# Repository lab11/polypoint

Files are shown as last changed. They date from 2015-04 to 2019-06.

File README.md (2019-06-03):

PolyPoint
=========

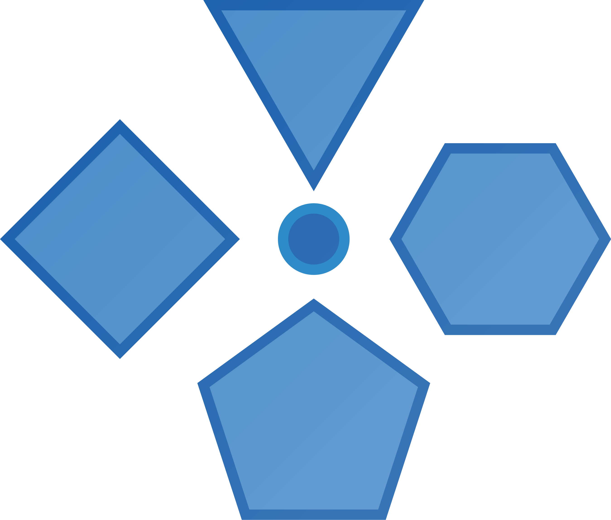
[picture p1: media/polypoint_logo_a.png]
PolyPoint


PolyPoint is a system for using ultra-wideband RF time-of-flight ranging to perform indoor localization.
It incorporates the DecaWave DW1000 for UWB packet transmission and timestamping
into a solder-on module that provides node-to-node ranges over an I2C interface.

Name
----

The name PolyPoint comes from the use of many polygons and shapes in the prototype design and the
desire to pinpoint where users are with the system.

Git Clone
---------

When cloning this repository, be absolutely sure to do

    git clone --recursive https://github.com/lab11/polypoint.git
    
so that you get the submodules as well. All of the supporting
libraries and build tools are in submodules for the various
hardware platforms used in this project.

Hardware
--------

The PolyPoint system is composed of several hardware pieces. At the core is the
TriPoint module which is a 1.25" on a side triangle that encompasses all of the
core ranging hardware and software. TriPoint has castellated edges and can be
soldered on to a carrier board, effectively as a ranging IC. TriTag is one such
carrier board designed to be the tag in the ranging system. It includes the
UWB antennas and a Bluetooth Low Energy radio plus a battery charging circuit.
TriTag is able to provide ranges to a mobile phone application.

### TriPoint

TriPoint includes the following components:

- DecaWave DW1000 UWB radio
- STM32F031G6U6 MCU
- RF switch

The MCU contains all the necessary code to run the DW1000 and the ranging
protocol.

### TriTag

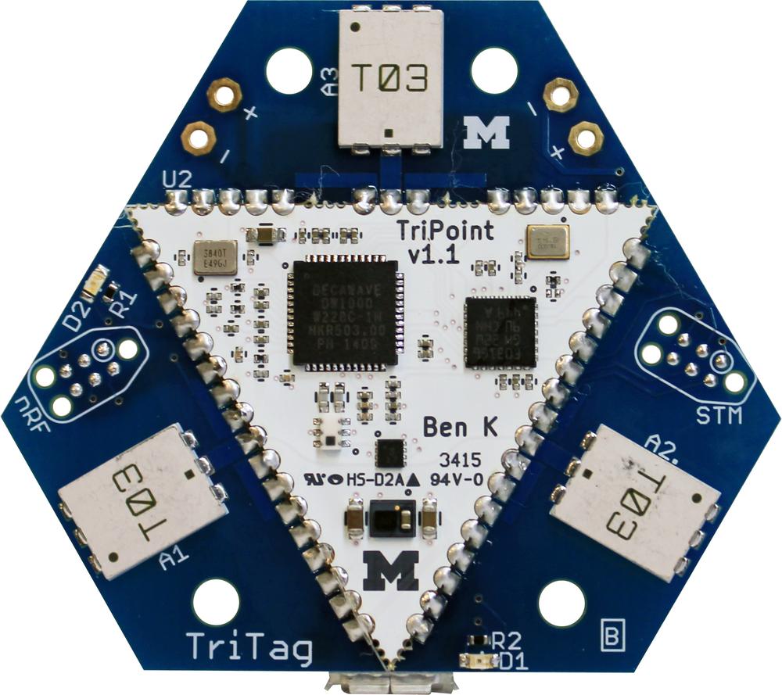
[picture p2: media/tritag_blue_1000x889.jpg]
TriTag
  

TriTag includes:

- The TriPoint module
- 3 UWB antennas
- nRF51822 BLE radio
- 3.3 V LDO
- Li-ion battery charger

TriTag is designed to be the tag to be localized in the system and connected
to a smartphone.

### TriDev

TriDev is a breakout and testing board for the TriPoint module.
It contains the same BLE hardware as TriTag, but also adds an FTDI
chip for issuing I2C commands over USB.

Software
--------

PolyPoint contains many software layers that run at various levels of
the system.

#### TriPoint

The core firmware that makes the drop-in TriPoint module work
includes all of the logic to implement two way ToF ranging
on top of the DecaWave DW1000 UWB radio. The firmware architecture
supports multiple "applications", or ranging algorithms, that can
be selected at runtime.

#### TriTag

The TriTag code implements a BLE application
that uses the TriPoint module as an I2C device and prov
a BLE service. It puts the TriTag hardware into TAG mode
and provides ranges over a BLE characteristic. 

#### Phone and BLE

The tools in the `/phone` directory interact with TriTag and read data
across the BLE interface.

----

## Academic Publications

The PolyPoint project has led to two academic publications, and an invited talk at HotWireless'16.
If you are interested in the theory behind the ranging protocol, please check out our publications:

 - **[SurePoint: Exploiting Ultra Wideband Flooding and Diversity to Provide Robust, Scalable, High-Fidelity Indoor Localization.](http://lab11.eecs.berkeley.edu/content/pubs/kempke16surepoint.pdf)** Benjamin Kempke, Pat Pannuto, Bradford Campbell, and Prabal Dutta. Proceedings of the 14th ACM Conference on Embedded Networked Sensor Systems (SenSys’16).
 - **[PolyPoint: Guiding Indoor Quadrotors with Ultra-Wideband Localization.](http://lab11.eecs.berkeley.edu/content/pubs/kempke15polypoint.pdf)** Benjamin Kempke, Pat Pannuto, and Prabal Dutta. 2015 ACM Workshop on Hot Topics in Wireless (HotWireless’15).
 
If you use PolyPoint or its derivatives, please use the following citation:

```bibtex
@inproceedings{kempke16surepoint,
	title = {{SurePoint}: Exploiting Ultra Wideband Flooding and Diversity to Provide Robust, Scalable, High-Fidelity Indoor Localization},
	booktitle = {Proceedings of the 14th ACM Conference on Embedded Networked Sensor Systems},
	series = {SenSys'16},
	year = {2016},
	month = {11},
	location = {Stanford, CA, USA},
	conference-url = {http://sensys.acm.org/2016/},
	author = {Kempke, Benjamin and Pannuto, Pat and Campbell, Bradford and Dutta, Prabal},
}
```

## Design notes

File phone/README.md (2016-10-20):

BLE Apps
========

This folder contains code for connecting to the BLE services provided
by the hardware.

tritag-summon
-------------

App for summon on mobile phones. See the readme in the folder.

tritag.js
---------

This is a script that runs with Node.js to get range estimates
from the TriTag device.

To use:

1. Install [Node.js](https://nodejs.org/en/download/)
2. Install noble:

        npm install noble

3. Run the script

        sudo node ./tritag.js

--------

The app can also be configured to post locations to a RESTful endpoint by providing a URL.
The `generate_test_data.js` provides simulation data for testing.

The packet format is:
```json
{
    "_meta": {
        "received_time":"2016-10-13T00:21:28.647Z",
        "device_id":"c0:98:e5:45:00:01",
        "device_type":"surepoint_tag"
        },
    "x":6.825641556121154,
    "y":7.267745259210209,
    "z":1.818158319382718
}
```

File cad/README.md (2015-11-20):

CAD Models
==========

A few designs including a case for TriTag.

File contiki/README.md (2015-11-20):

Deprecation Notice
==================

This folder is deprecated.

The original PolyPoint system as deployed for the 2015 Indoor Localization Competition
and evaluated for HotWireless'15 used this software. We have now moved away from the
2538 and Contiki to a bare-metal implementation on the STM32F.

The current software is in the polypoint/software directory.

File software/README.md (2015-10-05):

TriPoint Software
=================

This firmware runs on the triangular TriPoint module and performs the basis
for the PolyPoint ranging system. Ideally, each TriPoint will ship with
this firmware already installed.

The following steps demonstrate how to re-program TriPoints.

1. Get the arm-gcc compiler for your platform: https://launchpad.net/gcc-arm-embedded

2. In the `/firmware` folder, build the software:

        make

3. Programming the STM32F0 on TriPoint requires a JLink JTAG programmer:
https://www.segger.com/jlink-general-info.html, the JLink programming software:
https://www.segger.com/jlink-software.html, and a ARM JTAG to Tag-Connect
adapter:
https://github.com/lab11/nrf51-tools/tree/master/hardware/jlink_to_tag/rev_b or
https://www.segger.com/jlink-6-pin-needle-adapter.html.

4. Program the STM32F0, and set the ID:

        make flash ID=c0:98:e5:50:50:00:00:01
        
    If you have multiple JLink boxes attached to your computer:
    
        SEGGER_SERIAL=<segger id> make flash ID=c0:98:e5:50:50:00:00:01

I2C API
-------

The interface between the host and TriPoint is described in `firmware/API.md`.

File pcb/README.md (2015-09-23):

PolyPoint Hardware
==================

The PolyPoint system consists of several PCBs centered around TriPoint,
the core UWB ranging module.

1. **TriPoint**: Triangular module which contains all necessary hardware
for using the DecaWave DW1000. It has castellated headers so it can be
soldered onto a carrier board to add indoor localization functionality
to any device.

2. **TriTag**: Portable carrier board designed to be used as an indoor
localization tag. Has TriPoint on one side and a BLE radio on the other.

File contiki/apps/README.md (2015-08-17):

PolyPoint Apps
==============

The PolyPoint app has undergone a few significant revisions. To facilitate
parallel testing and development, it's been forked (copy a folder and go) a few
times.

* `pp_noslots_[common,tag,anchor]` -- This version removes the assumption of a
   fixed number of anchors. Anchors send their responses stochastically, varying
   the slot for each response. It also transmits the final measurement round on
   all three channels instead of just one.

* `pp_oneway_[common,tag,anchor]` -- This version revises the ranging protocol.
  The original protocol was `NUM_MESUREMENTS` * {Tag `--TAG_POLL-->` Anchor,
  `NUM_ANCHORS` * {Anchor `--ANC_RESP-->` Tag}} + {Tag `--TAG_FINAL-->` Anchor,
  `NUM_ANCHORS` * {Anchor `--ANC_FINAL-->` Tag}}. The revised protocol sends
  `NUM_MESUREMENTS` * {Tag `--TAG_POLL-->` Anchor}, `NUM_ANCHORS` * {Anchor
  `--ANC_FINAL-->` Tag}. This is `NUM_MESUREMENTS` * `NUM_ANCHORS` fewer packets.
  This version achieved an update rate of 20-30 Hz in practice.

* `polypoint_[common,tag,anchor]` -- This version split tags and anchors into
  two dedicated applications, with some common code. It uses the same
  ranging protocol as the previous version. It ups the UWB baud rate to
  6.2 Mbaud and tightens transmission timings to near minimum, largely by
  manually measuring the duration of each event. It adds an option to compute
  the 10th percentile estimate on the anchor during the ranging event,
  significantly reducing the length of the final anchor message and the amount
  of data the tag needs to offload. This app improved the update rate from
  about 0.25 Hz to 3 Hz, or up to 4.5 Hz with `ANC_FINAL_PERCENTILE_ONLY`.

* `dw1000_test` -- The app as run during the Microsoft Indoor Localization
  Competition 2015. This was a unified application, with `#define`'s selecting
  anchors versus tags.

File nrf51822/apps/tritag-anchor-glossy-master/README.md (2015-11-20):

Anchor BLE Application for TriTag
=================================

This app run on TriTag but puts it in anchor mode. On boot, the app sends the I2C commands
to put the TriPoint module into anchor mode, and doesn't do much else.

It is designed to be a stop-gap before we have dedicated anchor hardware.

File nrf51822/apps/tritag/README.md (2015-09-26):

TriTag BLE App
==============

This apps provides the BLE interface for the TriTag localization tag.

Programming
-----------

    SERGGER_SERIAL=xxxxxxxxx make flash ID=c0:98:e5:45:00:01

Advertisement
-------------

TriTag advertises according to the [Eddystone](https://github.com/google/eddystone)
protocol. It works with our [Summon](https://github.com/lab11/summon) project
that provides a browser-based UI for BLE devices.

Services
--------

TriTag provides a service for all ranging operations. Characteristics in that service
provide control and data for the interface with TriPoint.

- **Ranging Service**: UUID: `2e5d5e39-3152-450c-90ee-3fa29c868cd6`
  - **Raw Data Characteristic**: Short UUID: `3153`. Provides direct access to the data published from the
  TriPoint when the TriPoint interrupts the host. See `API.md` for a description of
  the possible data returned.
  - **Ranging Start/Stop Characteristic**: Short UUID: `3154`. Write a 0 to this to stop the ranging
  operation. Write a 1 to start ranging.
  - **Calibration Config Characteristic**: Short UUID: `3159`. Writing to this characteristic
  puts the node in calibration mode. The value written to this characteristic assigns
  the calibration index to the TriPoint. Valid indices are 0,1,2. The node with index
  0 will immediately start the calibration procedure and should be assigned last.

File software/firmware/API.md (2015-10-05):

Tripoint API
============

This defines the I2C interface for the TriPoint module. TriPoint is an
I2C slave.

```
I2C Address: 0x65
```

Commands
--------

These commands are set as a WRITE I2C command from the host to the TriPoint. Each
write command starts with the opcode.

| Opcode | Byte | Type | Description |
| --- | ---- | ---- | --- |
| `INFO` | 0x01 | W/R  | Get information about the module. |
| `CONFIG` | 0x02 | W | Configure options. Set tag/anchor. |
| `READ_INTERRUPT` | 0x03 | W/R  | Ask the chip why it asserted the interrupt pin. |
| `DO_RANGE` | 0x04 | W | If not doing periodic ranging, initiate a range now. |
| `SLEEP` | 0x05 | W | Stop all ranging and put the device in sleep mode. |
| `RESUME` | 0x06 | W | Restart ranging. |
| `SET_LOCATION` | 0x07 | W | Set location of this device. Useful only for anchors.  |
| `READ_CALIBRATION` | 0x08 | W/R  | Read the stored calibration values from this TriPoint. |

#### `INFO`

Write:
```
Byte 0: 0x01  Opcode
```

Read:
```
Byte 0: 0xB0
Byte 1: 0x1A
Byte 2: version
```

#### `CONFIG`

```
Byte 0: 0x02  Opcode

Byte 1:      Config 1
   Bits 4-7: Reserved
   Bits 2-4: Application select.
             Choose which ranging application to execute on the TriPoint.
               0 = Default
               1 = Calibration
               2-7 = reserved
   Bits 0-1: Anchor/Tag select.
               0 = tag
               1 = anchor
               2 = reserved
               3 = reserved

IF TAG:
Byte 2:
   Bits 4-7: Reserved.
   Bit 3:    Sleep settings.
             Configure if TriPoint should sleep the DW1000 between ranging
             events.
               0 = Do not sleep.
               1 = Enter sleep between ranging events.
   Bits 1-2: Update mode.
             Configure if the module should periodically get new locations
             or if it should get locations on demand.
               0 = update periodically
               1 = update only on demand
               2 = reserved
               3 = reserved
   Bit 0:    Report locations or ranges.
             Configure if the module should report raw ranges or a computed
             location. NOTE: The module may need to offload the location
             computation.
               0 = return ranges
               1 = return location

Byte 3:      Location update rate.
             Specify the rate at which the module should get location updates.
             Specified in multiples of 0.1 Hz. 0 indicates as fast as possible.

IF ANCHOR:
   TODO

IF CALIBRATION:
Byte 2:      Calibration node index.
             The index of the node in the calibration session. Valid values
             are 0,1,2. When a node is assigned index 0, it automatically
             starts the calibration round.

```

### Both TAG and ANCHOR Commands

#### `READ_INTERRUPT`

Write:
```
Byte 0: 0x03  Opcode
````

Read:
```
Byte 0: Length of the following message.

Byte 1: Interrupt reason
  1 = Ranges to anchors are available
  2 = Calibration data

IF byte1 == 0x1:
Byte 2: Number of ranges.
Bytes 3-n: 8 bytes of anchor EUI then 4 bytes of range in millimeters.

IF byte1 == 0x2:
Bytes 2-3:   Round number
Bytes 4-8:   Round A timestamp. TX/RX depends on which node index this node is.
Bytes 9-12:  Diff between Round A timestamp and Round B timestamp.
Bytes 13-16: Diff between Round B timestamp and Round C timestamp.
Bytes 17-20: Diff between Round C timestamp and Round D timestamp.

TODO
```

#### `SLEEP`

Stop all ranging and put the module into sleep mode.
```
Byte 0: 0x05  Opcode
```

#### `RESUME`

If the module is in SLEEP mode after a `SLEEP` command, this will resume the
previous settings.
```
Byte 0: 0x06  Opcode
````

#### `READ_CALBRATION`

Read the stored calibration values off of the device.

Write:
```
Byte 0: 0x08  Opcode
````

Read:
```
Bytes 0-1:   Channel 0, Antenna 0 TX+RX delay
Bytes 2-3:   Channel 0, Antenna 1 TX+RX delay
Bytes 4-5:   Channel 0, Antenna 2 TX+RX delay
Bytes 6-7:   Channel 1, Antenna 0 TX+RX delay
Bytes 8-9:   Channel 1, Antenna 1 TX+RX delay
Bytes 10-11: Channel 1, Antenna 2 TX+RX delay
Bytes 12-13: Channel 2, Antenna 0 TX+RX delay
Bytes 14-15: Channel 2, Antenna 1 TX+RX delay
Bytes 16-17: Channel 2, Antenna 2 TX+RX delay
```

### TAG Commands

#### `DO_RANGE`

Initiate a ranging event. Only valid if tag is in update on demand mode.

```
Byte 0: 0x04  Opcode
```

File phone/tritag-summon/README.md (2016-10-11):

TriTag Summon App
=================

Copy everything in this folder to the URL where the TriTag eddystone
beacon points to (except for init_cordova.sh).

To rebuild everything:

    ./init_cordova.sh

---

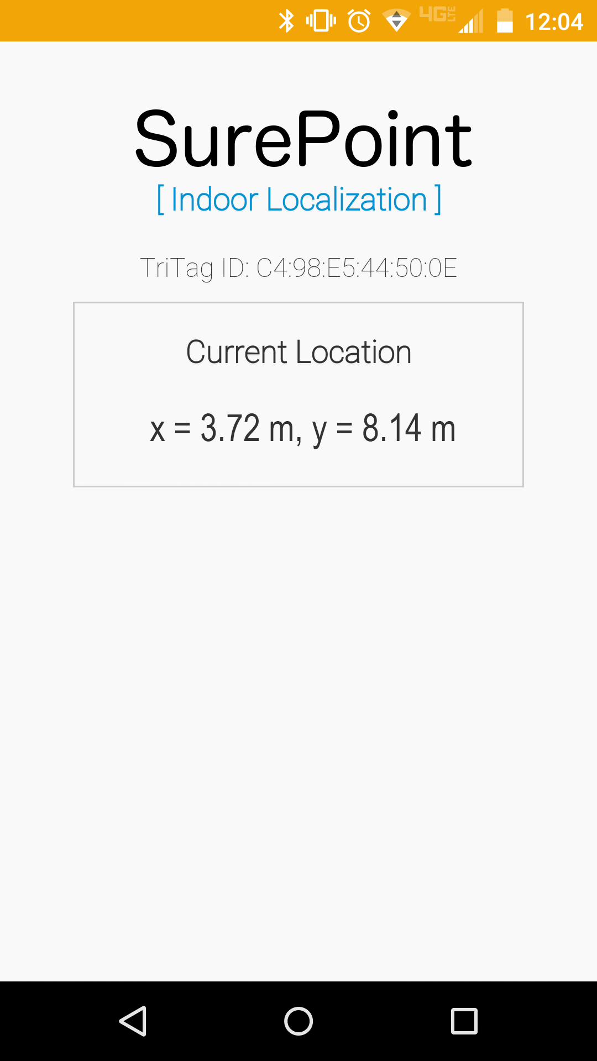
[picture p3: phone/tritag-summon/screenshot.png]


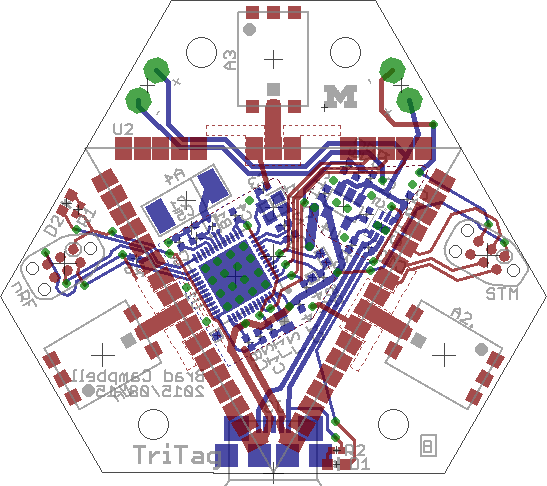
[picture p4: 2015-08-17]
pcb/tritag/rev_b/tritag_pcb.png

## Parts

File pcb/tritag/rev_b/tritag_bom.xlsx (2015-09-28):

Qty | Value | Device | Package | Parts | Description | DIGIKEY | MOUSER | NEWARK | RICHARDSON_RFPD
3 | TAIYO-YUDEN-AH086M | TAIYO-YUDEN-AH086M | TAIYO-YUDEN-AH086M | A1, A2, A3 | UWB Antenna - 3.1-8GHz | 587-2204-1-ND
1 | FRACTUS-2.4GHZ-FR05-S1-N-0-102 | FRACTUS-2.4GHZ-FR05-S1-N-0-102 | FRACTUS-ANTENNA-FR05-S1-N-0-102 | A4 | Fractus Compact Reach XtendTM chip antenna is engineered specifically for Bluetooth, |  |  |  | FR05-S1-N-0102B
1 | BAL-NRF01D3 | BAL-NRF01D3 | BAL-NRF01D3 | B1 | 50 ohm nominal input / conjugate match balun to nRF51422-QFAA, | 497-13637-1-ND | 511-BAL-NRF01D3
1 | 0.8pF | CAPACITOR | 0402_CAP | C1 | 0402 Capacitor | 490-6269-1-ND
2 | 12pF | CAPACITOR | 0402_CAP | C2, C3 | 0402 Capacitor | 490-6197-1-ND
1 | 1nF | CAPACITOR | 0402_CAP | C4 | 0402 Capacitor | 490-1303-1-ND
1 | 2.2nF | CAPACITOR | 0402_CAP | C5 | 0402 Capacitor | 490-5419-1-ND
1 | 10nF | CAPACITOR | 0402_CAP | C15 | 0402 Capacitor | 445-1260-1-ND
1 | 47nF | CAPACITOR | 0402_CAP | C6 | 0402 Capacitor | 445-1264-1-ND
3 | 0.1uF | CAPACITOR | 0402_CAP | C7, C8, C9 | 0402 Capacitor | 490-1318-1-ND
2 | 1uF | CAPACITOR | 0402_CAP | C12, C13 | 0402 Capacitor | 445-4998-1-ND
3 | 4.7uF | CAPACITOR | 0402_CAP | C10, C11, C14 | 0402 Capacitor | 445-5947-1-ND
1 | GREEN | LED0603 | LED-0603 | D1 | LEDs | 160-1446-1-ND
1 | BLUE | LED0603 | LED-0603 | D2 | LEDs | 160-1837-1-ND
1 | MICRO_USB_B_HIROSE_ZX62-B-5PA(11) | MICRO_USB_B_HIROSE_ZX62-B-5PA(11) | USB_MICRO_B-HIROSE-ZX62-B-5PA(11) | J3 | Connector Receptacle USB - micro B 2.0 5 Position Surface Mount, Right Angle, Horizontal | H11634CT-ND | 798-ZX62-B-5PA11 | 86P8793
1 | 15nH | INDUCTOR0402 | 0402_CAP | L1 | INDUCTOR HI FREQ 15NH 5% 0402 | 587-1521-1-ND
1 | 10uH | INDUCTOR0603 | 0603_CAP | L2 | INDUCTOR 10UH 50MA 0603 | 490-4025-1-ND
2 | 1k | RESISTOR0402_RES | 0402_RES | R1, R2 | Resistor | RHM1.0KCECT-ND
1 | 560 | RESISTOR0402_RES | 0402_RES | R3 | Resistor | RHM560CDCT-ND
2 | 10k | RESISTOR0402_RES | 0402_RES | R4, R5 | Resistor | RHM10.0KCDCT-ND
1 | 12k | RESISTOR0402_RES | 0402_RES | R6 | Resistor | RHM12.0KCDCT-ND
1 | 2.2M | RESISTOR0402_RES | 0402_RES | R7 | Resistor | 541-2.20MLCT-ND
1 | 10M | RESISTOR0402_RES | 0402_RES | R8 | Resistor | RHM10MBICT-ND
1 | NRF51822QF | NRF51822QF | QFN-48-6MM | U1 | Multiprotocol Bluetooth® 4.0 low energy/2.4 GHz RF SoC | 1490-1042-1-ND | 949-NRF51822-QFAB-R7
1 | TRIPOINT | TRIPOINT | TRIPOINT | U2 | UWB Ranging Module
1 | LTC4065 | LTC4065 | DFN-6/2MM | U3 | LION/LIPO Battery Charging IC Low current | LTC4065LEDC#TRMPBFCT-ND
1 | MAX8887EZK33+T | MAX8887EZK33+T | SOT-23-5 | U4 | IC REG LDO 3.3V 0.3A TSOT23-5 | MAX8887EZK33+TCT-ND
1 | 16MHz | TXC-8Y | TXC-8Y | X1 | CRYSTAL 16MHZ 8PF SMD | 887-2003-1-ND

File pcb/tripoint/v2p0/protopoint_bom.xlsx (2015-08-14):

Reference | Quantity | Value | Footprint | ManPartNo | Digikey | DigiReel | Alternate
C34 | 1 | 1.2pF | Capacitors_SMD:C_0201 | GRM0335C1H1R2CA01D | 490-6119-1-ND | 490-6119-6-ND
C1, C3, C11 | 3 | 10pF | Capacitors_SMD:C_0201 | GRM0335C1E100JA01D | 490-8607-1-ND | 490-8607-6-ND
C25, C26, C32, C36 | 4 | 12pF | Capacitors_SMD:C_0201 | GRM0335C1E120JA01D | 490-3144-1-ND | 490-3144-6-ND
C37, C38 | 2 | 12pF | Capacitors_SMD:C_0402 | GRM0335C1E120JA01D | 490-5924-1-ND | 490-5924-6-ND
C35 | 1 | 18pF | Capacitors_SMD:C_0201 | GRM0335C1H180JA01D | 490-6117-1-ND | 490-6117-6-ND
C30 | 1 | 27pF | Capacitors_SMD:C_0201 | GRM0335C1E270JA01D | 490-3150-1-ND | 490-3150-6-ND
C8, C10, C17 | 3 | 100pF | Capacitors_SMD:C_0201 | GRM0335C1E101JA01D | 490-3160-1-ND | 490-3160-6-ND
C5, C7 | 2 | 330pF | Capacitors_SMD:C_0201 | GRM033R71E331KA01D | 490-3178-1-ND | 490-3178-6-ND
C31 | 1 | 820pF | Capacitors_SMD:C_0201 | GRM033R71E821KA01D | 490-3183-1-ND | 490-3183-6-ND
C12 | 1 | 0.01uF | Capacitors_SMD:C_0201 | GRM033R71A103KA01D | 490-3194-1-ND | 490-3194-6-ND
C2, C6, C9, C13, C14, C15, C16, C18, C19, C20, C21, C23, C24, C27, C28, C29 | 16 | 0.1uF | Capacitors_SMD:C_0201 | GRM033R61A104KE15D | 490-5881-1-ND | 490-5881-6-ND
C4, C22 | 2 | 4.7uF | Capacitors_SMD:C_0603 | GRM188F51A475ZE20D | 490-3302-1-ND | 490-3302-6-ND
C33 | 1 | 10uF | Capacitors_SMD:C_0603 | GRM188R61C106MA73D | 490-7201-1-ND | 490-7201-6-ND
R4 | 1 | 270 | Resistors_SMD:R_0201 | ERJ-1GEF2700C | P270ABCT-ND | P270ABDKR-ND
R1 | DNP | 11k | Resistors_SMD:R_0201 | ERJ-1GEF1102C | P11.0KABCT-ND | P11.0KABDKR-ND
R2, R5 | 2 | 11k | Resistors_SMD:R_0201 | ERJ-1GEF1102C | P11.0KABCT-ND | P11.0KABDKR-ND
R3 | 1 | 16k | Resistors_SMD:R_0201 | ERJ-1GEF1602C | P16.0KABCT-ND | P16.0KABDKR-ND
T1 | 1 | HHM1595A1 | polypoint:HHM1595A1 | HHM1595A1 | 445-3387-1-ND | 445-3387-6-ND
U1 | 1 | STM32F031G6U6 | polypoint:UFQFPN-28 | STM32F031G6U6 | 497-13620-ND
U2 | 1 | LXDC2HL | polypoint:LXDC2HL | LXDC2HL18A-052 | 490-5791-1-ND | 490-5791-6-ND
U3 | 1 | DW1000 | polypoint:QFN-48-EP-6x6mm | DW1000-I-TR13 | 1479-1001-1-ND | 1479-1001-6-ND
U4 | 1 | SKY13317 | polypoint:MLPQ-UT-8-1.5X1.5mm | SKY13317-373LF | 863-1056-1-ND | 863-1056-6-ND
X1 | 1 | CRYSTAL_SMD_4 | polypoint:FA-128 | FA-20H 16.0000MF10Z-AJ3 | SER3913CT-ND | SER3913DKR-ND | 644-1059-6-ND
X2 | 1 | CRYSTAL_SMD_4 | polypoint:FA-128 | FA-20H 38.4000MF10Z-AS3 | SER3631CT-ND | SER3631DKR-ND

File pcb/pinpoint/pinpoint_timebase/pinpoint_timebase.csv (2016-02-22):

Reference | Quantity | Value | Footprint | Datasheet | ManPartNo | DistPartNo
C20 | 1 | 4.7uF | Capacitors_SMD:C_0805 |  | GRM21BR61H475KE51L | 490-10751-1-ND
C21 C22 | 2 | 10uF | Capacitors_SMD:C_0805 |  | GRM21BR61C106KE15K | 490-6473-1-ND
C1 C10 C11 C12 C13 C14 C15 C16 C17 C18 C19 C2 C23 C24 C25 C26 C27 C28 C29 C3 C30 C4 C5 C6 C7 C8 C9 | 27 | 0.1uF | Capacitors_SMD:C_0402 |  | GRM155R62A104KE14D | 490-10458-1-ND
CON1 | 1 | BARREL_JACK | Connect:BARREL_JACK |  | PJ-002B | CP-002B-ND
D1 | 1 | D_Schottky | Diodes_SMD:SOD-323 |  | BSR106WS-TP | BSR106WS-TPMSCT-ND
J1 J2 J3 J4 J5 | 5 | RJ45 | polypoint:RJ45_8 |  | A-2004-2-4-LPS-N-R | AE10387-ND
J6 | 1 | TC2030-JLINK-NL | polypoint:TC2030
L1 | 1 | 22uH | polypoint:NR6045 |  | NR6045T220M | 587-2082-1-ND
P1 P6 | 2 | CONN_01X03 | Pin_Headers:Pin_Header_Straight_1x03
P10 P2 P3 P4 P5 P7 P8 P9 | 8 | SMA | polypoint:SMA_EDGE |  | CONSMA003.062 | CONSMA003.062-ND
R1 R2 | 2 | 100 | Resistors_SMD:R_0402 |  | ERJ-2RKF1000X | P100LCT-ND
R10 | 1 | 9.53K | Resistors_SMD:R_0402 |  | ERJ-2RKF9531X | P9.53KLCT-ND
R3 R4 | 2 | 150 | Resistors_SMD:R_0402 |  | ERJ-2RKF1500X | P150LCT-ND
R5 | 1 | 130 | Resistors_SMD:R_0402 |  | ERJ-2RKF1300X | P130LCT-ND
R6 | 1 | DNP | Resistors_SMD:R_0402
R7 | 1 | 11K | Resistors_SMD:R_0402 |  | ERJ-2RKF1102X | P11.0KLCT-ND
R8 | 1 | 4.7K | Resistors_SMD:R_0402 |  | ERJ-2RKF4701X | P4.70KLCT-ND
R9 | 1 | 49.9K | Resistors_SMD:R_0402 |  | ERJ-2RKF4992X | P49.9KLCT-ND
U1 | 1 | SN74AVC1T45 | TO_SOT_Packages_SMD:SC-70-6 |  | SN74AVC1T45DCKR | 296-17992-1-ND
U11 | 1 | NCP1117 | TO_SOT_Packages_SMD:SOT-223 |  | NCP1117ST33T3G | NCP1117ST33T3GOSCT-ND
U10 U2 | 2 | 551S | Housings_SOIC:SOIC-8_3.9x4.9mm_Pitch1.27mm |  | 551SDCGI | 800-2901-5-ND
U3 U9 | 2 | ICS8545 | Housings_SSOP:TSSOP-20_4.4x6.5mm_Pitch0.65mm |  | 8545BGLF | 800-2074-ND
U4 | 1 | AOZ1282CI | TO_SOT_Packages_SMD:SOT-23-6 |  | AOZ1282CI | 785-1613-1-ND
U5 | 1 | SI5317 | polypoint:QFN-36_1EP_6x6mm |  | SI5317D-C-GM | 336-1920-ND
U6 | 1 | 7N-XX.XXXMBP-T | polypoint:7N-xx.xxxMBP-T |  | 7N-38.400MBP-T | 887-2506-1-ND
U7 | 1 | STM32F031G6U6 | polypoint:UFQFPN-28 |  | STM32F031G6U6 | 497-13620-ND
U8 | 1 | 830S21 | Housings_SOIC:SOIC-8_3.9x4.9mm_Pitch1.27mm |  | 830S21AMI-01LF | 800-3330-5-ND

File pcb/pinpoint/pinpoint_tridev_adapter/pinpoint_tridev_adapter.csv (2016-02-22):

Reference | Quantity | Value | Footprint | Datasheet | ManPartNo | DistPartNo
C1 C6 C7 C8 | 4 | 0.1uF | Capacitors_SMD:C_0402 |  | GRM155R62A104KE14D | 490-10458-1-ND
C2 C3 | 2 | 4.7uF | Capacitors_SMD:C_0805 |  | GRM21BR61H475KE51L | 490-10751-1-ND
C4 | 1 | 10uF | Capacitors_SMD:C_0805 |  | GRM21BR61C106KE15K | 490-6473-1-ND
C5 | 1 | 10nF | Capacitors_SMD:C_0402 |  | GRM155R71H103KA88D | 490-4516-1-ND
D1 | 1 | D_Schottky | Diodes_SMD:SOD-323 |  | BSR106WS-TP | BSR106WS-TPMSCT-ND
J1 | 1 | RJ45 | polypoint:RJ45_8 |  | A-2004-2-4-LPS-N-R | AE10387-ND
L1 | 1 | 22uH | polypoint:NR6045 |  | NR6045T220M | 587-2082-1-ND
P1 P3 | 2 | SMA | polypoint:SMA_EDGE |  | CONSMA003.062 | CONSMA003.062-ND
P4 | 1 | CONN_01X06 | Pin_Headers:Pin_Header_Straight_1x06
P2 P5 | 2 | CONN_01X03 | Pin_Headers:Pin_Header_Straight_1x03
P6 | 1 | CONN_02X10 | Pin_Headers:Pin_Header_Straight_2x10 |  | SSQ-110-03-T-D | SAM1204-10-ND
P7 | 1 | CONN_01X02 | Pin_Headers:Pin_Header_Straight_1x02
R1 | 1 | 4.7K | Resistors_SMD:R_0402 |  | ERJ-2RKF4701X | P4.70KLCT-ND
R2 R5 | 2 | 100 | Resistors_SMD:R_0402 |  | ERJ-2RKF1000X | P100LCT-ND
R3 | 1 | 49.9K | Resistors_SMD:R_0402 |  | ERJ-2RKF4992X | P49.9KLCT-ND
R4 | 1 | 9.53K | Resistors_SMD:R_0402 |  | ERJ-2RKF9531X | P9.53KLCT-ND
U1 | 1 | AOZ1282CI | TO_SOT_Packages_SMD:SOT-23-6 |  | AOZ1282CI | 785-1613-1-ND
U2 | 1 | MAX8877 | TO_SOT_Packages_SMD:SOT-23-5 |  | MAX8877EUK33+T | MAX8877EUK33+CT-ND
U3 U4 | 2 | 830S21 | Housings_SOIC:SOIC-8_3.9x4.9mm_Pitch1.27mm |  | 830S21AMI-01LF | 800-3330-5-ND

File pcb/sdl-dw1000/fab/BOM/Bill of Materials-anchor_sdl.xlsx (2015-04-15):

Designator | DistPartNo | Footprint | ManPartNo | Quantity
C1 | 587-1441-1-ND | 0603 | LMK107BJ475KA-T | 1
C2 | 587-3412-1-ND | 0603 | LMK107BBJ106MAHT | 1
C3 | 490-5869-1-ND | 0402 | GRM1555C1H270JA01D | 1
C4 | 490-6209-1-ND | 0402 | GRM1555C1H1R2BA01D | 1
C5 | 490-3250-1-ND | 0402 | GRM155R71H821KA01D | 1
C6 | 490-5858-1-ND | 0402 | GRM1555C1H180JA01D | 1
C7, C9, C11, C12, C13, C14 | 490-3113-1-ND | 0402 | GJM1555C1H100JB01D | 6
C8, C10, C34, C35 | 490-3115-1-ND | 0402 | GJM1555C1H120JB01D | 4
C15, C16 | 490-1295-1-ND | 0402 | GRM1555C1H331JA01D | 2
C17 | 490-1312-1-ND | 0402 | GRM155R71E103KA01D | 1
C18, C19, C20, C21, C23, C25, C27, C28, C29, C30, C31, C32, C33 | 490-3261-1-ND | 0402 | GRM155R71C104KA88D | 13
C22 | 1276-2420-1-ND | 0805 | CL21A476MQCLRNC | 1
C24 | 445-8023-1-ND | 0402 | C1005X5R1A475M050BC | 1
C26 | 490-5922-1-ND | 0402 | GRM1555C1H101JA01D | 1
P1, P3 |  | SAM_FTSH_2_4 |  | 2
P2, P4 |  | SAM_CLP_2_4 |  | 2
P5, P6, P7 | CONSMA003.062-ND | SMA_EDGE | CONSMA003.062 | 3
P8 |  | HDR1X3 |  | 1
P9, P10 |  | HDR2X3 |  | 2
R1 | P11.0KLCT-ND | 0402 | ERJ-2RKF1102X | 1
R2 | P16.0KLCT-ND | 0402 | ERJ-2RKF1602X | 1
R3 | P270LCT-ND | 0402 | ERJ-2RKF2700X | 1
T1 | 445-3387-1-ND | HHM 0805 | HHM1595A1 | 1
U1 | 490-5791-1-ND | LXDC2HL | LXDC2HL18A-052 | 1
U2 | 1479-1001-1-ND | 48QFN-EP | DW1000-I-TR13 | 1
U3 | 863-1056-1-ND | MLPQ-UT-8 | SKY13317-373LF | 1
X1 | SER3631CT-ND | FA-20H | FA-20H 38.4000MF10Z-AS3 | 1

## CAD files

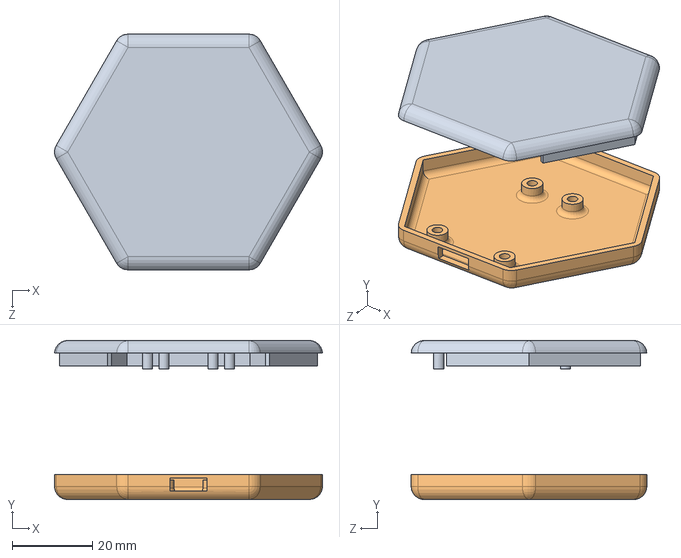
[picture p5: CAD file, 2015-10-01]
cad/tritag-case/tritag_case.SLDASM
66.6 x 39.5 x 58.6 mm
tritag_case_top
tritag_case_bottom

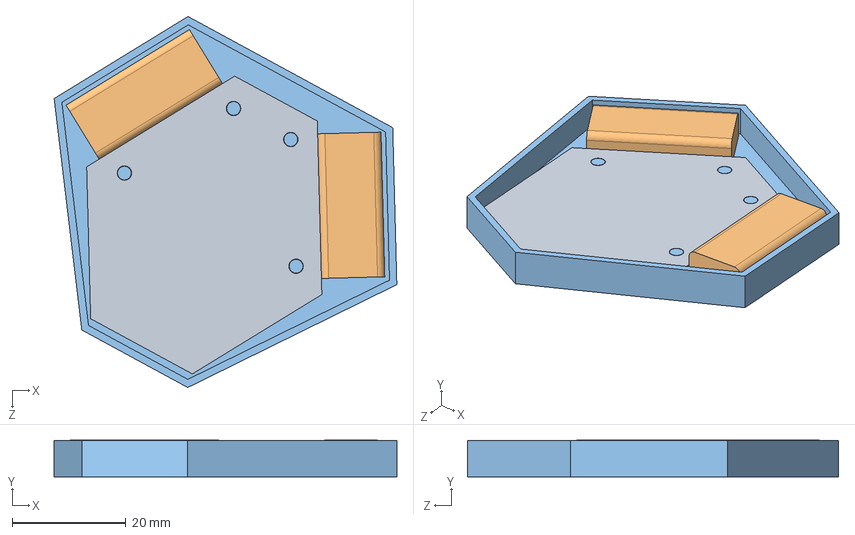
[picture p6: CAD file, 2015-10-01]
cad/tritag-board/device.SLDASM
60.2 x 6.41 x 65.1 mm
pcb
battery_110mAh x 2
case_bottom

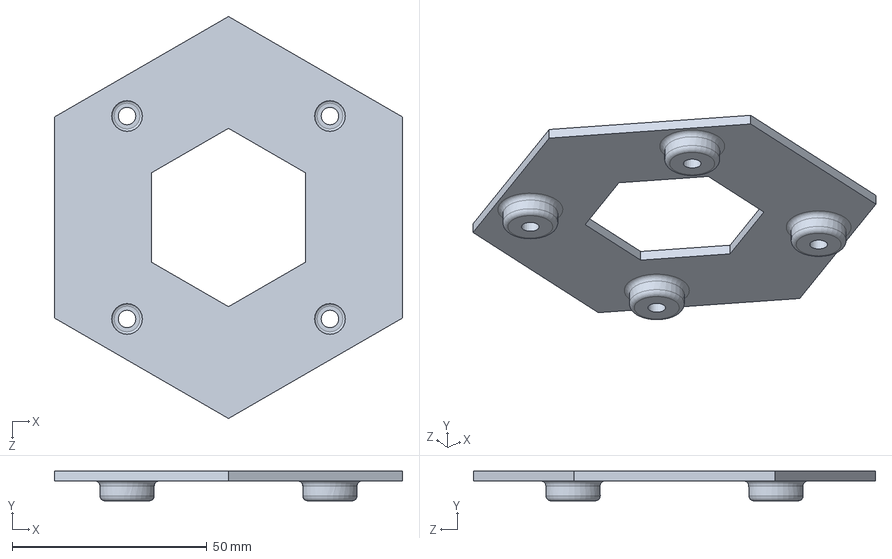
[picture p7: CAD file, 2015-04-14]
cad/mount/backplate_hexagon.SLDPRT
89.3 x 7.62 x 103.2 mm

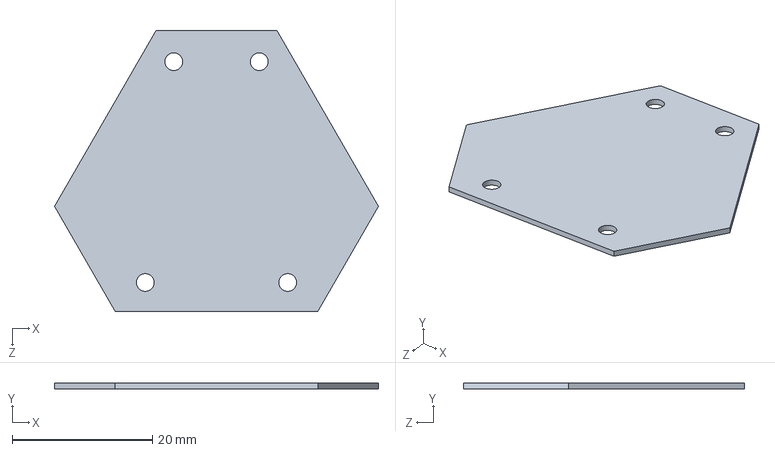
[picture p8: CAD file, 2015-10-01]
cad/tritag-board/board_2d.SLDPRT
46.2 x 0.8 x 40.0 mm

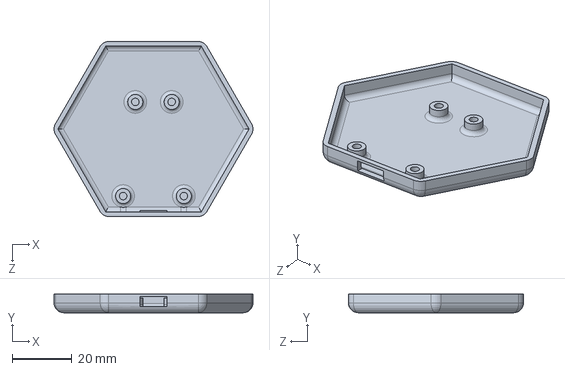
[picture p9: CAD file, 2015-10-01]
cad/tritag-case/tritag_case_bottom.SLDPRT
66.6 x 6.22 x 58.6 mm

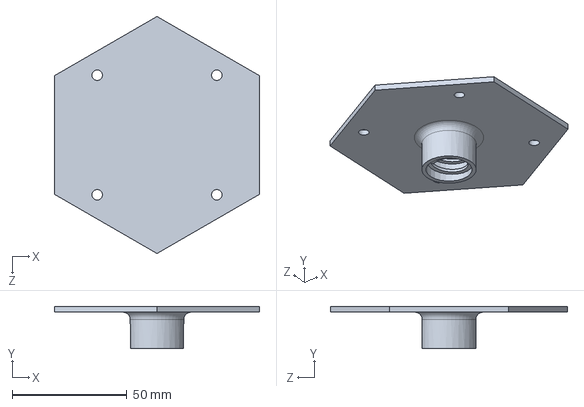
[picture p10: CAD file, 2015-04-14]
cad/mount/staff.SLDPRT
89.3 x 18.4 x 103.2 mm

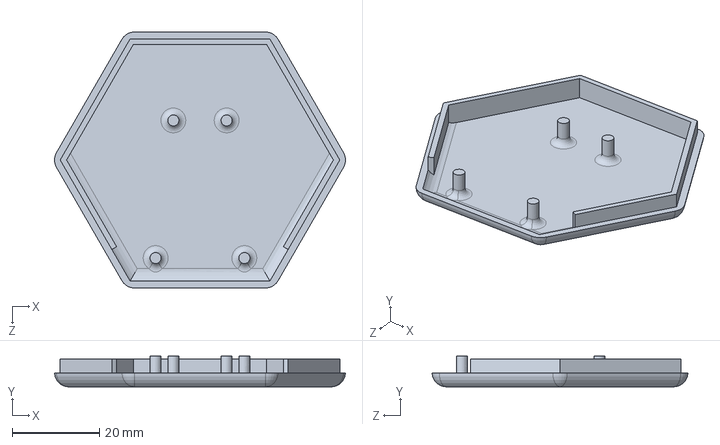
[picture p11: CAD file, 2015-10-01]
cad/tritag-case/tritag_case_top.SLDPRT
66.6 x 7.05 x 58.6 mm

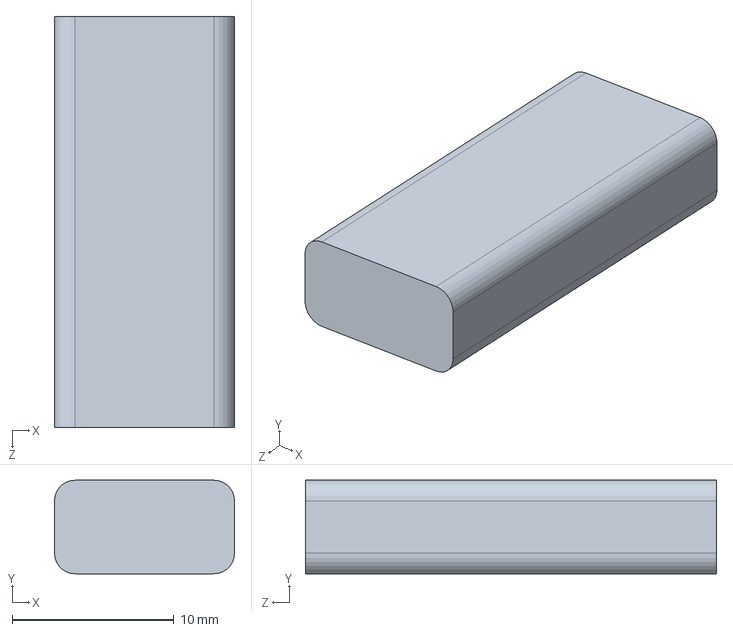
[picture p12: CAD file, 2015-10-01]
cad/tritag-board/battery_110mAh.SLDPRT
11.1 x 5.78 x 25.4 mm

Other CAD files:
cad/mount/polypoint_backplate_hexagon.STL
cad/tritag-board/outline.SLDPRT
cad/tritag-board/pcb.SLDPRT
cad/mount/backplate_hexagon.STL
cad/mount/staff.STL
cad/tritag-case/tritag_case_bottom.STL
cad/tritag-case/tritag_case_top.STL

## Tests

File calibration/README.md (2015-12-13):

Calibration
===========

We need to calibrate each TriPoint module to account for unique TX and RX
delays with DW1000 radios.

Process
-------

Calibration requires three TriPoint nodes. The nodes need to placed at
well-known distances from each other. The calibration scripts currently
assume that nodes are placed in a triangle each 1 m apart.

The TriPoint software includes the code needed to run calibration. To do
calibration with TriTag or TriTag compatible hardware, flash the `tritag`
nRF51822 BLE application on the TriTag. Then, putting
the node in calibration mode requires writing the calibration node index
to the `0x3159` characteristic. There are three "roles" (0,1,2) that nodes
can be assigned during calibration. Calibration roles are set by writing
one of 0, 1, or 2 to the `0x3159` characteristic. Role 0 must be written
last, as calibration will start once this role is assigned.

In practice, do this:

1. Install [node](https://nodejs.org/en/download/) first. Version 2.0+ should work.
Then install the dependencies:

        # In the calibration folder
        npm install

1. Make noble run without sudo:

        sudo setcap cap_net_raw+eip $(eval readlink -f `which node`)

2. Collect the data from each node:

        node ./calibration_log.js

    Make sure there are only 3 nodes on during calibration.

3. Process the data into a single file

        ./calibration_condense.py YYYY-MM-DD_HH-MM-SS

4. Compute the calibration values for each node involved and add the
results to the main calibration file.

        ./calibration_compute.py tripoint_calibration_YYYY-MM-DD_HH-MM-SS.condensed

5. When flashing the TriPoint firmware, the build system will check
`tripoint_calibration.data` for calibration constants and use those
if they exist.

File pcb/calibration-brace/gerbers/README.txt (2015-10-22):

Material: FR4
Layers: 2
PCB Thickness: 0.062"
Layer Thickness: 1 oz
Surface Finish: Tin/Lead
Solder Mask: Green (2 side)

Layer Mapping:
Top Mask: calibration-brace-F_Mask.gbr
Top Copper: calibration-brace-F_Cu.gbr
Bottom Copper: calibration-brace-B_Cu.gbr
Bottom Mask: calibration-brace-B_Mask.gbr
Board Outline: calibration-brace-Edge_Cuts.gbr
NC Drill File: calibration-brace.drl

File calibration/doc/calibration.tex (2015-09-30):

\documentclass{article}

\usepackage[top=.75in, bottom=.75in]{geometry}

\usepackage{amsmath}
\usepackage{graphicx}
\usepackage{xcolor}

\begin{document}

\newcommand{\tda}[1]{\textcolor{red}{#1}}
\newcommand{\tdb}[1]{\textcolor{orange}{#1}}
\newcommand{\tdc}[1]{\textcolor{blue}{#1}}
\newcommand{\unk}[1]{\textcolor{red}{#1}}
\newcommand{\der}[1]{\textcolor{orange}{#1}}
\newcommand{\off}[2]{\textnormal{\emph{Off}}_{#1\rightarrow#2}}

\section*{Setup:} Assume 3 polypoint tags (A, B, C), all 1~m from each other.

\begin{itemize}
  \item $t_A$ = tx delay for tag A (unknown)
  \item $r_A$ = rx delay for tag A (unknown)
  \item $\lambda$ = time of flight for 1~m ($\lambda = \frac{1}{c}\times\textnormal{\texttt{DWT\_TIME\_UNITS}}$)
  \item $\epsilon$ = precise delay before sending the next packet (i.e.\ 5\,ms)
\end{itemize}

The goal is to determine the calibration factor for a tag, $cal_A = t_A + r_A$.

\section*{Protocol:}

The following sequence will recover the $cal_C$. Note that timestamps from
local clocks are not synchronized, nor can the clocks be assumed to be running
at exactly the same speed.

\bigskip

\noindent
\begin{minipage}{.35\textwidth}
  \begin{enumerate}
    \item Tag A sends a packet
    \item Tag C sends a packet after $\epsilon$
    \item Tag C sends a packet after $\epsilon$
  \end{enumerate}
\end{minipage}%
~~~~~%
\begin{minipage}{.65\textwidth}
  
\end{minipage}

\begin{align}
  BRX1 &= ATX1 + t_A + \lambda + r_B \\
  BRX2 &= ATX1 + t_A + \lambda + r_C + \epsilon_C + t_C + \lambda + r_B \\
  BRX2-BRX1 = \Delta_B &= r_C + t_C + \epsilon_C + \lambda \\
  ~\nonumber\\
  k_{C\rightarrow B} &= \frac{BRX3-BRX2}{CTX3-CTX2} \\
  ~\nonumber\\
  r_C + t_C &= \Delta_B - \epsilon_C \times k_{C\rightarrow B} - \lambda
\end{align}

\end{document}

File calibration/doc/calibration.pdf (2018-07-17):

## Setup:

Assume 3 polypoint tags (A, B, C), all 1 m from each other.

- tA = tx delay for tag A (unknown)
- rA = rx delay for tag A (unknown)
- λ = time of flight for 1 m (λ =

1
c × DWT TIME UNITS)
- = precise delay before sending the next packet (i.e. 5 ms)

The goal is to determine the calibration factor for a tag, calA = tA + rA.

## Protocol:

The following sequence will recover the calC . Note that timestamps from local clocks are not synchronized, nor can the clocks be assumed to be running at exactly the same speed.

1. Tag A sends a packet
2. Tag C sends a packet after
3. Tag C sends a packet after

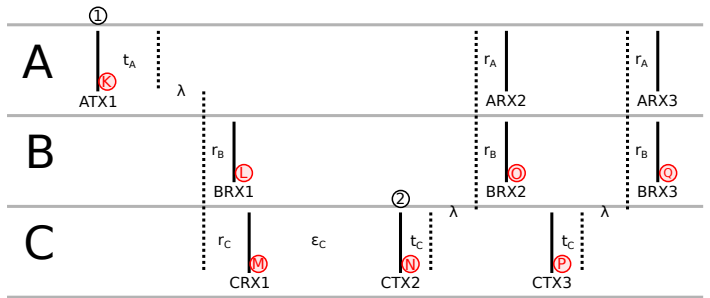
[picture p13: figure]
ATX1; BRX1; CRX1; CTX2; BRX2; ARX2; BRX3; ARX3; CTX3

BRX1 = AT X1 + tA + λ + rB | (1)
BRX2 = AT X1 + tA + λ + rC + C + tC + λ + rB | (2)
BRX2 − BRX1 = ∆B = rC + tC + C + λ | (3)

kC→B =

BRX3 − BRX2
CT X3 − CT X2

(4)

rC + tC = ∆B − C × kC→B − λ | (5)

1

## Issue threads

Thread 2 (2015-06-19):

Incorrect Clock Offset Calculation

bpkempke, 2015-06-19:
Now that the final round uses the 'best' antenna at each anchor, the clock offset calculation needs to be updated to select the ToA which corresponds to the correct tag antenna/anchor antenna pairing.

bradjc, 2015-09-21:
I believe this is done in the new TriPoint firmware.

Closed 2015-09-21.

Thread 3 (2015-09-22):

Fix STM sleep mode

bradjc, 2015-09-22:
1. call `PWR_EnterSTOPMode()` instead
2. Fix main loop so interrupts can't occur before WFI
3. Look at stm-sleep branch for how to get the I2C to wake the STM
4. Figure out why just changing the sleep function doesn't work.

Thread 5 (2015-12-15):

TriPoint Freezes After Short Power Cycle

bpkempke, 2015-12-15:
If power is removed and re-applied within a period of 60 seconds, the TriPoint module will become unresponsive due to the Decawave chip not responding to any commands.  This may be un-fixable with the current Decawave silicon.

bpkempke, 2015-12-15:
The appears to be caused by TriPoint VCC staying above 100mV.  When DW1000 is in deep sleep, it takes a long time for the 10uF decap to drain to below 100mV.

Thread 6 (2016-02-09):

Ranges are often reported as -2 million meters

bpkempke, 2016-02-09:

bradjc, 2016-02-09:
I believe that is an error code.

https://github.com/lab11/polypoint/blob/master/software/firmware/oneway_tag.h#L24

bpkempke, 2016-02-13:
This issue has been solved with commit c34a247d83d63a63692f4040b74ec41144df9d68.  It turns out that if you receive a message too quickly after configuring the receiver, the incoming packet data will contain a variety of bit-shifted portions of the last received packet.  Padding has been applied to the beginning and end of the ranging response windows to avoid this.

bradjc, 2016-02-19:
I'm glad you found and solved this. I saw this happen and thought I was crazy because what chip messes up bits in bytes over SPI?

Closed 2016-02-13.

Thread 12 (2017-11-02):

Making it work / getting started

1am, 2017-11-02:
Hello,

I've made a few prototypes to test out TriPoint circuits on TriBase and TriTag boards. The PCB's arrived mounted well and I'm able to program nRF51 and STM but afterwards it seems that there's an issue with getting the whole device to work... The only thing I can do is connect via BLE (so nRF51 works ok) but STM + DW1000 seem to not be doing anything...

Do you maybe have any tips on what to check? I'm attaching the activity on I2C and SPI lines from the device startup - as you see the I2C commands don't seem right but the FW tested is

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

Tried with tridev and [check_version.py](https://github.com/lab11/polypoint/blob/master/tripoint/check_version.py) scripts but it also fails even though the device enumerates correctly in dmesg.

```
Traceback (most recent call last):
  File "check_version.py", line 8, in <module>
    tp = tripoint.TriPoint()
  File "/../lab11-polypoint/tripoint/tripoint.py", line 28, in __init__
    self.tripoint = mpsse.MPSSE(mpsse.I2C, mpsse.FOUR_HUNDRED_KHZ)
  File "/usr/local/lib/python2.7/dist-packages/mpsse.py", line 70, in __init__
    raise Exception, self.ErrorString()
Exception: device not found
```

ppannuto, 2017-11-20:
Sorry for the slow response, I've been traveling a bunch lately and am way behind.

First thought is that the chip is really sensitive to the power supply, we never got things working with a switching power supply, so if whatever you're using to power the board is at all noisy, that could be causing problems.

As for first debugging steps, is the STM executing any code, i.e. if you probe the GPIO lines to the DW, do you see these toggles: https://github.com/lab11/polypoint/blob/master/software/firmware/main.c#L274 ?

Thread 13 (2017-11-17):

[Feature] Localization of any number of tags at high frequency

AlexisTM, 2017-11-17:
Did you consider implementing a GPS like protocol for the DWM1000?

This requires:
* Synchronizing the timestamps of all devices;
* Each anchor send its position and current timestamp;
* From the positions and timestamps received, the devices compute their position.

Pros:
* Works with any number of tags are they are in "listening only" mode;
* Adding an anchor do not require to change the configuration of each tag;
* The tags are "stupid" and thus do not need more configuration than the band, power, ... and can join any network seamlessly.

Cons:
* The timestamp synchronization must be precise;
* The anchors must send their messages in a synchronous way.

ppannuto, 2017-11-20:
It's a neat concept, but we haven't really pursed this. The biggest challenge is the time synchronization part. At the speed of light, 1 ns of time offset is ~30cm of range error. The best we've been able to synchronize a network of anchors (using DecaWave alone) is a few ns for one-hop neighbors and 10s of ns for two hop neighbors (see Fig 3 of https://patpannuto.com/pubs/kempke16surepoint.pdf).

Using an external synchronization mechanism, or maybe even a novel RF synchronization protocol, could be a cool way to enable things here, but it's not immediately obvious how to realize sufficiently high fidelity RF synchronization.

Closed 2024-10-28.

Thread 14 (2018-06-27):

TriTag revB Issues

ppannuto, 2018-06-27:
- Patch wire from USB+ to BAT+ skips over LTC4065. Should either replace LTC with something else to serve the original purpose, or determine it really wasn't needed and remove it.

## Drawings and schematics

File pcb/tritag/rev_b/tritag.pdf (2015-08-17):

# nRF51822 BLE DecaWave

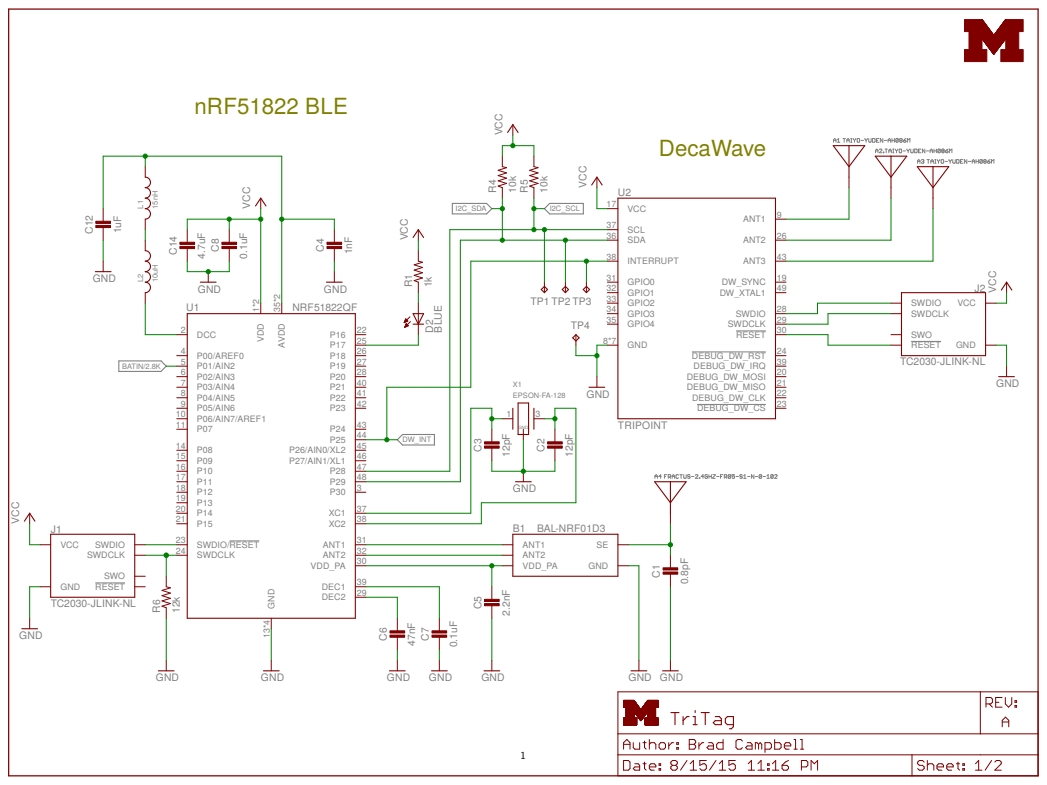
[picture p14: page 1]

36
38 | 43

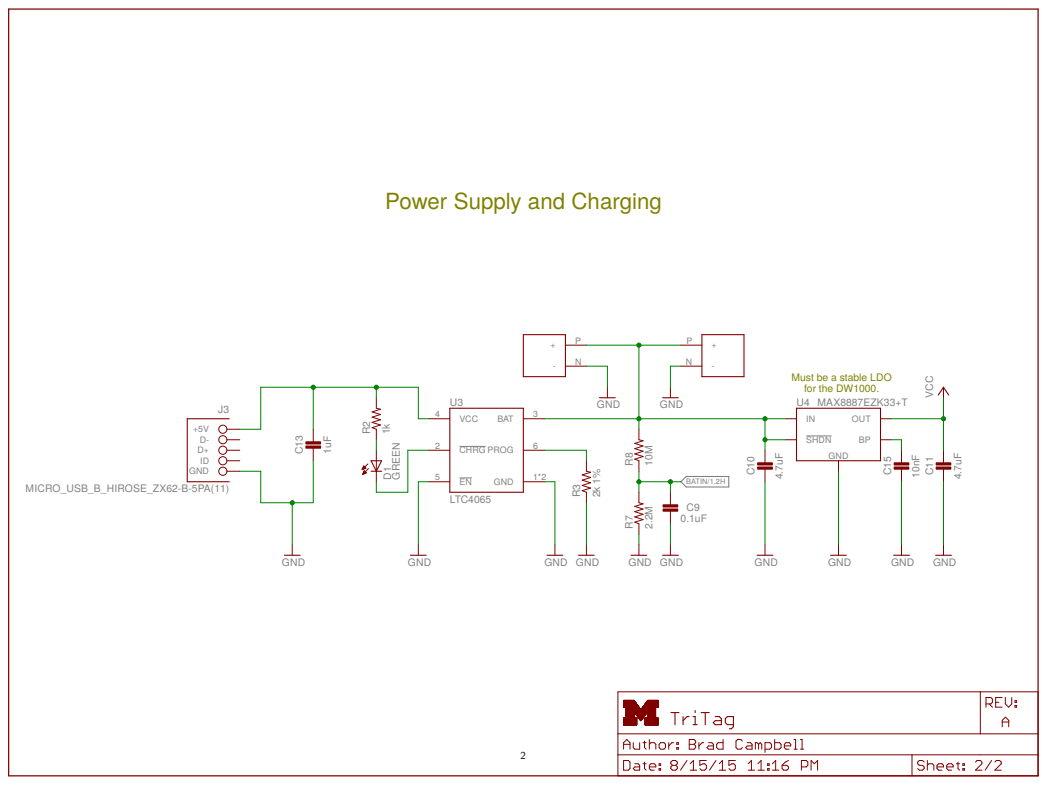
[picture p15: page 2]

Power Supply and Charging

Must be a stable LDO
for the DW1000. GND

# Top and Bottom Layers 3 + - + ⁻

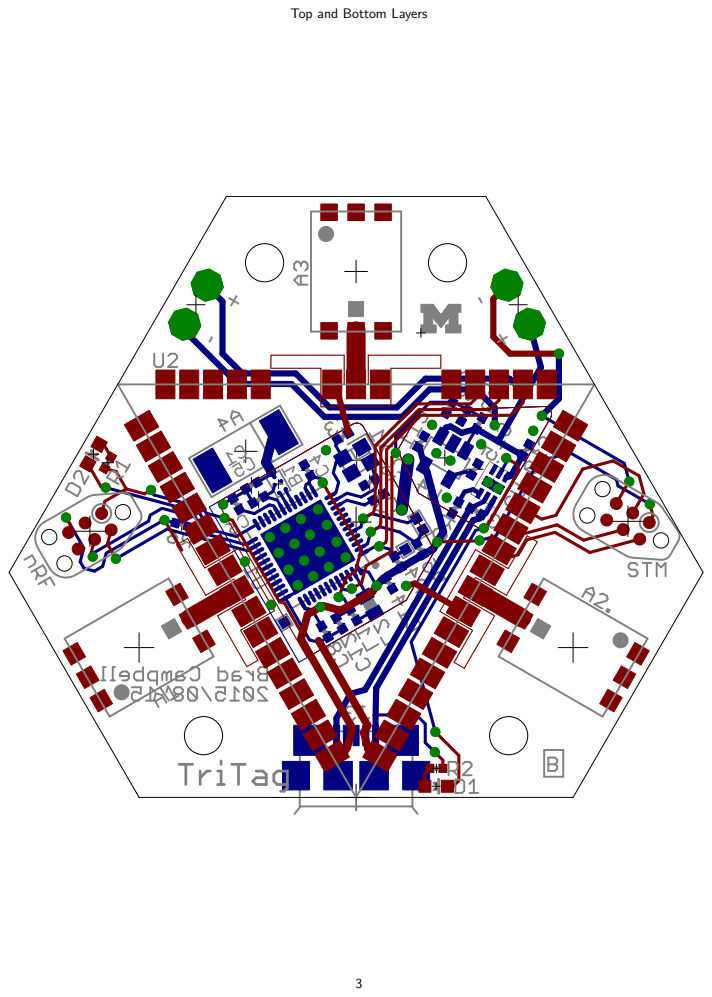
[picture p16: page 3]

# Top Layer 4 + - + ⁻

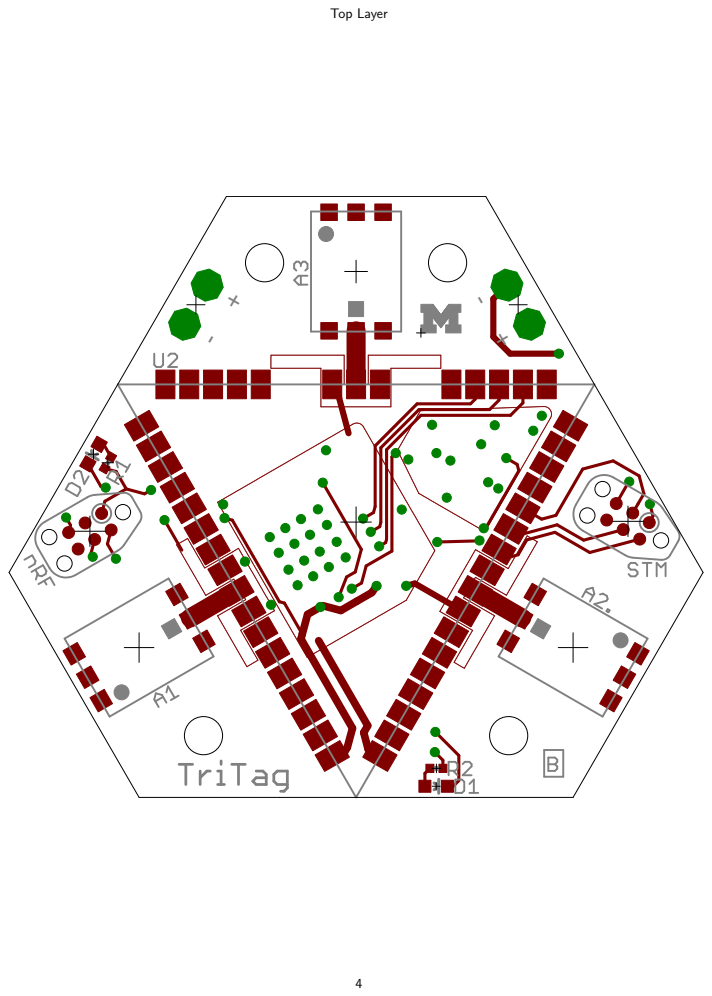
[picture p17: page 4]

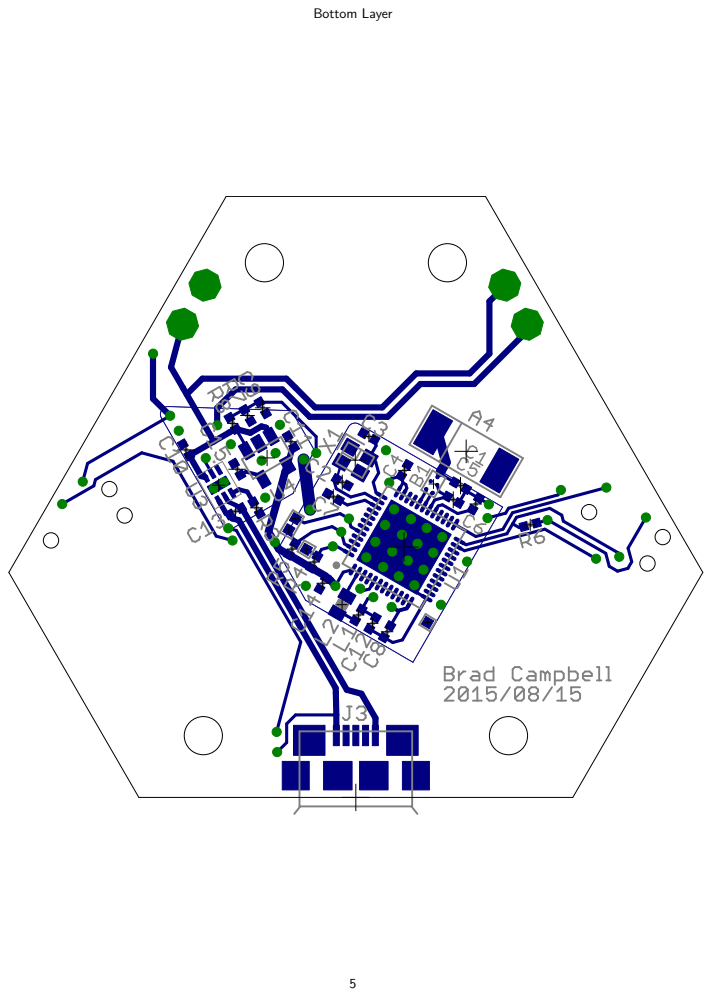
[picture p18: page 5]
Bottom Layer

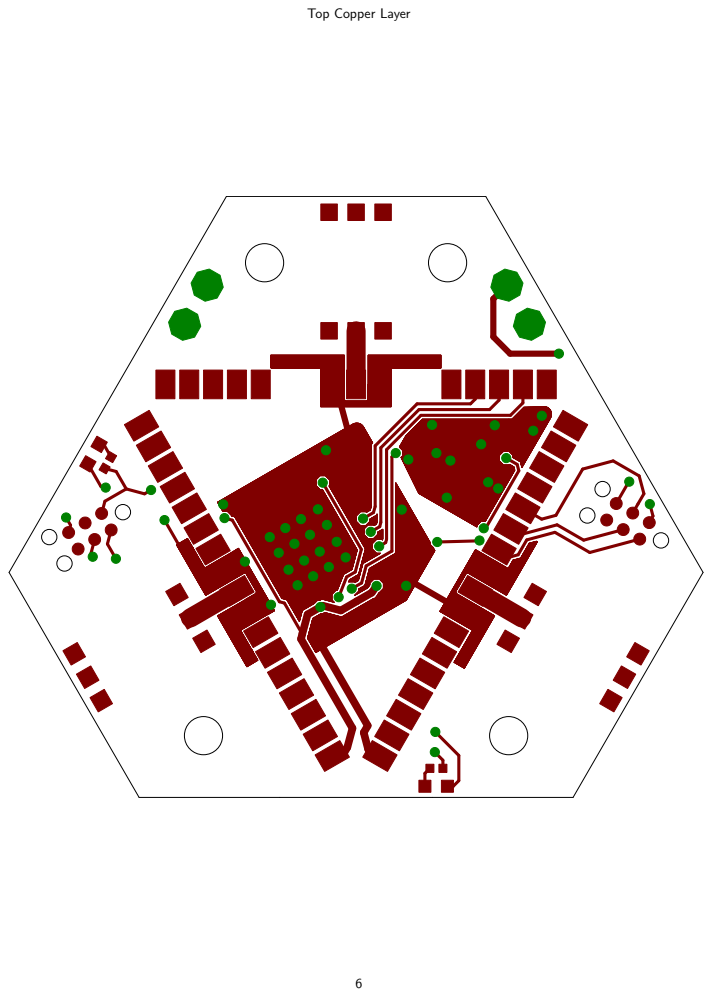
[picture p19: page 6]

Top Copper Layer

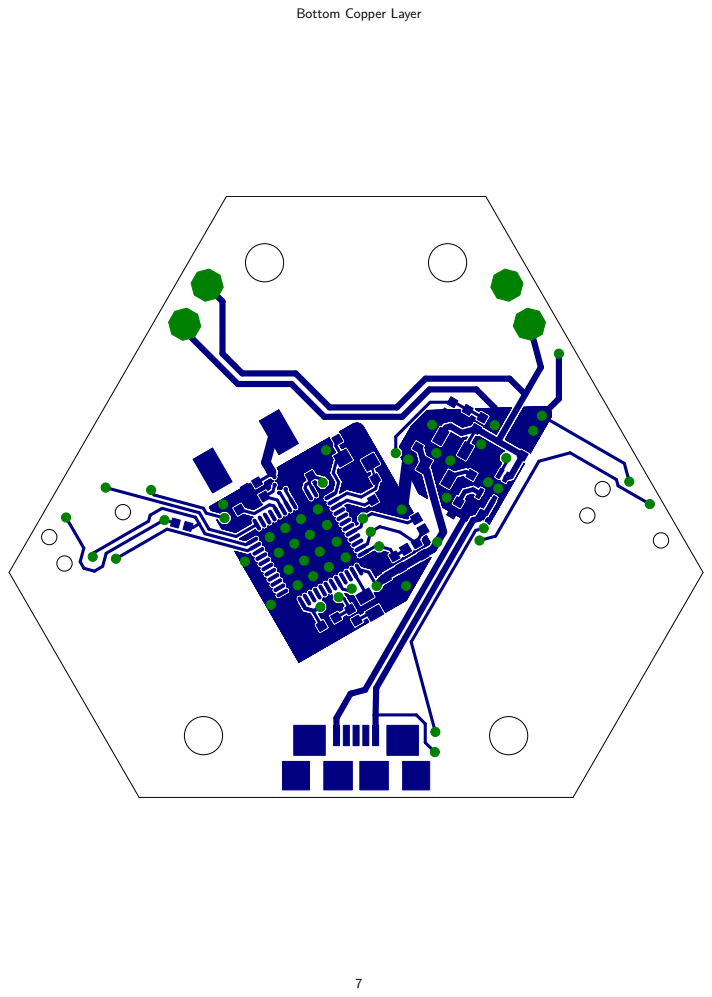
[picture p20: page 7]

Bottom Copper Layer

# Top Paste Layer with Silkscreen 8 + - + ⁻

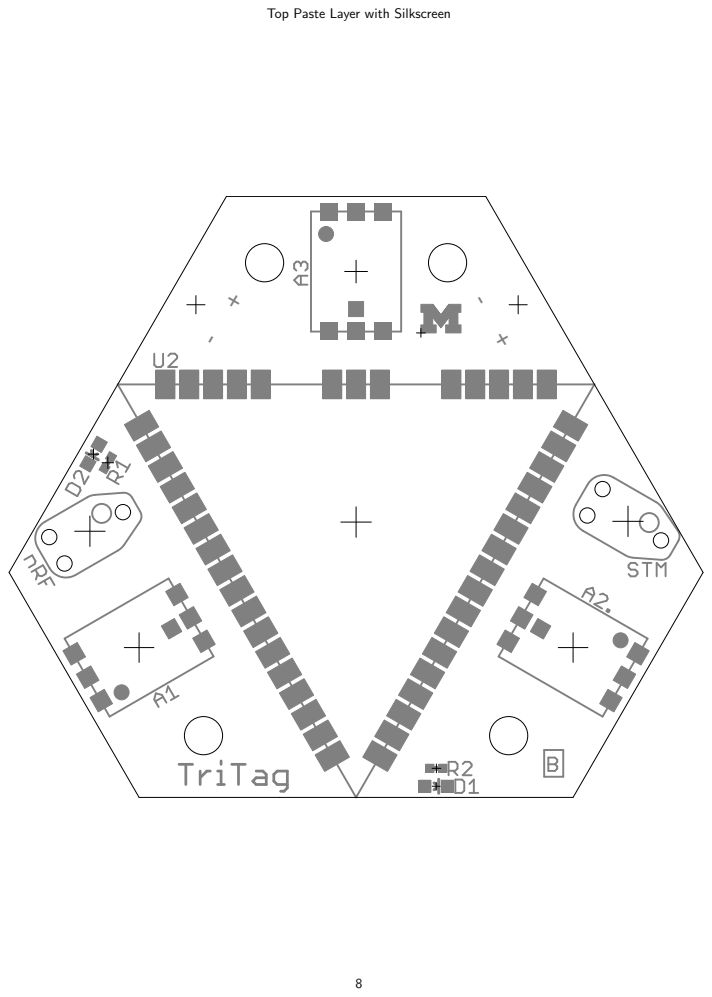
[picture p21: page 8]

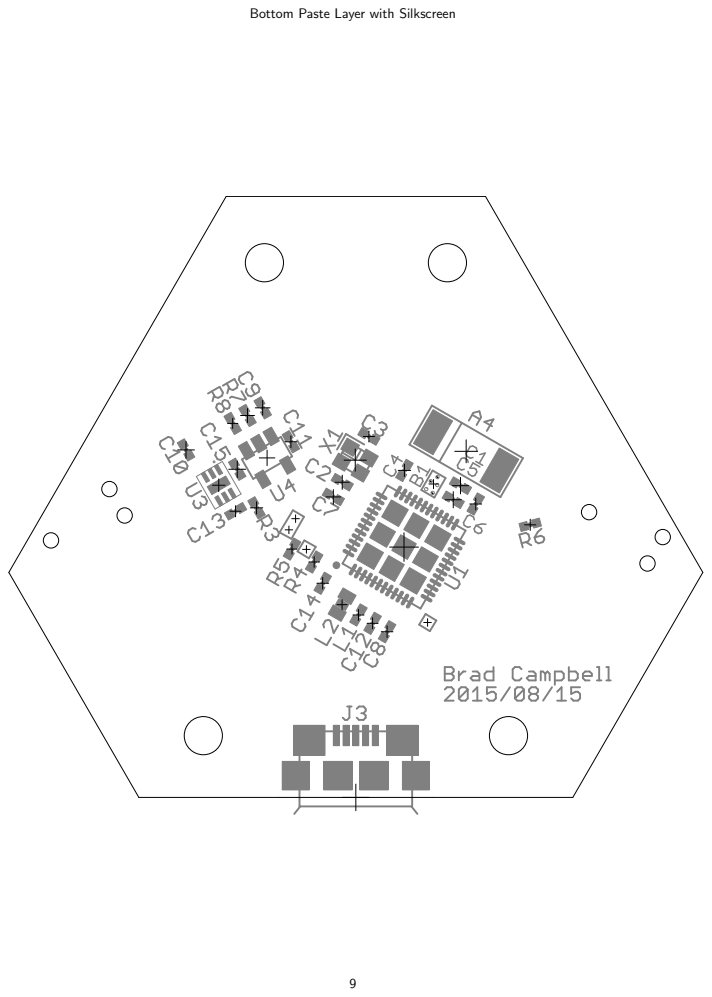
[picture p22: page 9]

Bottom Paste Layer with Silkscreen

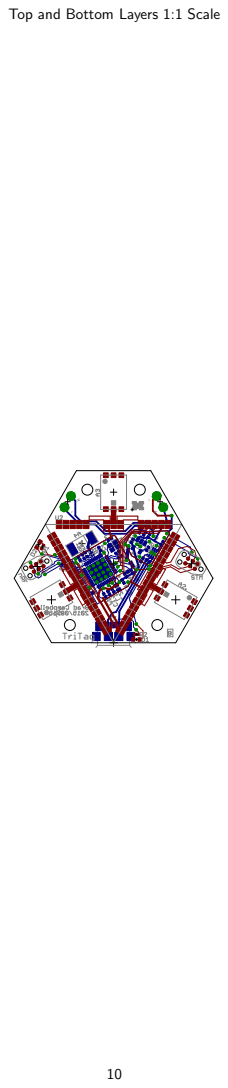
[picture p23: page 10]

Top and Bottom Layers 1:1 Scale

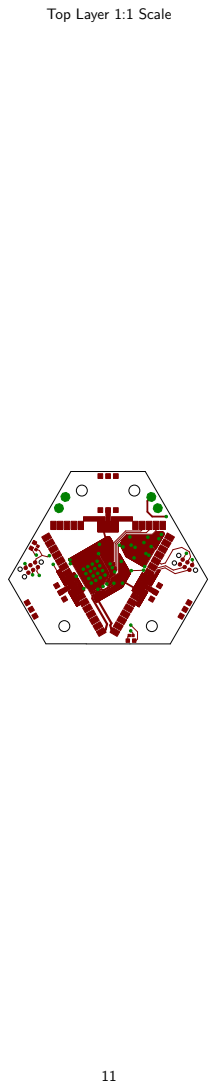
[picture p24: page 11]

Top Layer 1:1 Scale

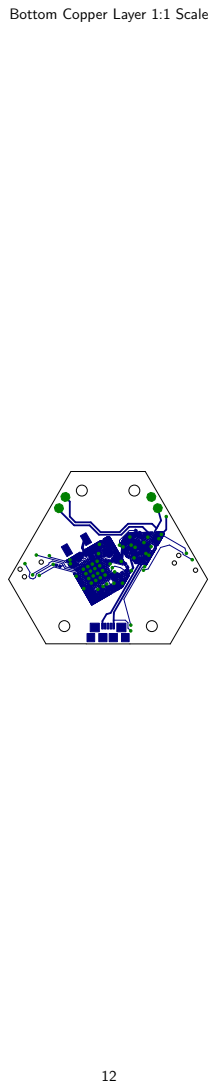
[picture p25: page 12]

Bottom Copper Layer 1:1 Scale

### Sheet1

Qty Value | Device
3 TAIYO-YUDEN-AH086M | TAIYO-YUDEN-AH086M
1 FRACTUS-2.4GHZ-FR05-S1-N-0-102 | FRACTUS-2.4GHZ-FR05-S1-N-0-102
1 BAL-NRF01D3 | BAL-NRF01D3
1 0.8pF | CAPACITOR
2 12pF | CAPACITOR
1 1nF | CAPACITOR
1 2.2nF | CAPACITOR
1 10nF | CAPACITOR
1 47nF | CAPACITOR
3 0.1uF | CAPACITOR
2 1uF | CAPACITOR
3 4.7uF | CAPACITOR
1 GREEN | LED0603
1 BLUE | LED0603
1 MICRO_USB_B_HIROSE_ZX62-B-5PA(11) MICRO_USB_B_HIROSE_ZX62-B-5PA(11)
1 15nH | INDUCTOR0402
1 10uH | INDUCTOR0603
2 1k | RESISTOR0402_RES
1 2k 1% | RESISTOR0402_RES
2 10k | RESISTOR0402_RES
1 12k | RESISTOR0402_RES
1 2.2M | RESISTOR0402_RES
1 10M | RESISTOR0402_RES
1 NRF51822QF | NRF51822QF
1 TRIPOINT | TRIPOINT
1 LTC4065 | LTC4065
1 MAX8887EZK33+T | MAX8887EZK33+T
1 16MHz | TXC-8Y

### Sheet1

Package | Parts | Description
TAIYO-YUDEN-AH086M | A1, A2, A3 | UWB Antenna - 3.1-8GHz
FRACTUS-ANTENNA-FR05-S1-N-0-102 | A4 | Fractus Compact Reach XtendTM chip antenna is engineered specifically for Bluetooth,
BAL-NRF01D3 | B1 | 50 ohm nominal input / conjugate match balun to nRF51422-QFAA,
0402_CAP | C1 | 0402 Capacitor
0402_CAP | C2, C3 | 0402 Capacitor
0402_CAP | C4 | 0402 Capacitor
0402_CAP | C5 | 0402 Capacitor
0402_CAP | C15 | 0402 Capacitor
0402_CAP | C6 | 0402 Capacitor
0402_CAP | C7, C8, C9 | 0402 Capacitor
0402_CAP | C12, C13 | 0402 Capacitor
0402_CAP | C10, C11, C14 | 0402 Capacitor
LED-0603 | D1 | LEDs
LED-0603 | D2 | LEDs
USB_MICRO_B-HIROSE-ZX62-B-5PA(11) J3 | Connector Receptacle USB - micro B 2.0 5 Position Surface Mount, Right Angle, Horizontal
0402_CAP | L1 | INDUCTOR HI FREQ 15NH 5% 0402
0603_CAP | L2 | INDUCTOR 10UH 50MA 0603
0402_RES | R1, R2 | Resistor
0402_RES | R3 | Resistor
0402_RES | R4, R5 | Resistor
0402_RES | R6 | Resistor
0402_RES | R7 | Resistor
0402_RES | R8 | Resistor
QFN-48-6MM | U1 | Multiprotocol Bluetooth® 4.0 low energy/2.4 GHz RF SoC
TRIPOINT | U2 | UWB Ranging Module
DFN-6/2MM | U3 | LION/LIPO Battery Charging IC Low current
SOT-23-5 | U4 | IC REG LDO 3.3V 0.3A TSOT23-5
TXC-8Y | X1 | CRYSTAL 16MHZ 8PF SMD

### Sheet1

DIGIKEY | MOUSER | NEWARK RICHARDSON_RFPD
587-2204-1-ND
| | FR05-S1-N-0102B
497-13637-1-ND | 511-BAL-NRF01D3
490-6269-1-ND
490-6197-1-ND
490-1303-1-ND
490-5419-1-ND
445-1260-1-ND
445-1264-1-ND
490-1318-1-ND
445-4998-1-ND
445-5947-1-ND
160-1446-1-ND
160-1837-1-ND
H11634CT-ND | 798-ZX62-B-5PA11 | 86P8793
587-1521-1-ND
490-4025-1-ND
RHM1.0KCECT-ND
RHM2KCDCT-ND
RHM10.0KCDCT-ND
RHM12.0KCDCT-ND
541-2.20MLCT-ND
RHM10MBICT-ND
1490-1042-1-ND | 949-NRF51822-QFAB-R7

LTC4065LEDC#TRMPBFCT-ND
MAX8887EZK33+TCT-ND
887-2003-1-ND

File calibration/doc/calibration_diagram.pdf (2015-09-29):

# ABC

ATX1; BRX1; CRX1; CTX2; BRX2; ARX2; BRX3; ARX3; CTX3




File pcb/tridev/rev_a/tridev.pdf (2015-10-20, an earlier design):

# nRF51822 BLE LINX-SMA-EDGE-0.062 LINX-SMA-EDGE-0.062 DecaWave


LINX-SMA-EDGE-0.062 GND

36
38 | | 43

TP_GPIO0 | DW_SYNC
TP_GPIO1 | DW_XTAL1

# I2C over USB Interface


for the DW1000. TriPoint Power Supply


Top and Bottom Layers

Top Layer

Bottom Layer


Top Copper Layer


Bottom Copper Layer


Top Paste Layer with Silkscreen


Bottom Paste Layer with Silkscreen


Top and Bottom Layers 1:1 Scale


Top Layer 1:1 Scale


Bottom Copper Layer 1:1 Scale

### Sheet1

Qty Value | Device
3 LINX-SMA-EDGE-0.062 | LINX-SMA-EDGE-0.062
1 FRACTUS-2.4GHZ-FR05-S1-N-0-102 FRACTUS-2.4GHZ-FR05-S1-N-0-102
1 BAL-NRF01D3 | BAL-NRF01D3
1 0.8pF | CAPACITOR
2 12pF | CAPACITOR
2 18pF | CAPACITOR
1 1nF | CAPACITOR
1 2.2nF | CAPACITOR
1 10nF | CAPACITOR
1 47nF | CAPACITOR
110.1uF | CAPACITOR
2 1uF | CAPACITOR
3 4.7uF | CAPACITOR
2 4.7uF | CAP_POL0603
1 GREEN | LED0603
2 BLUE | LED0603
1 RED | LED0603
1 MICRO_USB_B_HIROSE_ZX62R-B-5PMICRO_USB_B_HIROSE_ZX62R-B-5P
1 | PINHD-2X10
2 | JUMPER-2PTH
1 15nH | INDUCTOR0402
1 10uH | INDUCTOR0603
3 FERRITE_BEAD | FERRITE_BEAD
4 1k | RESISTOR0402_RES
2 10k | RESISTOR0402_RES
1 12k 1% | RESISTOR0402_RES
1 TRIPOINT-BREAKOUT | TRIPOINT-BREAKOUT
1 NRF51822QF | NRF51822QF
1 MAX8887EZK33+T | MAX8887EZK33+T
1 FT232HQ | FT232HQ
1 16MHz | TXC-8Y
1 TXC-8Z-12MHZ | TXC-8Z-12MHZ

### Sheet1

Package | Parts
CONSMA003.062 | A1, A2, A3
FRACTUS-ANTENNA-FR05-S1-N-0-102 A4
BAL-NRF01D3 | B1
0402_CAP | C1
0402_CAP | C2, C3
0402_CAP | C4, C5
0402_CAP | C6
0402_CAP | C7
0402_CAP | C8
0402_CAP | C9
0402_CAP | C10-C20
0402_CAP | C21, C22
0402_CAP | C23, C24, C25
CAP0603 | C26, C27
LED-0603 | D1
LED-0603 | D2, D3
LED-0603 | D4
USB_MICRO_B-HIROSE-ZX62R-B-5P | J1
2X10 | J2
1X02 | J3, J4
0402_CAP | L1
0603_CAP | L2
0603_CAP | L3, L4, L5
0402_RES | R1, R2, R3, R4
0402_RES | R5, R6
0402_RES | R7, R8
TRIPOINT-BREAKOUT | U1
QFN-48-6MM | U2
SOT-23-5 | U3
QFN-48-8MM | U4
TXC-8Y | X1
TXC-8Z | X2

### Sheet1

Description
CONN SMA JACK 50 OHM EDGE MNT
Fractus Compact Reach XtendTM chip antenna is engineered specifically for Bluetooth, 50 ohm nominal input / conjugate match balun to nRF51422-QFAA,
0402 Capacitor
0402 Capacitor
0402 Capacitor
0402 Capacitor
0402 Capacitor
0402 Capacitor
0402 Capacitor
0402 Capacitor
0402 Capacitor
0402 Capacitor
0603 Capacitor
LEDs
LEDs
LEDs
USB Micro B Connector
PIN HEADER
Jumper

Resistor
Resistor
Resistor
UWB Ranging Module
Multiprotocol Bluetooth® 4.0 low energy/2.4 GHz RF SoC IC REG LDO 3.3V 0.3A TSOT23-5
Single Channel USB to Multipurpose I/O IC
CRYSTAL 16MHZ 8PF SMD

### Sheet1

DIGIKEY | MOUSER | NEWARK RICHARDSON_RFPD
CONSMA003.062-ND | | | y
FR05-S1-N-0102B | y
497-13637-1-ND | 511-BAL-NRF01D3 | | y
490-6269-1-ND | | | y
490-6197-1-ND | | | y
490-6203-1-ND | | | y
490-1303-1-ND | | | y
490-5419-1-ND | | | y
445-1260-1-ND | | | y
445-1264-1-ND | | | y
490-1318-1-ND | | | y
445-4998-1-ND | | | y
445-5947-1-ND | | | y
478-8656-1-ND | | | y
160-1446-1-ND | | | y
160-1837-1-ND | | | y
160-1835-1-ND | | | y
H11574CT-ND | 798-ZX62R-B-5P | 69W0714 | y
609-3365-ND | | | y
| | | y
587-1521-1-ND | | | y
490-4025-1-ND | | | y
445-2166-1-ND | | | y
RHM1.0KCECT-ND | | | y
RHM10.0KCDCT-ND | | | y
RHM12.0KCDCT-ND | | | y
| | | y
1490-1032-1-ND | 949-NRF51822-QFAB-R7 | | y
MAX8887EZK33+TCT-ND | | | y
768-1102-1-ND | 895-FT232HQ-REEL | 65W8039 | y
887-2003-1-ND | | | y
887-1487-1-ND | | | y

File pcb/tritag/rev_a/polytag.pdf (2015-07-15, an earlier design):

# nRF51822 BLE DecaWave


36
38 | 43


Power Supply and Charging

# Top and Bottom Layers 3 + - + ⁻


# Top Layer 4 + - + ⁻


Bottom Layer


Top Copper Layer


Bottom Copper Layer

# Top Paste Layer with Silkscreen 8 + - + ⁻



Bottom Paste Layer with Silkscreen


Top and Bottom Layers 1:1 Scale


Top Layer 1:1 Scale


Bottom Copper Layer 1:1 Scale

### Sheet1

Qty Value | Device
3 TAIYO-YUDEN-AH086M | TAIYO-YUDEN-AH086M
1 FRACTUS-2.4GHZ-FR05-S1-N-0-102 | FRACTUS-2.4GHZ-FR05-S1-N-0-102
1 BAL-NRF01D3 | BAL-NRF01D3
1 0.8pF | CAPACITOR
2 12pF | CAPACITOR
1 1nF | CAPACITOR
1 2.2nF | CAPACITOR
1 47nF | CAPACITOR
4 0.1uF | CAPACITOR
1 0.47uF | CAPACITOR
2 1uF | CAPACITOR
1 4.7uF | CAPACITOR
1 GREEN | LED0603
1 BLUE | LED0603
1 MICRO_USB_B_HIROSE_ZX62-B-5PA(11) MICRO_USB_B_HIROSE_ZX62-B-5PA(11)
1 15nH | INDUCTOR0402
1 10uH | INDUCTOR0603
2 1k | RESISTOR0402_RES
1 2k 1% | RESISTOR0402_RES
2 10k | RESISTOR0402_RES
1 12k | RESISTOR0402_RES
1 2.2M | RESISTOR0402_RES
1 10M | RESISTOR0402_RES
1 NRF51822QF | NRF51822QF
1 TRIPOINT | TRIPOINT
1 LTC4065 | LTC4065
1 TPS715AXX | TPS715AXX
1 16MHz | TXC-8Y

### Sheet1

Package | Parts
TAIYO-YUDEN-AH086M | A1, A2, A3
FRACTUS-ANTENNA-FR05-S1-N-0-102 | A4
BAL-NRF01D3 | B1
0402_CAP | C1
0402_CAP | C2, C3
0402_CAP | C4
0402_CAP | C5
0402_CAP | C6
0402_CAP | C7, C8, C9, C10
0402_CAP | C11
0402_CAP | C12, C13
0402_CAP | C14
LED-0603 | D1
LED-0603 | D2
USB_MICRO_B-HIROSE-ZX62-B-5PA(11) J3
0402_CAP | L1
0603_CAP | L2
0402_RES | R1, R2
0402_RES | R3
0402_RES | R4, R5
0402_RES | R6
0402_RES | R7
0402_RES | R8
QFN-48-6MM | U1
TRIPOINT | U2
DFN-6/2MM | U3
WDFN-6 | U4
TXC-8Y | X1

### Sheet1

Description
UWB Antenna - 3.1-8GHz
Fractus Compact Reach XtendTM chip antenna is engineered specifically for Bluetooth, 50 ohm nominal input / conjugate match balun to nRF51422-QFAA,
0402 Capacitor
0402 Capacitor
0402 Capacitor
0402 Capacitor
0402 Capacitor
0402 Capacitor
0402 Capacitor
0402 Capacitor
0402 Capacitor
LEDs
LEDs
Connector Receptacle USB - micro B 2.0 5 Position Surface Mount, Right Angle, Horizontal INDUCTOR HI FREQ 15NH 5% 0402
INDUCTOR 10UH 50MA 0603
Resistor
Resistor
Resistor
Resistor
Resistor
Resistor
Multiprotocol Bluetooth® 4.0 low energy/2.4 GHz RF SoC
UWB Ranging Module
LION/LIPO Battery Charging IC Low current
80ma LDO Regulator. Very low quiescent current. Always active. CRYSTAL 16MHZ 8PF SMD

### Sheet1

DIGIKEY | MOUSER | NEWARK RICHARDSON_RFPD
587-2204-1-ND
| | FR05-S1-N-0102B
497-13637-1-ND | 511-BAL-NRF01D3
490-6269-1-ND
490-6197-1-ND
490-1303-1-ND
490-5419-1-ND
445-1264-1-ND
490-1318-6-ND
490-3266-1-ND
1276-1513-1-ND
445-5947-1-ND

160-1647-1-ND
H11634CT-ND | 798-ZX62-B-5PA11 | 86P8793
587-1521-1-ND
490-4025-1-ND
RHM1.0KCECT-ND
RHM2KCDCT-ND
RHM10.0KCDCT-ND
RHM12.0KCDCT-ND
541-2.20MLCT-ND
RHM10MBICT-ND
1490-1032-1-ND | 949-NRF51822-QFAB-R7

LTC4065LEDC#TRMPBFCT-ND
296-22584-1-ND
887-2003-1-ND

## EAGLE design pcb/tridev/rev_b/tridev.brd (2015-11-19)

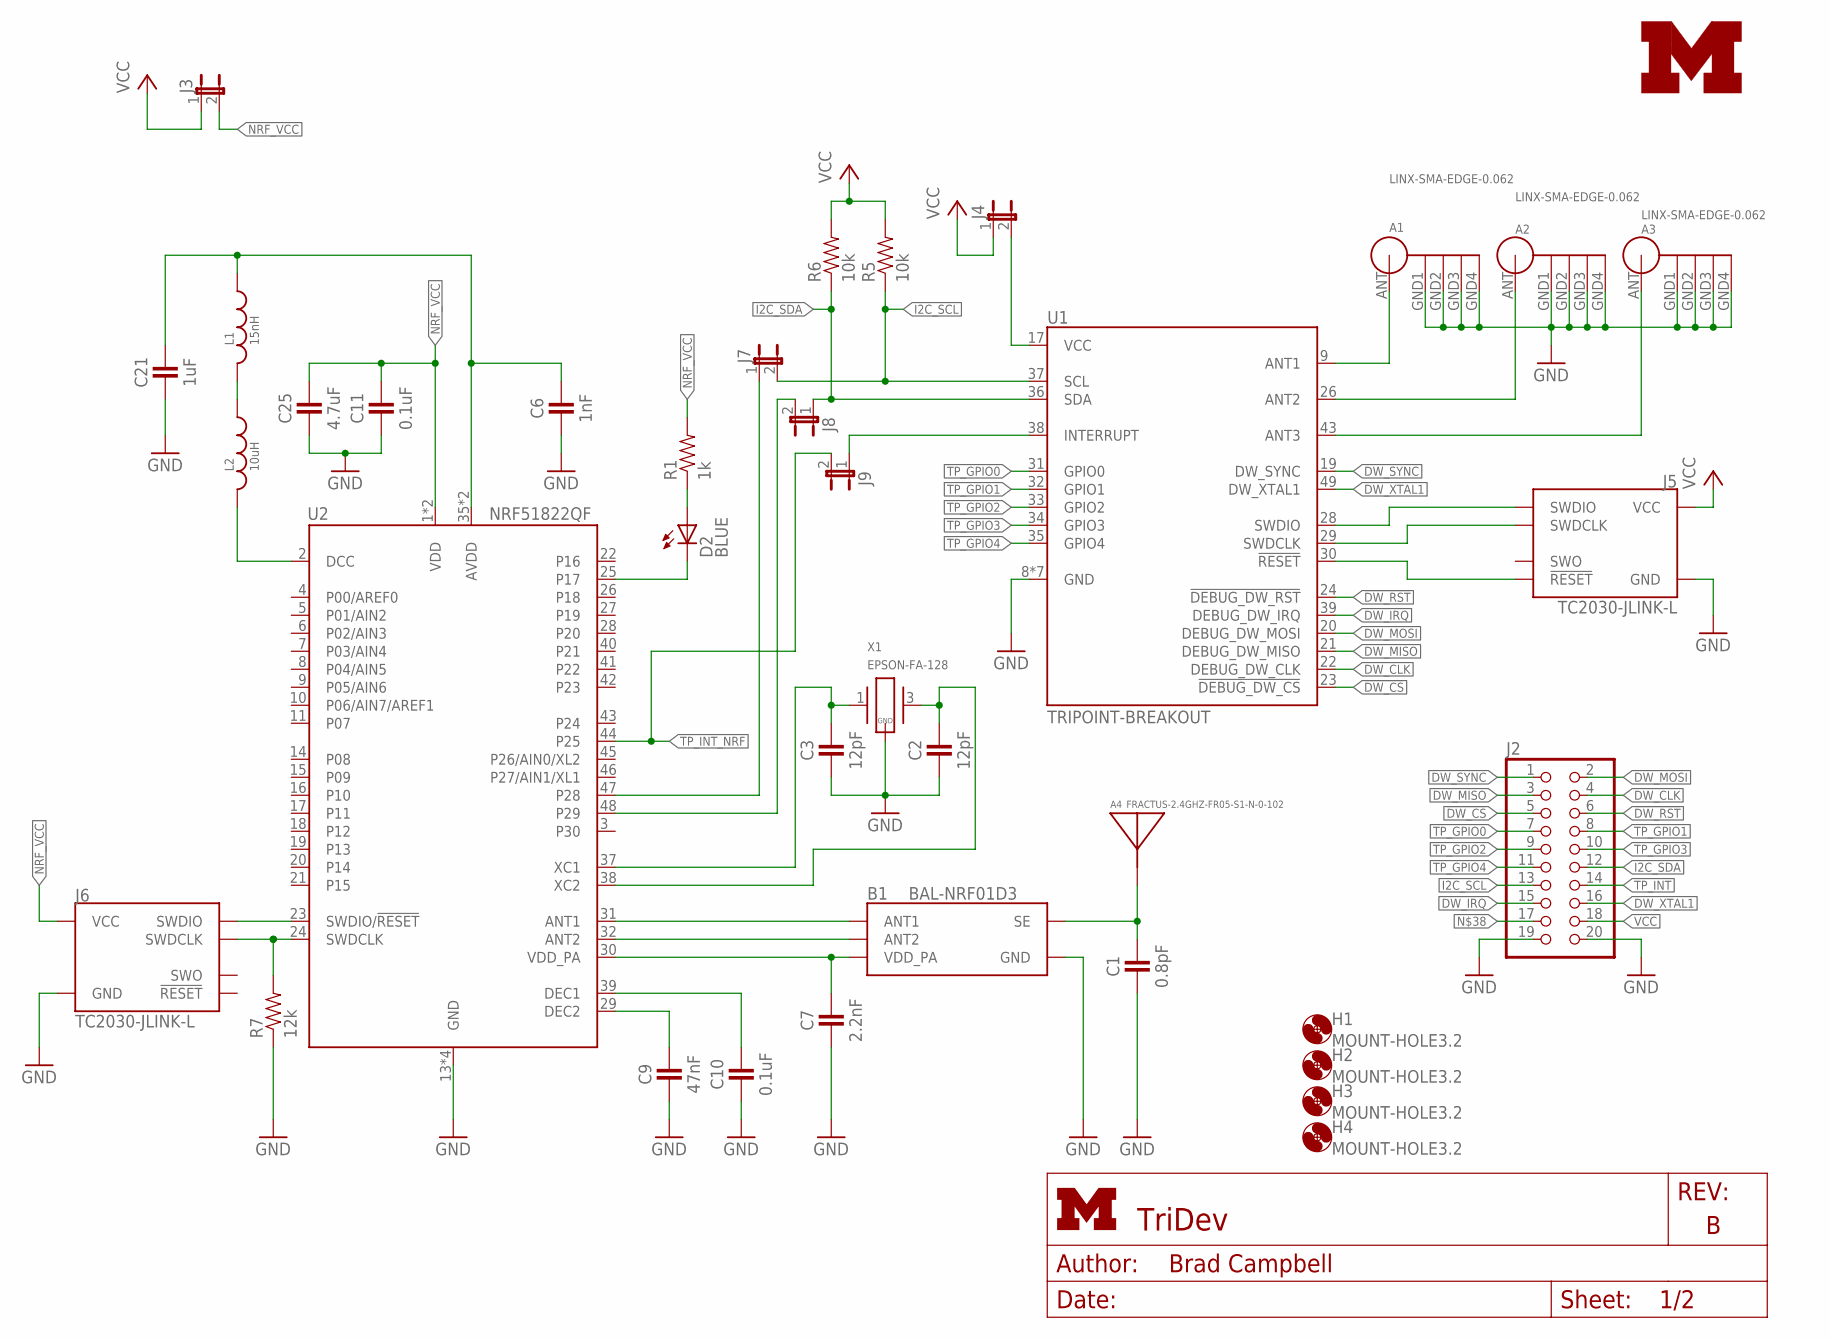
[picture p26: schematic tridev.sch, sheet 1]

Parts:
A1, A2, A3: LINX-SMA-EDGE-0.062; CONSMA003.062
A4: FRACTUS-2.4GHZ-FR05-S1-N-0-102; FRACTUS-ANTENNA-FR05-S1-N-0-102
B1: BAL-NRF01D3
C1: 0.8pF; 0402_CAP
C2, C3: 12pF; 0402_CAP
C6: 1nF; 0402_CAP
C7: 2.2nF; 0402_CAP
C9: 47nF; 0402_CAP
C10, C11: 0.1uF; 0402_CAP
C21: 1uF; 0402_CAP
C25: 4.7uF; 0402_CAP
D2: BLUE; LED-0603
H1, H2, H3, H4: MOUNT-HOLE3.2; 3,2
J2: PINHD-2X10; 2X10
J3, J4, J7, J8, J9: JUMPER-2PTH; 1X02
J5, J6: TC2030-JLINK-L; TC2030-IDC
L1: 15nH; 0402_CAP
L2: 10uH; 0603_CAP
LOGO1: UMICH_SOLID_SMALL; UMICH_SOLID_75MIL
R1: 1k; 0402_RES
R5, R6: 10k; 0402_RES
R7: 12k; 0402_RES
U1: TRIPOINT-BREAKOUT
U2: NRF51822QF; QFN-48-6MM
X1: EPSON-FA-128; FA-128

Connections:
!CHRG1: D2.A, R1.1
!DW_CS: J2.5, U1.23 (!DEBUG_DW_CS)
!DW_RST: J2.6, U1.24 (!DEBUG_DW_RST)
ANTENNA: A4.1, B1.SE, C1.1
AVDD: C6.1, C21.1, L1.1, U2.35 (AVDD), U2.36 (AVDD)
DCC: L2.2, U2.2 (DCC)
DW_CLK: J2.4, U1.22 (DEBUG_DW_CLK)
DW_IRQ: J2.15, U1.39 (DEBUG_DW_IRQ)
DW_MISO: J2.3, U1.21 (DEBUG_DW_MISO)
DW_MOSI: J2.2, U1.20 (DEBUG_DW_MOSI)
DW_SYNC: J2.1, U1.19 (DW_SYNC)
DW_XTAL1: J2.16, U1.49 (DW_XTAL1)
GND: A1.GND1, A1.GND2, A1.GND3, A1.GND4, A2.GND1, A2.GND2, A2.GND3, A2.GND4, A3.GND1, A3.GND2, A3.GND3, A3.GND4, B1.GND, C1.2, C2.2, C3.2, C6.2, C7.2, C9.2, C10.2, C11.2, C21.2, C25.2, J2.19, J2.20, J5.5 (GND), J6.5 (GND), R7.1, U1.8 (GND), U1.10 (GND), U1.18 (GND), U1.25 (GND), U1.27 (GND), U1.42 (GND), U1.44 (GND), U2.13 (GND), U2.33 (GND), U2.34 (GND), U2.GND, X1.2 (GND), X1.4 (GND); also elsewhere on the board
I2C_SCL: J2.13, J7.2, R5.1, U1.37 (SCL); also elsewhere on the board
I2C_SCL_NRF: J7.1, U2.47 (P28)
I2C_SDA: J2.12, J8.1, R6.1, U1.36 (SDA); also elsewhere on the board
I2C_SDA_NRF: J8.2, U2.48 (P29)
unnamed: A1.ANT, U1.9 (ANT1)
unnamed: A2.ANT, U1.26 (ANT2)
unnamed: A3.ANT, U1.43 (ANT3)
unnamed: J5.2 (SWDIO), U1.28 (SWDIO)
unnamed: D2.C, U2.25 (P17)
unnamed: J5.4 (SWDCLK), U1.29 (SWDCLK)
unnamed: J5.3 (!RESET), U1.30 (!RESET)
unnamed: C3.1, U2.37 (XC1), X1.1
unnamed: C2.1, U2.38 (XC2), X1.3 (2)
unnamed: C9.1, U2.29 (DEC2)
unnamed: C10.1, U2.39 (DEC1)
unnamed: B1.ANT1, U2.31 (ANT1)
unnamed: B1.ANT2, U2.32 (ANT2)
unnamed: B1.VCC (VDD_PA), C7.1, U2.30 (VDD_PA)
unnamed: J4.2, U1.17 (VCC)
unnamed: L1.2, L2.1
NRF_VCC: C11.1, C25.1, J3.2, J6.1 (VCC), R1.2, U2.1 (VDD), U2.12 (VDD)
SWDCLK: J6.4 (SWDCLK), R7.2, U2.24 (SWDCLK)
SWDIO/!RESET: J6.2 (SWDIO), U2.23 (SWDIO/!RESET)
TP_GPIO0: J2.7, U1.31 (GPIO0)
TP_GPIO1: J2.8, U1.32 (GPIO1)
TP_GPIO2: J2.9, U1.33 (GPIO2)
TP_GPIO3: J2.10, U1.34 (GPIO3)
TP_GPIO4: J2.11, U1.35 (GPIO4)
TP_INT: J2.14, J9.1, U1.38 (INTERRUPT); also elsewhere on the board
TP_INT_NRF: J9.2, U2.44 (P25)
VCC: J2.18, J3.1, J4.1, J5.1 (VCC), R5.2, R6.2; also elsewhere on the board

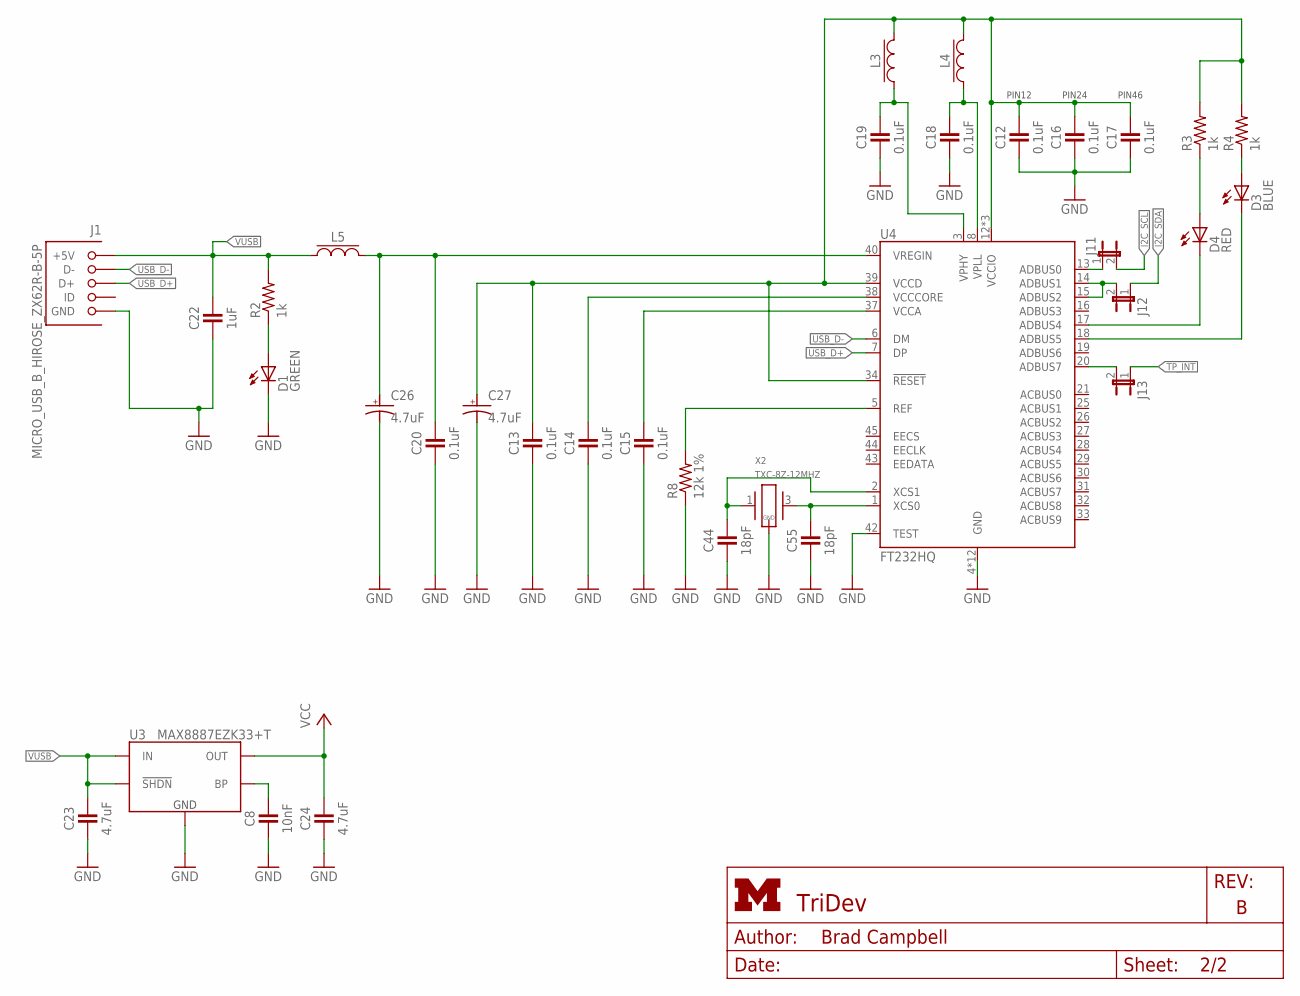
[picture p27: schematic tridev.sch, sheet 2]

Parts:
C8: 10nF; 0402_CAP
C12, C13, C14, C15, C16, C17, C18, C19, C20: 0.1uF; 0402_CAP
C22: 1uF; 0402_CAP
C23, C24: 4.7uF; 0402_CAP
C26, C27: 4.7uF; CAP0603; DIGIKEY 478-8656-1-ND
C44, C55: 18pF; 0402_CAP
D1: GREEN; LED-0603
D3: BLUE; LED-0603
D4: RED; LED-0603
J1: MICRO_USB_B_HIROSE_ZX62R-B-5P; USB_MICRO_B-HIROSE-ZX62R-B-5P; MOUSER 798-ZX62R-B-5P
J11, J12, J13: JUMPER-2PTH; 1X02
L3, L4, L5: FERRITE_BEAD; 0603_CAP; DIGIKEY 445-2166-1-ND
R2, R3, R4: 1k; 0402_RES
R8: 12k 1%; 0402_RES
U3: MAX8887EZK33+T; SOT-23-5
U4: FT232HQ; QFN-48-8MM
X2: TXC-8Z-12MHZ; TXC-8Z

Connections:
!CHRG: D1.A, R2.1
GND: C8.2, C12.2, C13.2, C14.2, C15.2, C16.2, C17.2, C18.2, C19.2, C20.2, C22.2, C23.2, C24.2, C26.NEG (ANODE), C27.NEG (ANODE), C44.2, C55.2, D1.C, J1.5 (GND), R8.1, U3.2 (GND), U4.4 (GND), U4.9 (GND), U4.10 (GND), U4.11 (GND), U4.22 (GND), U4.23 (GND), U4.35 (GND), U4.36 (GND), U4.41 (GND), U4.42 (TEST), U4.47 (GND), U4.48 (GND), U4.PAD (GND), X2.2 (GND), X2.4 (GND); also elsewhere on the board
I2C_SCL: J11.2; also elsewhere on the board
I2C_SCL_FTDI: J11.1, U4.13 (ADBUS0)
I2C_SDA: J12.1; also elsewhere on the board
I2C_SDA_FTDI: J12.2, U4.14 (ADBUS1), U4.15 (ADBUS2)
unnamed: D4.C, U4.17 (ADBUS4)
unnamed: C8.1, U3.4 (BP)
unnamed: C20.1, C26.POS (CATHODE), L5.2, U4.40 (VREGIN)
unnamed: C14.1, U4.38 (VCCCORE)
unnamed: C55.1, U4.1 (XCS0), X2.3 (2)
unnamed: C44.1, U4.2 (XCS1), X2.1
unnamed: C15.1, U4.37 (VCCA)
unnamed: R8.2, U4.5 (REF)
unnamed: D4.A, R3.1
unnamed: D3.A, R4.1
unnamed: D3.C, U4.18 (ADBUS5)
TP_INT: J13.1; also elsewhere on the board
TP_INT_FTDI: J13.2, U4.20 (ADBUS7)
USB_D+: J1.3 (D+), U4.7 (DP)
USB_D-: J1.2 (D-), U4.6 (DM)
VCC: C24.1, U3.5 (OUT); also elsewhere on the board
VCC3V3: C12.1, C13.1, C16.1, C17.1, C27.POS (CATHODE), L3.2, L4.2, R3.2, R4.2, U4.12 (VCCIO), U4.24 (VCCIO), U4.34 (!RESET), U4.39 (VCCD), U4.46 (VCCIO)
VPHY: C19.1, L3.1, U4.3 (VPHY)
VPLL: C18.1, L4.1, U4.8 (VPLL)
VUSB: C22.1, C23.1, J1.1 (+5V), L5.1, R2.2, U3.1 (IN), U3.3 (!SHDN)

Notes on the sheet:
PIN12
PIN24
PIN46

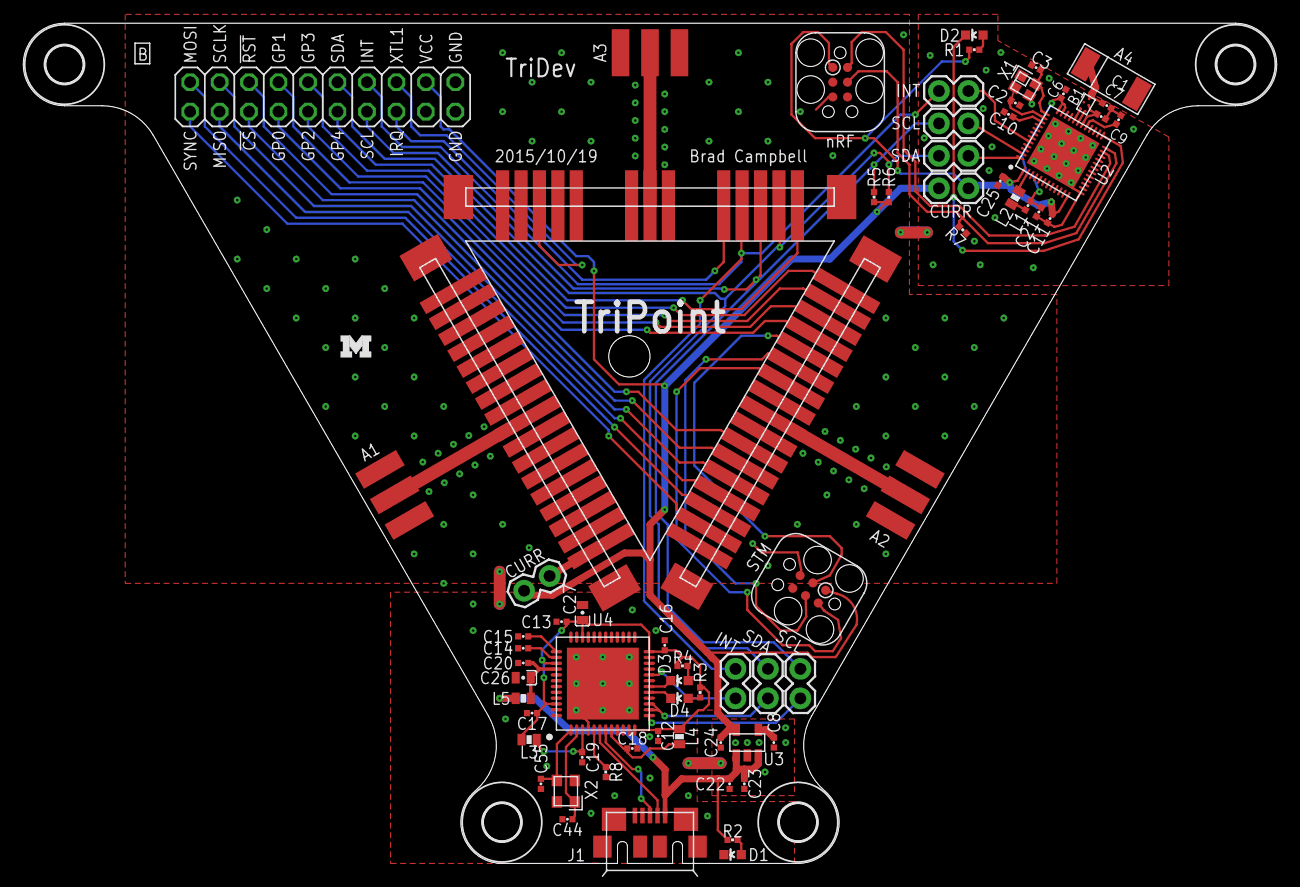
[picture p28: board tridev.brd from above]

Board: 2 copper layers, 108.0 x 72.4 mm, 72 parts (0 on the bottom side), 65 nets.

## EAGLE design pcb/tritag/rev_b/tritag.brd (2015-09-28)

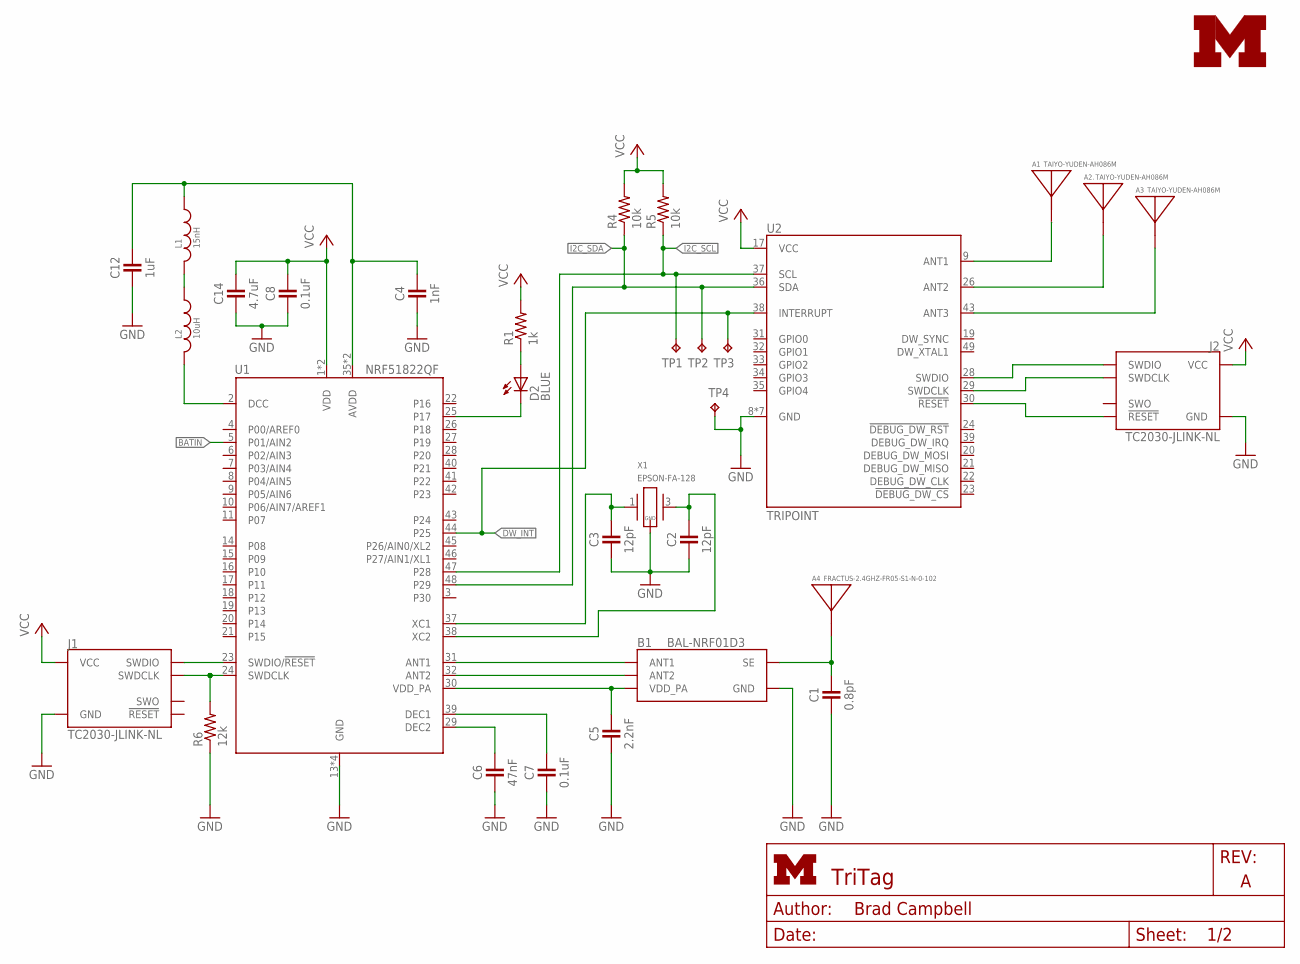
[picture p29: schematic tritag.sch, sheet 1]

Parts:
A1, A2., A3: TAIYO-YUDEN-AH086M
A4: FRACTUS-2.4GHZ-FR05-S1-N-0-102; FRACTUS-ANTENNA-FR05-S1-N-0-102
B1: BAL-NRF01D3
C1: 0.8pF; 0402_CAP
C2, C3: 12pF; 0402_CAP
C4: 1nF; 0402_CAP
C5: 2.2nF; 0402_CAP
C6: 47nF; 0402_CAP
C7, C8: 0.1uF; 0402_CAP
C12: 1uF; 0402_CAP
C14: 4.7uF; 0402_CAP
D2: BLUE; LED-0603
J1, J2: TC2030-JLINK-NL; TC2030-IDC-NL
L1: 15nH; 0402_CAP
L2: 10uH; 0603_CAP
LOGO1: UMICH_SOLID_SMALL; UMICH_SOLID_75MIL
R1: 1k; 0402_RES
R4, R5: 10k; 0402_RES
R6: 12k; 0402_RES
TP1, TP2, TP3, TP4: TPTP06SQ; TP06SQ
U1: NRF51822QF; QFN-48-6MM
U2: TRIPOINT
X1: EPSON-FA-128; FA-128

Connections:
!CHRG1: D2.A, R1.1
ANTENNA: A4.1, B1.SE, C1.1
AVDD: C4.1, C12.1, L1.1, U1.35 (AVDD), U1.36 (AVDD)
BATIN: U1.5 (P01/AIN2); also elsewhere on the board
DCC: L2.2, U1.2 (DCC)
DW_INT: TP3.TP, U1.44 (P25), U2.38 (INTERRUPT)
GND: B1.GND, C1.2, C2.2, C3.2, C4.2, C5.2, C6.2, C7.2, C8.2, C12.2, C14.2, J1.5 (GND), J2.5 (GND), R6.1, TP4.TP, U1.13 (GND), U1.33 (GND), U1.34 (GND), U1.GND, U2.8 (GND), U2.10 (GND), U2.18 (GND), U2.25 (GND), U2.27 (GND), U2.42 (GND), U2.44 (GND), X1.2 (GND), X1.4 (GND); also elsewhere on the board
I2C_SCL: R5.1, TP1.TP, U1.47 (P28), U2.37 (SCL)
I2C_SDA: R4.1, TP2.TP, U1.48 (P29), U2.36 (SDA)
unnamed: A1.A, U2.9 (ANT1)
unnamed: A2..A, U2.26 (ANT2)
unnamed: A3.A, U2.43 (ANT3)
unnamed: J2.2 (SWDIO), U2.28 (SWDIO)
unnamed: D2.C, U1.25 (P17)
unnamed: J2.4 (SWDCLK), U2.29 (SWDCLK)
unnamed: J2.3 (!RESET), U2.30 (!RESET)
unnamed: C3.1, U1.37 (XC1), X1.1
unnamed: C2.1, U1.38 (XC2), X1.3 (2)
unnamed: C6.1, U1.29 (DEC2)
unnamed: C7.1, U1.39 (DEC1)
unnamed: B1.ANT1, U1.31 (ANT1)
unnamed: B1.ANT2, U1.32 (ANT2)
unnamed: B1.VCC (VDD_PA), C5.1, U1.30 (VDD_PA)
unnamed: L1.2, L2.1
SWDCLK: J1.4 (SWDCLK), R6.2, U1.24 (SWDCLK)
SWDIO/!RESET: J1.2 (SWDIO), U1.23 (SWDIO/!RESET)
VCC: C8.1, C14.1, J1.1 (VCC), J2.1 (VCC), R1.2, R4.2, R5.2, U1.1 (VDD), U1.12 (VDD), U2.17 (VCC); also elsewhere on the board

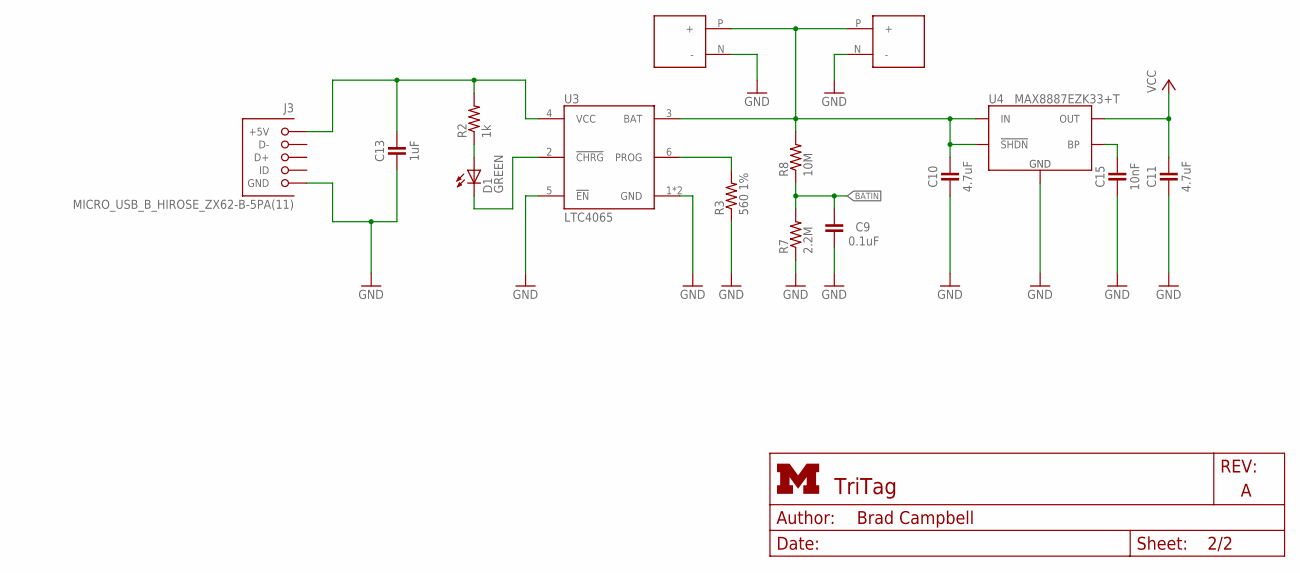
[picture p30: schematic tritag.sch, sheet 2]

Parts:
C9: 0.1uF; 0402_CAP
C10, C11: 4.7uF; 0402_CAP
C13: 1uF; 0402_CAP
C15: 10nF; 0402_CAP
D1: GREEN; LED-0603
J3: MICRO_USB_B_HIROSE_ZX62-B-5PA(11); USB_MICRO_B-HIROSE-ZX62-B-5PA(11)
J4, J5: BAT_HOLE; BATTERY_HOLE
R2: 1k; 0402_RES
R3: 560 1%; 0402_RES
R7: 2.2M; 0402_RES
R8: 10M; 0402_RES
U3: LTC4065; DFN-6/2MM
U4: MAX8887EZK33+T; SOT-23-5

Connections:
!CHRG: D1.A, R2.1
BATIN: C9.2, R7.2, R8.1; also elsewhere on the board
GND: C9.1, C10.2, C11.2, C13.2, C15.2, J3.5 (GND), J4.N (-), J5.N (-), R3.1, R7.1, U3.1 (GND), U3.5 (!EN), U3.7 (GND), U4.2 (GND); also elsewhere on the board
unnamed: D1.C, U3.2 (!CHRG)
unnamed: C15.1, U4.4 (BP)
unnamed: R3.2, U3.6 (PROG)
VBAT: C10.1, J4.P (+), J5.P (+), R8.2, U3.3 (BAT), U4.1 (IN), U4.3 (!SHDN)
VCC: C11.1, U4.5 (OUT); also elsewhere on the board
VUSB: C13.1, J3.1 (+5V), R2.2, U3.4 (VCC)

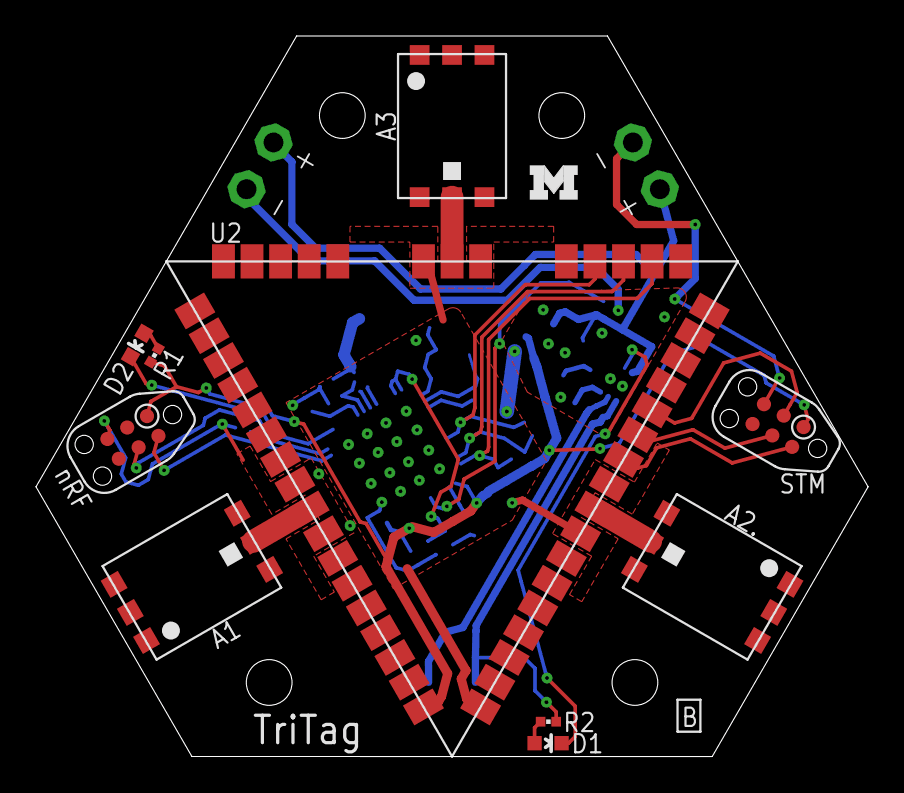
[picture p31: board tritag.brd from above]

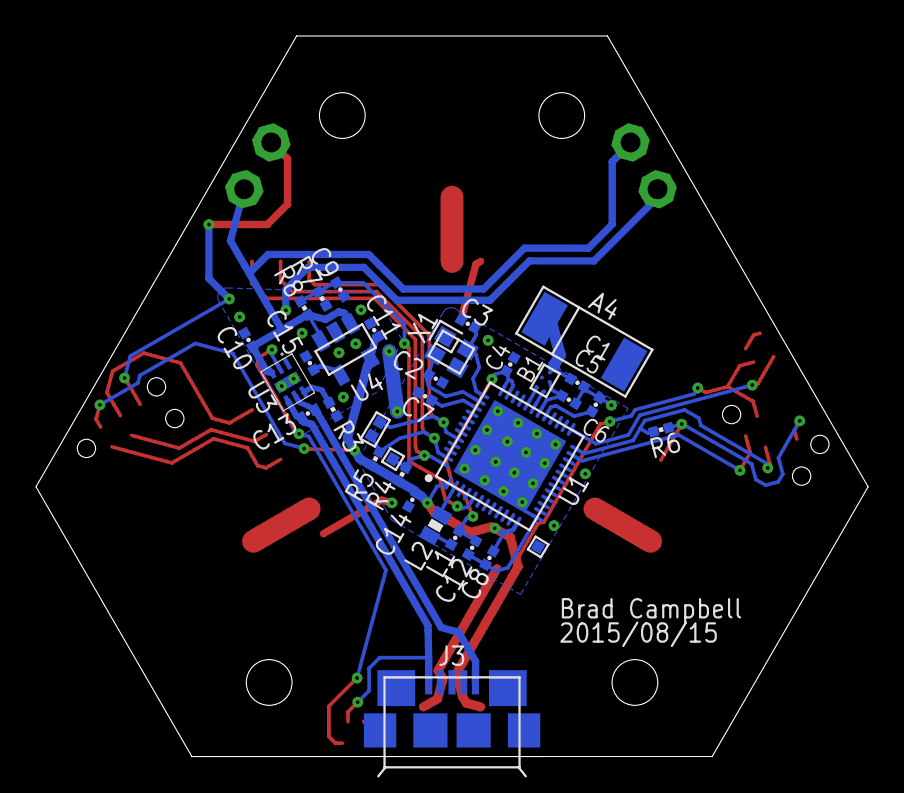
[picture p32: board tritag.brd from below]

Board: 2 copper layers, 46.2 x 40.0 mm, 47 parts (34 on the bottom side), 33 nets.

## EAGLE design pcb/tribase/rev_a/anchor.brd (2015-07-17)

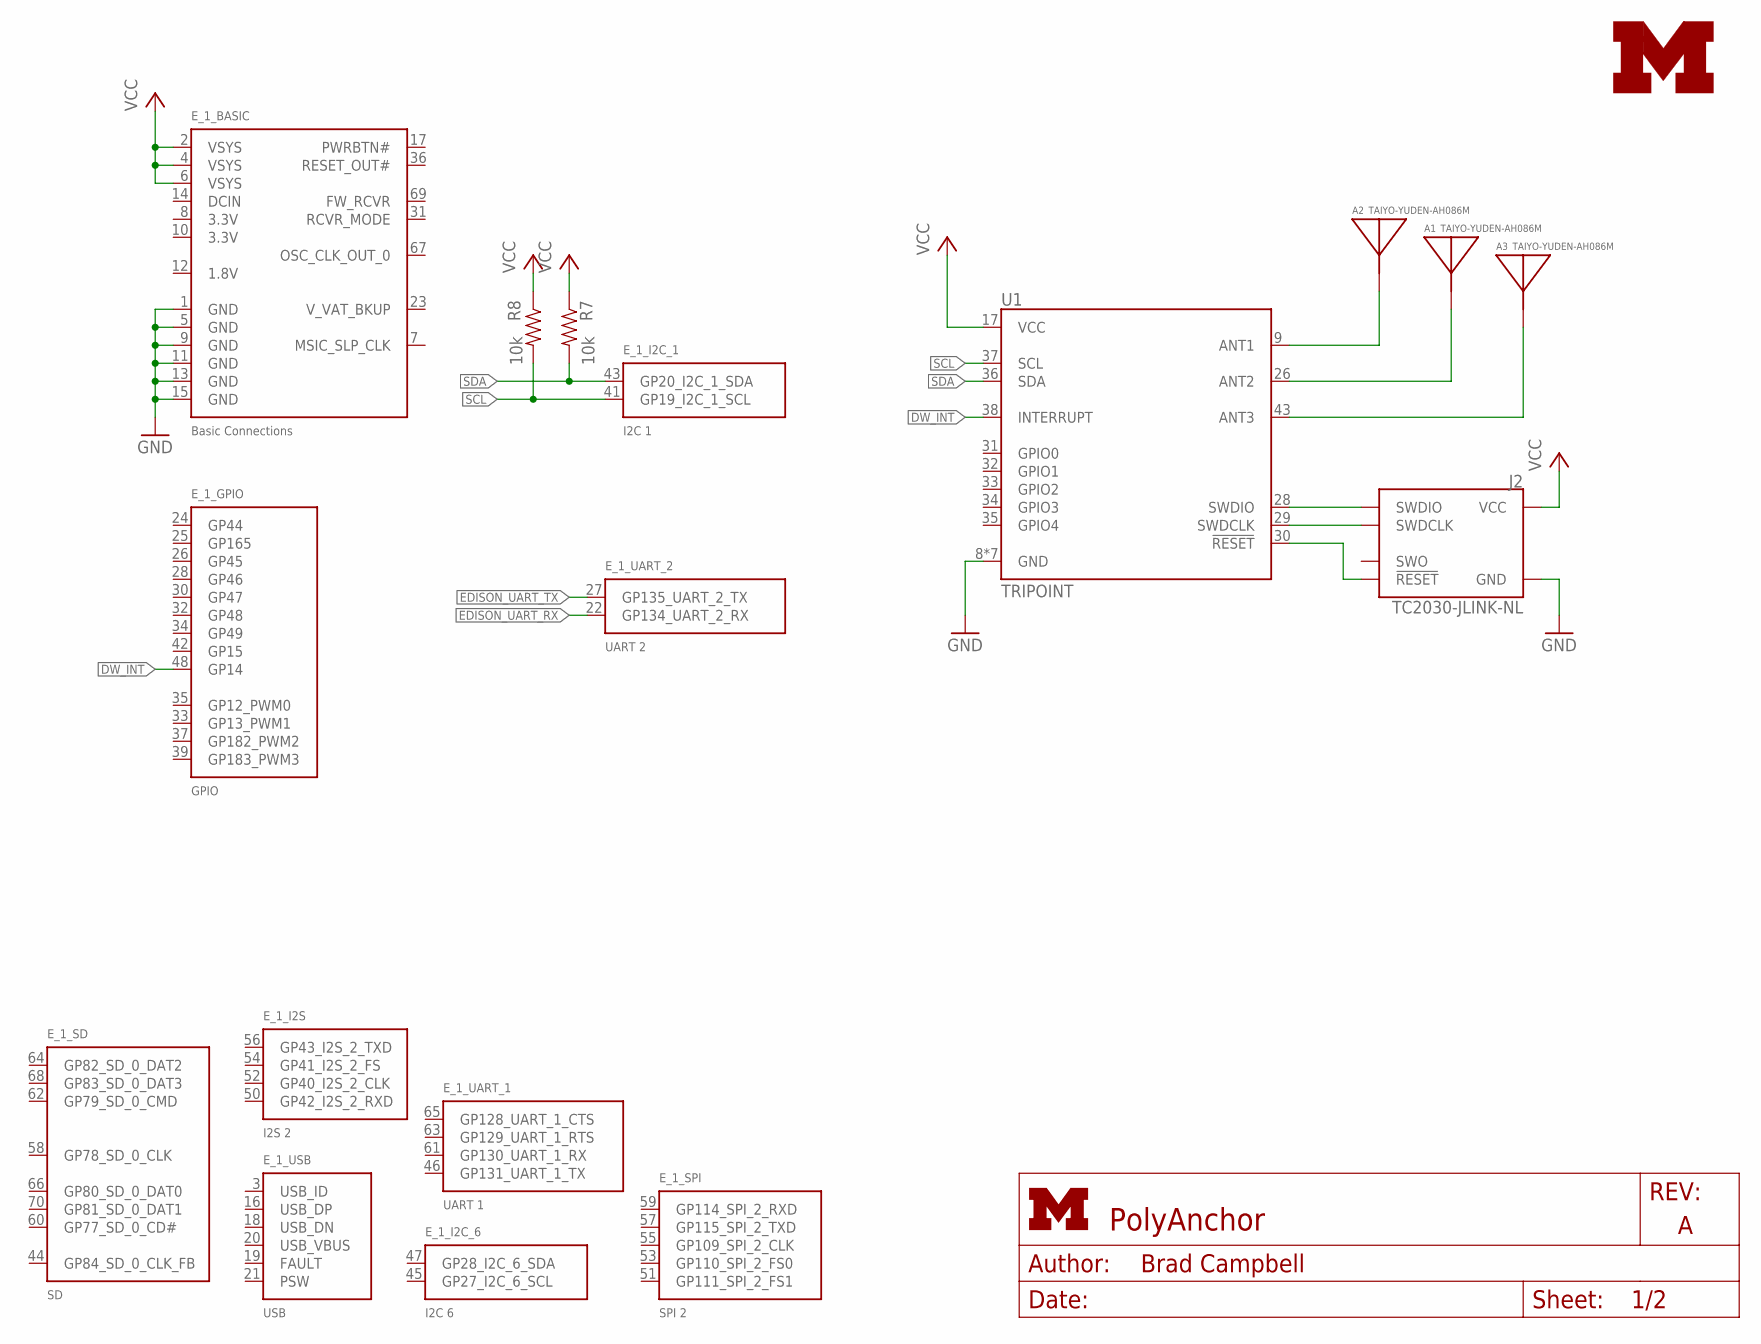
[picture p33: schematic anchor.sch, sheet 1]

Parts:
A1, A2, A3: TAIYO-YUDEN-AH086M
E_1: EDISON_CONNECTOR_SEGMENTED; EDISON_DAUGHTER
J2: TC2030-JLINK-NL; TC2030-IDC-NL
LOGO1: UMICH_SOLID_MEDIUM; UMICH_SOLID_200MIL
R7, R8: 10k; 0402_RES
U1: TRIPOINT

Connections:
DW_INT: E_1.48 (GP14), U1.38 (INTERRUPT)
EDISON_UART_RX: E_1.22 (GP134_UART_2_RX); also elsewhere on the board
EDISON_UART_TX: E_1.27 (GP135_UART_2_TX); also elsewhere on the board
GND: E_1.1 (GND), E_1.5 (GND), E_1.9 (GND), E_1.11 (GND), E_1.13 (GND), E_1.15 (GND), J2.5 (GND), U1.8 (GND), U1.10 (GND), U1.18 (GND), U1.25 (GND), U1.27 (GND), U1.42 (GND), U1.44 (GND); also elsewhere on the board
unnamed: J2.2 (SWDIO), U1.28 (SWDIO)
unnamed: A2.A, U1.9 (ANT1)
unnamed: A1.A, U1.26 (ANT2)
unnamed: A3.A, U1.43 (ANT3)
unnamed: J2.4 (SWDCLK), U1.29 (SWDCLK)
unnamed: J2.3 (!RESET), U1.30 (!RESET)
SCL: E_1.41 (GP19_I2C_1_SCL), R8.2, U1.37 (SCL)
SDA: E_1.43 (GP20_I2C_1_SDA), R7.2, U1.36 (SDA)
VCC: E_1.2 (VSYS), E_1.4 (VSYS), E_1.6 (VSYS), J2.1 (VCC), R7.1, R8.1, U1.17 (VCC); also elsewhere on the board

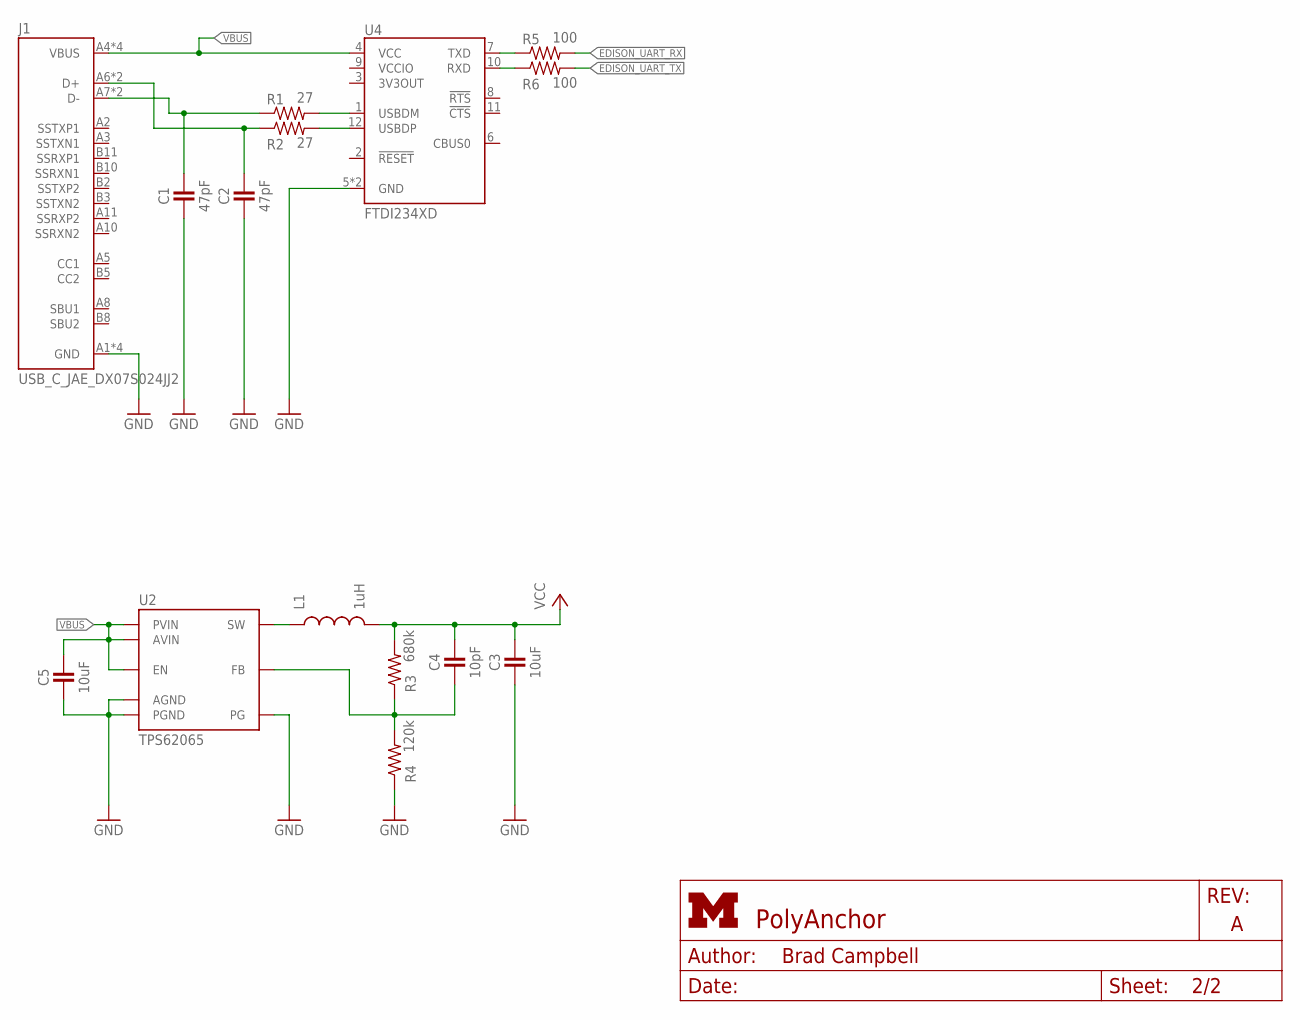
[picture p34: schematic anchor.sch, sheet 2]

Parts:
C1, C2: 47pF; 0402_CAP
C3, C5: 10uF; 0603_CAP; DIGIKEY 490-6405-1-ND
C4: 10pF; 0402_CAP
J1: USB_C_JAE_DX07S024JJ2; DX07S024JJ2
L1: 1uH; 1210; DIGIKEY 490-10767-1-ND
R1, R2: 27; 0402_RES
R3: 680k; 0402_RES
R4: 120k; 0402_RES
R5, R6: 100; 0402_RES
U2: TPS62065; S-PWSON-N8
U4: FTDI234XD; DFN-12/3MM

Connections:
D+: C2.1, J1.A6 (D+), J1.B6 (D+), R2.1
D-: C1.1, J1.A7 (D-), J1.B7 (D-), R1.1
EDISON_UART_RX: R5.2; also elsewhere on the board
EDISON_UART_TX: R6.2; also elsewhere on the board
GND: C1.2, C2.2, C3.2, C5.2, J1.A1 (GND), J1.A12 (GND), J1.B1 (GND), J1.B12 (GND), R4.1, U2.1 (PGND), U2.3 (AGND), U2.6 (PG), U2.P$1 (PGND), U4.5 (GND), U4.13 (GND); also elsewhere on the board
unnamed: L1.1, U2.2 (SW)
unnamed: R5.1, U4.7 (TXD)
unnamed: R1.2, U4.1 (USBDM)
unnamed: R2.2, U4.12 (USBDP)
unnamed: C4.2, R3.1, R4.2, U2.4 (FB)
unnamed: R6.1, U4.10 (RXD)
VBUS: C5.1, J1.A4 (VBUS), J1.A9 (VBUS), J1.B4 (VBUS), J1.B9 (VBUS), U2.5 (EN), U2.7 (AVIN), U2.8 (PVIN), U4.4 (VCC)
VCC: C3.1, C4.1, L1.2, R3.2; also elsewhere on the board

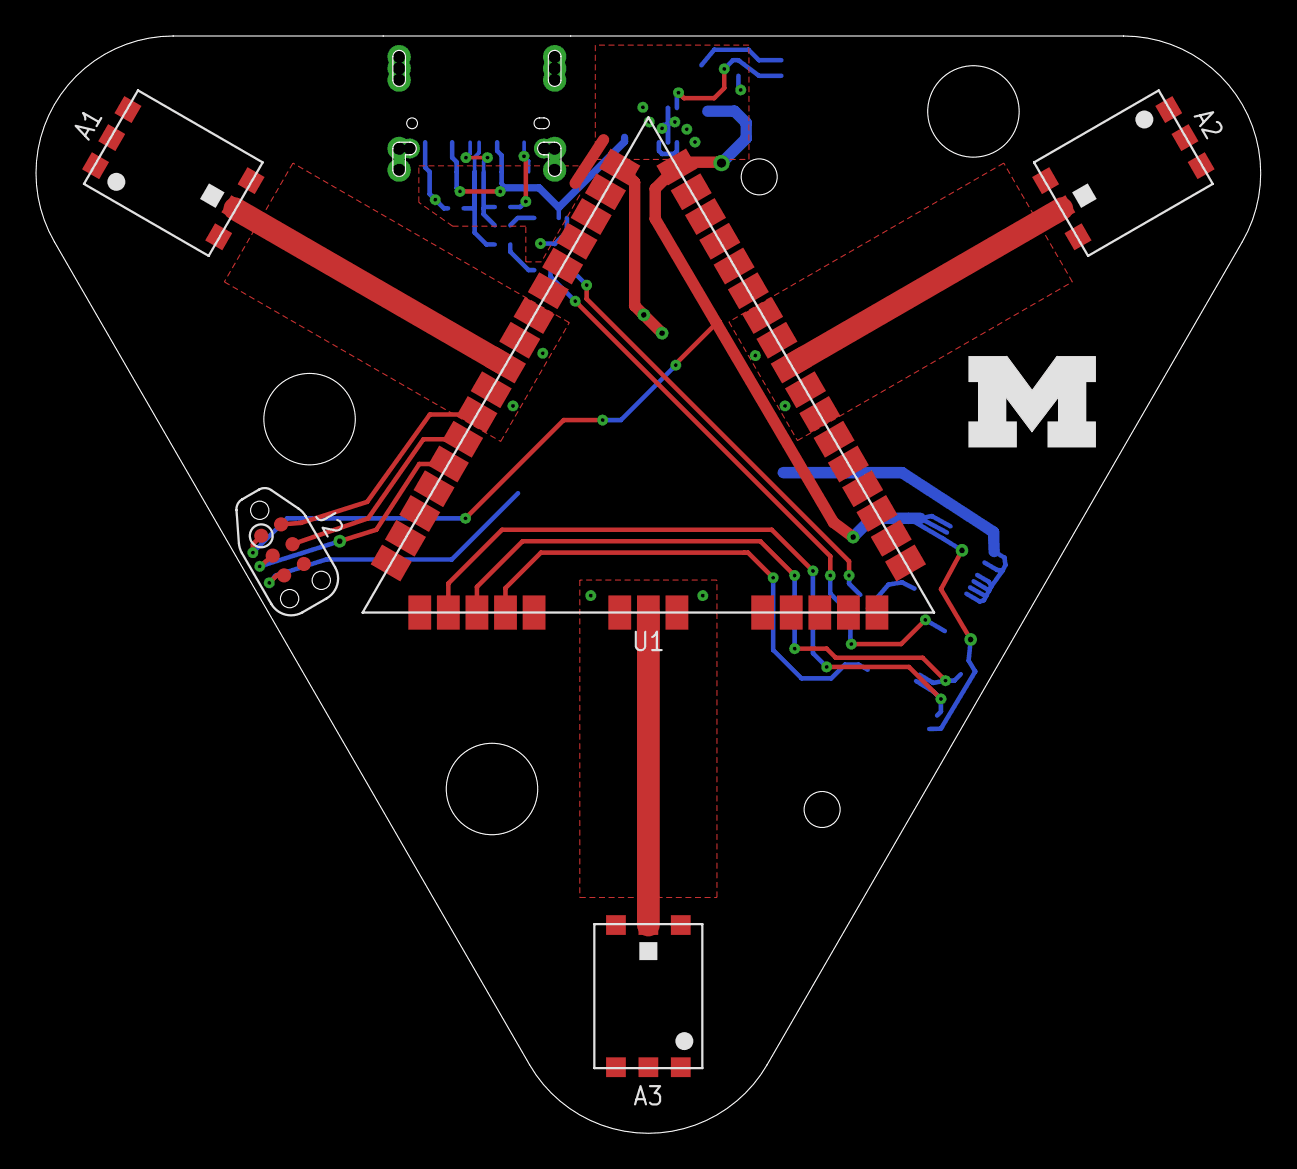
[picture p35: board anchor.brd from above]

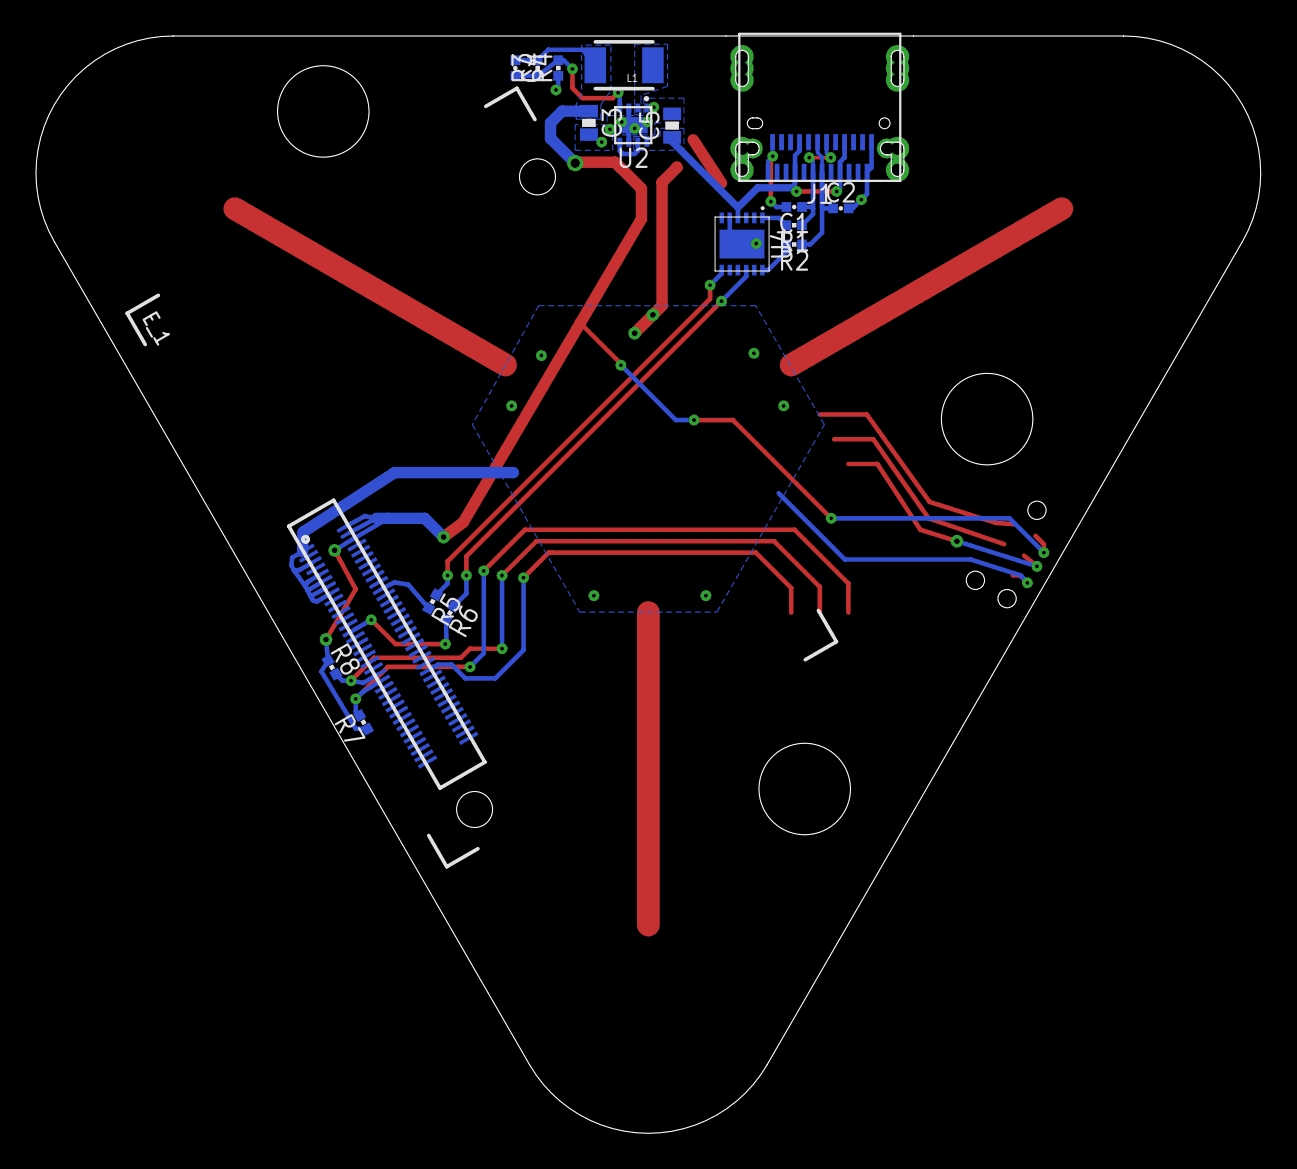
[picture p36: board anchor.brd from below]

Board: 2 copper layers, 68.0 x 61.0 mm, 24 parts (18 on the bottom side), 22 nets.

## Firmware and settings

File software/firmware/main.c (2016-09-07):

#include <string.h>

#include "stm32f0xx_tim.h"
#include "stm32f0xx_pwr.h"
#include "stm32f0xx_usart.h"

#include "tripoint.h"
#include "led.h"

#include "host_interface.h"
#include "dw1000.h"
#include "oneway_common.h"
#include "oneway_tag.h"
#include "oneway_anchor.h"
#include "timer.h"
#include "delay.h"
#include "firmware.h"

/******************************************************************************/
// OS state
/******************************************************************************/

// Array of interrupt sources. When an interrupt fires, this array gets marked
// noting that the interrupt fired. The main thread then processes this array
// to get all of the functions it should call.
bool interrupts_triggered[NUMBER_INTERRUPT_SOURCES]  = {FALSE};


/******************************************************************************/
// Current application state
/******************************************************************************/
// Keep track of if the application is active or not
static app_state_e _state = APPSTATE_NOT_INITED;

// Keep track of what application we are running
static polypoint_application_e _current_app;

// Timer for doing periodic operations (like TAG ranging events)
static stm_timer_t* _app_timer;


void start_dw1000 ();

/******************************************************************************/
// "OS" like functions
/******************************************************************************/

// This gets called from interrupt context.
// TODO: Changing interrupts_triggered should be in an atomic block as it is
//       also read from the main loop on the main thread.
void mark_interrupt (interrupt_source_e src) {
	interrupts_triggered[src] = TRUE;
}

static void error () {
	GPIO_WriteBit(STM_GPIO3_PORT, STM_GPIO3_PIN, Bit_SET);
	GPIO_WriteBit(STM_GPIO3_PORT, STM_GPIO3_PIN, Bit_RESET);
}

union app_scratchspace {
	oneway_tag_scratchspace_struct ot_scratch;
	oneway_anchor_scratchspace_struct oa_scratch;
} _app_scratchspace;

/******************************************************************************/
// Main operation functions called by the host interface
/******************************************************************************/

// Call this to configure this TriPoint as the correct application.
// If this is called while the application is stopped, it will not be
// automatically started.
// If this is called when the app is running, the app will be restarted.
void polypoint_configure_app (polypoint_application_e app, void* app_config) {
	bool resume = FALSE;

	// Check if this application is running.
	if (_state == APPSTATE_RUNNING) {
		// Resume with new settings.
		resume = TRUE;
		// Stop this first
		polypoint_stop();
	}

	// Set scratchspace to known zeros
	memset(&_app_scratchspace, 0, sizeof(_app_scratchspace));

	// Tell the correct application that it should init()
	_current_app = app;
	switch (_current_app) {
		case APP_ONEWAY:
			oneway_configure((oneway_config_t*) app_config, NULL, (void*)&_app_scratchspace);
			break;

		default:
			break;
	}

	// We were running when this function was called, so we start things back
	// up here.
	if (resume) {
		polypoint_start();
	}
}


// Start this node! This will run the anchor and tag algorithms.
void polypoint_start () {
	// Don't start if we are already started
	if (_state == APPSTATE_RUNNING) {
		return;
	}

	_state = APPSTATE_RUNNING;

	switch (_current_app) {
		case APP_ONEWAY:
			oneway_start();
			break;

		default:
			break;
	}
}

// This is called when the host tells us to sleep
void polypoint_stop () {
	// Don't stop if we are already stopped
	if (_state == APPSTATE_STOPPED) {
		return;
	}

	_state = APPSTATE_STOPPED;

	switch (_current_app) {
		case APP_ONEWAY:
			oneway_stop();
			break;

		default:
			break;
	}
}

// Drop the big hammer on the DW1000 and reset the chip (along with the app).
// All state should be preserved, so after the reset the tripoint should go
// back to what it was doing, just after a reset and re-init of the dw1000.
void polypoint_reset () {
	bool resume = FALSE;

	if (_state == APPSTATE_RUNNING) {
		resume = TRUE;
	}

	// Put the app back in the not inited state
	_state = APPSTATE_NOT_INITED;

	// Stop the timer in case it was in use.
	//timer_stop(_app_timer);

	// Init the dw1000, and loop until it works.
	// start does a reset.
	start_dw1000();

	// Re init the app
	switch (_current_app) {
		case APP_ONEWAY:
			oneway_reset();
			break;

		default:
			break;
	}

	if (resume) {
		polypoint_start();
	}
}

// Return true if we are good for app_configure
// to be called, false otherwise.
bool polypoint_ready () {
	return _state != APPSTATE_NOT_INITED;
}

// Assuming we are a TAG, and we are in on-demand ranging mode, tell
// the dw1000 algorithm to perform a range.
void polypoint_tag_do_range () {
	// If the application isn't running, we are not a tag, or we are not
	// in on-demand ranging mode, don't do anything.
	if (_state != APPSTATE_RUNNING) {
		return;
	}

	// Call the relevant function based on the current application
	switch (_current_app) {
		case APP_ONEWAY:
			oneway_do_range();
			break;

		case APP_CALIBRATION:
			// Not a thing for this app
			break;

		default:
			break;
	}
}


/******************************************************************************/
// Connection for the anchor/tag code to talk to the main applications
/******************************************************************************/





/******************************************************************************/
// Main
/******************************************************************************/

// Loop until the DW1000 is inited and ready to go.
// TODO: this really shouldn't be blocking as it messes with the I2C interrupt
//       code.
void start_dw1000 () {
	uint32_t err;

	while (1) {
		// Do some preliminary setup of the DW1000. This mostly configures
		// pins and hardware peripherals, as well as straightening out some
		// of the settings on the DW1000.
		uint8_t tries = 0;
		do {
			err = dw1000_init();
			if (err) {
				uDelay(10000);
				tries++;
			}
		} while (err && tries <= DW1000_NUM_CONTACT_TRIES_BEFORE_RESET);

		if (err) {
			// We never got the DW1000 to respond. This puts us in a really
			// bad spot. Maybe if we just wait for a while things will get
			// better?
			mDelay(50000);
		} else {
			// Success
			break;
		}
	}

	// Successfully started the DW1000
	_state = APPSTATE_STOPPED;
}


int main () {
	uint32_t err;
	bool interrupt_triggered = FALSE;

	// Enable PWR APB clock
	// Not entirely sure why.
	RCC_APB1PeriphClockCmd(RCC_APB1Periph_PWR, ENABLE);


	GPIO_InitTypeDef GPIO_InitStructure;
	RCC_AHBPeriphClockCmd(STM_GPIO3_CLK, ENABLE);
	GPIO_InitStructure.GPIO_Pin = STM_GPIO3_PIN;
	GPIO_InitStructure.GPIO_Mode = GPIO_Mode_OUT;
	GPIO_InitStructure.GPIO_OType = GPIO_OType_PP;
	GPIO_InitStructure.GPIO_Speed = GPIO_Speed_50MHz;
	GPIO_InitStructure.GPIO_PuPd = GPIO_PuPd_NOPULL;
	GPIO_Init(STM_GPIO3_PORT, &GPIO_InitStructure);
	GPIO_WriteBit(STM_GPIO3_PORT, STM_GPIO3_PIN, Bit_RESET);
	GPIO_WriteBit(STM_GPIO3_PORT, STM_GPIO3_PIN, Bit_SET);
	GPIO_WriteBit(STM_GPIO3_PORT, STM_GPIO3_PIN, Bit_RESET);


	//Initialize UART1 on GPIO1 and GPIO4
	{
		USART_InitTypeDef usartConfig;
		GPIO_InitTypeDef gpioConfig;

		RCC_AHBPeriphClockCmd(RCC_AHBPeriph_GPIOB, ENABLE);
		RCC_APB2PeriphClockCmd(RCC_APB2Periph_USART1, ENABLE);

		GPIO_PinAFConfig(GPIOB, GPIO_PinSource6, GPIO_AF_0);
		GPIO_PinAFConfig(GPIOB, GPIO_PinSource7, GPIO_AF_0);

		gpioConfig.GPIO_Pin = GPIO_Pin_6 | GPIO_Pin_7;
		gpioConfig.GPIO_Speed = GPIO_Speed_50MHz;
		gpioConfig.GPIO_Mode = GPIO_Mode_AF;
		gpioConfig.GPIO_OType = GPIO_OType_PP;
		gpioConfig.GPIO_PuPd = GPIO_PuPd_UP;
		GPIO_Init(GPIOB, &gpioConfig);

		// STM "baud" defn wrong; this results in 3 MBaud effective
		usartConfig.USART_BaudRate = 1500000;
		usartConfig.USART_WordLength = USART_WordLength_8b;
		usartConfig.USART_StopBits = USART_StopBits_1;
		usartConfig.USART_Parity = USART_Parity_No;
		usartConfig.USART_Mode = USART_Mode_Rx | USART_Mode_Tx;
		usartConfig.USART_HardwareFlowControl = USART_HardwareFlowControl_None;
		USART_Init(USART1, &usartConfig);

		USART_Cmd(USART1, ENABLE);
	}

	// In case we need a timer, get one. This is used for things like periodic
	// ranging events.
	//_app_timer = timer_init();

	// Next up do some preliminary setup of the DW1000. This mostly configures
	// pins and hardware peripherals, as well as straightening out some
	// of the settings on the DW1000.
	start_dw1000();

#ifndef BYPASS_HOST_INTERFACE
	// Initialize the I2C listener. This is the main interface
	// the host controller (that is using TriPoint for ranging/localization)
	// uses to configure how this module operates.
	err = host_interface_init();
	if (err) error();

	// Need to wait for the host board to tell us what to do.
	err = host_interface_wait();
	if (err) error();
#else

	// DEBUG:
	oneway_config_t config;
	config.my_role = TAG;
	//config.my_role = ANCHOR;
	//config.my_glossy_role = GLOSSY_MASTER;
	config.my_glossy_role = GLOSSY_SLAVE;
	config.report_mode = ONEWAY_REPORT_MODE_RANGES;
	config.update_mode = ONEWAY_UPDATE_MODE_PERIODIC;
	config.update_rate = 10;
	config.sleep_mode = FALSE;
	polypoint_configure_app(APP_ONEWAY, &config);
	polypoint_start();
#endif

	// MAIN LOOP
	while (1) {

		PWR_EnterSleepMode(PWR_SLEEPEntry_WFI);
		// PWR_EnterSTOPMode(PWR_Regulator_LowPower, PWR_STOPEntry_WFI);

		GPIO_WriteBit(STM_GPIO3_PORT, STM_GPIO3_PIN, Bit_SET);
		GPIO_WriteBit(STM_GPIO3_PORT, STM_GPIO3_PIN, Bit_RESET);

		// When an interrupt fires we end up here.
		// Check all of the interrupt "queues" and call the appropriate
		// callbacks for all of the interrupts that have fired.
		// Do this in a loop in case we get an interrupt during the
		// checks.
		do {
			interrupt_triggered = FALSE;

			if (interrupts_triggered[INTERRUPT_TIMER_17] == TRUE) {
				interrupts_triggered[INTERRUPT_TIMER_17] = FALSE;
				interrupt_triggered = TRUE;
				timer_17_fired();
			}

			if (interrupts_triggered[INTERRUPT_TIMER_16] == TRUE) {
				interrupts_triggered[INTERRUPT_TIMER_16] = FALSE;
				interrupt_triggered = TRUE;
				timer_16_fired();
			}

			if (interrupts_triggered[INTERRUPT_DW1000] == TRUE) {
				interrupts_triggered[INTERRUPT_DW1000] = FALSE;
				interrupt_triggered = TRUE;
				dw1000_interrupt_fired();
			}

			if (interrupts_triggered[INTERRUPT_I2C_RX] == TRUE) {
				interrupts_triggered[INTERRUPT_I2C_RX] = FALSE;
				interrupt_triggered = TRUE;
				host_interface_rx_fired();
			}

			if (interrupts_triggered[INTERRUPT_I2C_TX] == TRUE) {
				interrupts_triggered[INTERRUPT_I2C_TX] = FALSE;
				interrupt_triggered = TRUE;
				host_interface_tx_fired();
			}

			if (interrupts_triggered[INTERRUPT_I2C_TIMEOUT] == TRUE) {
				interrupts_triggered[INTERRUPT_I2C_TIMEOUT] = FALSE;
				interrupt_triggered = TRUE;
				host_interface_timeout_fired();
			}
		} while (interrupt_triggered == TRUE);
	}

	return 0;
}

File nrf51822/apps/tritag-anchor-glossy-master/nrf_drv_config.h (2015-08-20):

/* Copyright (c) 2015 Nordic Semiconductor. All Rights Reserved.
 *
 * The information contained herein is property of Nordic Semiconductor ASA.
 * Terms and conditions of usage are described in detail in NORDIC
 * SEMICONDUCTOR STANDARD SOFTWARE LICENSE AGREEMENT.
 *
 * Licensees are granted free, non-transferable use of the information. NO
 * WARRANTY of ANY KIND is provided. This heading must NOT be removed from
 * the file.
 *
 */

#ifndef NRF_DRV_CONFIG_H
#define NRF_DRV_CONFIG_H

/* CLOCK */
#define CLOCK_CONFIG_XTAL_FREQ          NRF_CLOCK_XTALFREQ_16MHz
#define CLOCK_CONFIG_LF_SRC             NRF_CLOCK_LF_SRC_Xtal
#define CLOCK_CONFIG_LF_RC_CAL_INTERVAL RC_2000MS_CALIBRATION_INTERVAL
#define CLOCK_CONFIG_IRQ_PRIORITY       APP_IRQ_PRIORITY_LOW

/* GPIOTE */
#define GPIOTE_ENABLED 1

#if (GPIOTE_ENABLED == 1)
#define GPIOTE_CONFIG_USE_SWI_EGU false
#define GPIOTE_CONFIG_IRQ_PRIORITY APP_IRQ_PRIORITY_HIGH
#define GPIOTE_CONFIG_NUM_OF_LOW_POWER_EVENTS 1
#endif

/* TIMER */
#define TIMER0_ENABLED 0

#if (TIMER0_ENABLED == 1)
#define TIMER0_CONFIG_FREQUENCY    NRF_TIMER_FREQ_16MHz
#define TIMER0_CONFIG_MODE         TIMER_MODE_MODE_Timer
#define TIMER0_CONFIG_BIT_WIDTH    TIMER_BITMODE_BITMODE_32Bit
#define TIMER0_CONFIG_IRQ_PRIORITY APP_IRQ_PRIORITY_LOW

#define TIMER0_INSTANCE_INDEX      0
#endif

#define TIMER1_ENABLED 0

#if (TIMER1_ENABLED == 1)
#define TIMER1_CONFIG_FREQUENCY    NRF_TIMER_FREQ_16MHz
#define TIMER1_CONFIG_MODE         TIMER_MODE_MODE_Timer
#define TIMER1_CONFIG_BIT_WIDTH    TIMER_BITMODE_BITMODE_16Bit
#define TIMER1_CONFIG_IRQ_PRIORITY APP_IRQ_PRIORITY_LOW

#define TIMER1_INSTANCE_INDEX      (TIMER0_ENABLED)
#endif

#define TIMER2_ENABLED 0

#if (TIMER2_ENABLED == 1)
#define TIMER2_CONFIG_FREQUENCY    NRF_TIMER_FREQ_16MHz
#define TIMER2_CONFIG_MODE         TIMER_MODE_MODE_Timer
#define TIMER2_CONFIG_BIT_WIDTH    TIMER_BITMODE_BITMODE_16Bit
#define TIMER2_CONFIG_IRQ_PRIORITY APP_IRQ_PRIORITY_LOW

#define TIMER2_INSTANCE_INDEX      (TIMER1_ENABLED+TIMER0_ENABLED)
#endif

#define TIMER_COUNT (TIMER0_ENABLED + TIMER1_ENABLED + TIMER2_ENABLED)

/* RTC */
#define RTC0_ENABLED 0

#if (RTC0_ENABLED == 1)
#define RTC0_CONFIG_FREQUENCY    32678
#define RTC0_CONFIG_IRQ_PRIORITY APP_IRQ_PRIORITY_LOW
#define RTC0_CONFIG_RELIABLE     false

#define RTC0_INSTANCE_INDEX      0
#endif

#define RTC1_ENABLED 0

#if (RTC1_ENABLED == 1)
#define RTC1_CONFIG_FREQUENCY    32768
#define RTC1_CONFIG_IRQ_PRIORITY APP_IRQ_PRIORITY_LOW
#define RTC1_CONFIG_RELIABLE     false

#define RTC1_INSTANCE_INDEX      (RTC0_ENABLED)
#endif

#define RTC_COUNT                (RTC0_ENABLED+RTC1_ENABLED)

#define NRF_MAXIMUM_LATENCY_US 2000

/* RNG */
#define RNG_ENABLED 0

#if (RNG_ENABLED == 1)
#define RNG_CONFIG_ERROR_CORRECTION true
#define RNG_CONFIG_POOL_SIZE        8
#define RNG_CONFIG_IRQ_PRIORITY     APP_IRQ_PRIORITY_LOW
#endif

/* TWI */
#define TWI0_ENABLED 0

#if (TWI0_ENABLED == 1)
#define TWI0_CONFIG_FREQUENCY    NRF_TWI_FREQ_100K
#define TWI0_CONFIG_SCL          0
#define TWI0_CONFIG_SDA          1
#define TWI0_CONFIG_IRQ_PRIORITY APP_IRQ_PRIORITY_HIGH

#define TWI0_INSTANCE_INDEX      0
#endif

#define TWI1_ENABLED 1

#if (TWI1_ENABLED == 1)
#define TWI1_CONFIG_FREQUENCY NRF_TWI_FREQ_250K
#define TWI1_CONFIG_SCL          0
#define TWI1_CONFIG_SDA          1
#define TWI1_CONFIG_IRQ_PRIORITY APP_IRQ_PRIORITY_LOW

#define TWI1_INSTANCE_INDEX      (TWI0_ENABLED)
#endif

#define TWI_COUNT                (TWI0_ENABLED+TWI1_ENABLED)

/* QDEC */
#define QDEC_ENABLED 0

#if (QDEC_ENABLED == 1)
#define QDEC_CONFIG_REPORTPER    NRF_QDEC_REPORTPER_10
#define QDEC_CONFIG_SAMPLEPER    NRF_QDEC_SAMPLEPER_16384us
#define QDEC_CONFIG_PIO_A        1
#define QDEC_CONFIG_PIO_B        2
#define QDEC_CONFIG_PIO_LED      3
#define QDEC_CONFIG_LEDPRE       511
#define QDEC_CONFIG_LEDPOL       NRF_QDEC_LEPOL_ACTIVE_HIGH
#define QDEC_CONFIG_IRQ_PRIORITY APP_IRQ_PRIORITY_LOW
#define QDEC_CONFIG_DBFEN        false
#define QDEC_CONFIG_SAMPLE_INTEN false
#endif

/* LPCOMP */
#define LPCOMP_ENABLED 0

#if (LPCOMP_ENABLED == 1)
#define LPCOMP_CONFIG_REFERENCE    NRF_LPCOMP_REF_SUPPLY_FOUR_EIGHT
#define LPCOMP_CONFIG_DETECTION    NRF_LPCOMP_DETECT_DOWN
#define LPCOMP_CONFIG_IRQ_PRIORITY APP_IRQ_PRIORITY_LOW
#define LPCOMP_CONFIG_INPUT        NRF_LPCOMP_INPUT_0
#endif

/* WDT */
#define WDT_ENABLED 0

#if (WDT_ENABLED == 1)
#define WDT_CONFIG_BEHAVIOUR     NRF_WDT_BEHAVIOUR_RUN_SLEEP
#define WDT_CONFIG_RELOAD_VALUE  2000
#define WDT_CONFIG_IRQ_PRIORITY  APP_IRQ_PRIORITY_HIGH
#endif

#endif // NRF_DRV_CONFIG_H

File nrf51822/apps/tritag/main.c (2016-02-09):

/*

  UWB Localization Tag

*/

#include <stdint.h>
#include <stdio.h>
#include <string.h>
#include "nordic_common.h"
#include "nrf.h"
#include "nrf_sdm.h"
#include "nrf_delay.h"
#include "ble.h"
#include "ble_db_discovery.h"
#include "softdevice_handler.h"
#include "app_util.h"
#include "app_error.h"
#include "ble_advdata_parser.h"
#include "ble_conn_params.h"
#include "ble_hci.h"
#include "boards.h"
#include "nrf_gpio.h"
#include "pstorage.h"
#include "app_trace.h"
#include "ble_hrs_c.h"
#include "ble_bas_c.h"
#include "app_util.h"
#include "app_timer.h"

#include "simple_ble.h"
#include "eddystone.h"

#include "led.h"
#include "boards.h"

#include "ble_config.h"
#include "tripoint_interface.h"

/*******************************************************************************
 *   Configuration and settings
 ******************************************************************************/


#define TRITAG_SHORT_UUID                     0x3152
#define TRITAG_CHAR_LOCATION_SHORT_UUID       0x3153
#define TRITAG_CHAR_RANGING_ENABLE_SHORT_UUID 0x3154
#define TRITAG_CHAR_CALIBRATION_SHORT_UUID    0x3159
#define TRITAG_CHAR_STATUS_SHORT_UUID         0x3155

// Randomly generated UUID
simple_ble_service_t service_handle = {
    .uuid128 = {{0x2e, 0x5d, 0x5e, 0x39, 0x31, 0x52, 0x45, 0x0c,
                 0x90, 0xee, 0x3f, 0xa2, 0x31, 0x52, 0x8c, 0xd6}}
};
simple_ble_char_t char_range_handle             = {.uuid16 = TRITAG_CHAR_LOCATION_SHORT_UUID};
simple_ble_char_t char_calibration_index_handle = {.uuid16 = TRITAG_CHAR_CALIBRATION_SHORT_UUID};
simple_ble_char_t char_ranging_enable_handle    = {.uuid16 = TRITAG_CHAR_RANGING_ENABLE_SHORT_UUID};
simple_ble_char_t char_status_handle            = {.uuid16 = TRITAG_CHAR_STATUS_SHORT_UUID};


// Intervals for advertising and connections
static simple_ble_config_t ble_config = {
    // c0:98:e5:45:xx:xx
    .platform_id       = 0x45,              // used as 4th octect in device BLE address
    .device_id         = DEVICE_ID_DEFAULT,
    .adv_name          = DEVICE_NAME,       // used in advertisements if there is room
    .adv_interval      = MSEC_TO_UNITS(1000, UNIT_0_625_MS),
    // .min_conn_interval = MSEC_TO_UNITS(500, UNIT_1_25_MS),
    // .max_conn_interval = MSEC_TO_UNITS(1000, UNIT_1_25_MS),
    .min_conn_interval = MSEC_TO_UNITS(8, UNIT_1_25_MS),
    .max_conn_interval = MSEC_TO_UNITS(10, UNIT_1_25_MS),
};

// Copy address from flash
uint8_t _ble_address[6];

/*******************************************************************************
 *   State for this application
 ******************************************************************************/
 // Main application state
simple_ble_app_t* simple_ble_app;
static ble_app_t app;

// GP Timer. Used to retry initializing the TriPoint.
static app_timer_id_t  app_timer;

// Whether or not we successfully got through to the TriPoint module
// and got it configured properly.
bool tripoint_inited = false;



/*******************************************************************************
 *   nRF CALLBACKS - In response to various BLE/hardware events.
 ******************************************************************************/

// Function for handling the WRITE CHARACTERISTIC BLE event.
void ble_evt_write (ble_evt_t* p_ble_evt) {
    ble_gatts_evt_write_t* p_evt_write = &p_ble_evt->evt.gatts_evt.params.write;

    if (simple_ble_is_char_event(p_ble_evt, &char_ranging_enable_handle)) {
        // Handle a write to the characteristic that starts and stops
        // TriPoint ranging.

        app.app_ranging = p_evt_write->data[0];

        // Stop or start the tripoint based on the value we just got
        if (app.app_ranging == 1) {
            tripoint_resume();
        } else {
            tripoint_sleep();
        }

    } else if (simple_ble_is_char_event(p_ble_evt, &char_calibration_index_handle)) {
        // Handle a write to the characteristic that starts calibration
        app.calibration_index = p_evt_write->data[0];

        // Configure this node for calibration and set the calibration node
        // index. If 0, this node will immediately start calibration.
        tripoint_start_calibration(app.calibration_index);
    }
}



/*******************************************************************************
 *   PolyPoint Callbacks
 ******************************************************************************/

uint8_t updated = 0;
uint32_t blobLen;
uint8_t dataBlob[256];

void updateData (uint8_t * data, uint32_t len) {
    uint32_t copy_len = MIN(len, 256);
	memcpy(app.app_raw_response_buffer, data, copy_len);
	blobLen = copy_len;

	updated = 1;
}


void tripointDataUpdate () {
    //update the data value and notify on the data
	if (blobLen >= 5) {
        led_on(LED_0);
        nrf_delay_us(1000);
		led_off(LED_0);
	}

	if(simple_ble_app->conn_handle != BLE_CONN_HANDLE_INVALID) {

		ble_gatts_hvx_params_t notify_params;
		uint16_t len = blobLen;
        notify_params.handle = char_range_handle.char_handle.value_handle;
		notify_params.type   = BLE_GATT_HVX_NOTIFICATION;
		notify_params.offset = 0;
		notify_params.p_len  = &len;
		notify_params.p_data = app.app_raw_response_buffer;

		// volatile uint32_t err_code = 0;
        // err_code = sd_ble_gatts_hvx(simple_ble_app->conn_handle, &notify_params);
		sd_ble_gatts_hvx(simple_ble_app->conn_handle, &notify_params);
        // APP_ERROR_CHECK(err_code);
	}

	updated = 0;
}

static void timer_handler (void* p_context) {
    uint32_t err_code;

    if (!tripoint_inited) {
        err_code = tripoint_init(updateData);
        if (err_code == NRF_SUCCESS) {
            tripoint_inited = true;
            tripoint_start_ranging(true, 10);
        }
    }
}



/*******************************************************************************
 *   INIT FUNCTIONS
 ******************************************************************************/

void initialize_app_timer (void) {
    APP_TIMER_INIT(TRITAG_TIMER_PRESCALER, TRITAG_MAX_TIMERS, TRITAG_OP_QUEUE_SIZE, false);
}

static void timers_init (void) {
    uint32_t err_code;

    err_code = app_timer_create(&app_timer,
                                APP_TIMER_MODE_REPEATED,
                                timer_handler);
    APP_ERROR_CHECK(err_code);

    err_code = app_timer_start(app_timer, UPDATE_RATE, NULL);
    APP_ERROR_CHECK(err_code);
}
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

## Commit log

2015-03-28 adding hexagon mounting plate
    [backplate_hexagon.SLDPRT, backplate_hexagon.STL]
2015-03-30 fixing initial spi speed bug
2015-03-31 fixing warnings, initial code done for time segmentation
    [dw1000.h]
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2015-04-27 adding start of atum for decawave
    [dwatum.kicad_pcb, dwatum.sch]
2015-04-27 done with schematics from what I can tell
    [dwatum.sch]
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2015-04-28 working on pcb placement
    [dwatum.kicad_pcb, dwatum.sch]
2015-04-28 most of the routing is done with dwatum
    [dwatum.kicad_pcb, dwatum.sch]
2015-04-30 adding new project for localization module
    [protopoint.sch]
2015-04-30 adding atum footprint and starting from scratch with dwatum adapter board
    [dwatum.kicad_pcb, dwatum.sch, protopoint.sch]
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2015-05-01 DW to Atum adapter board is done
    [dwatum.kicad_pcb]
2015-05-07 Start pushing time a little
    - remove printfs
    - shorten inter-sample spacing
    [polypoint_fastbaud.c]
2015-05-07 tighten print for easier debug
    [polypoint_fastbaud.c]
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2015-05-11 Looks like this was mostly cleanup stuff towards debugging the poll/fin issue
    [polypoint_common.h]
2015-05-11 WIP: Tight timing through ANC_RESP
    [polypoint_common.h]
2015-05-11 WIP: Tight through TAG_FINAL
    [polypoint_common.h]
2015-05-12 Fix initial anchor timer so that anc/tag are in step
    [polypoint_common.h]
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2015-05-13 Tight times for %ile only protocol, now ~4.5 Hz
    [polypoint_common.h]
2015-05-14 WIP: computing results
    The aot calibration estimate is causing problems. Probably too
    much variability from the start to the finish, particularly in
    the very slow-running debug mode we're currently using (~1.3 s
    between packets used for the calibration).
    Not sure if it make sense to start pushing timing a bit now to
    give this a fighting chance or rework to the protocol.
    [pp_oneway_common.h, pp_oneway_tag.c]
2015-05-15 Start tightening time; remove some magic #'s
    [pp_oneway_common.h, pp_oneway_tag.c]
2015-05-15 Fix off-by-one; remove debug prints
    [pp_oneway_tag.c]
2015-05-15 Tighten SS duration
2015-05-16 Tighten SQ rounds
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2015-05-16 tighten tag_poll
2015-05-16 Kick off anchor round on SQ boundary instead of SS boundary
    o/w too much interrupt overhead for tight timing goals
2015-05-24 Tightest anchor w/out SPI DMA
    [pp_oneway_common.h]
2015-05-25 I quit. DMA is impossible, and I do not understand why.
    This commit hacks a slightly faster path into the SPI TX, the next
    will try to do something similar for RX. Not a lot of win here
    (mostly just jitter removal between the header/body), expecting that
    RX can do a little better if we let the fifo fill.
    [dw1000.c]
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2015-05-25 Add sort, percentile support
    Also changes round re-start to start at end of last
    round instead of fixed time. Trades a little determinism
    in refresh rate for improved average performance.
    [pp_oneway_common.h, pp_oneway_tag.c]
2015-05-25 Shortcut when no packet received
    This is about the peak speed I think I'm going to reach. If no
    anchors reply (useful, I know), it runs at 34.5 ms/cycle or ~29 hz.
    If every anchor replies, I estimate it'll run ~50 ms/cycle or 20 hz.
    Places remaining to make up time:
    * Remove packet memcpy, ~90 us / anchor
    * Consider inserting on RX
    * May be net loss as it forces conservative estimate of sort time
    * Consolidate printfs, up to 1.5 ms??
    * There's overhead / call, which could be traded for code space?
    * There may be some other tricks for better shortcutting that loop
    [pp_oneway_tag.c]
2015-05-25 Skip printf, print fewer characters
    Okay. Now I'm done. For realsies.
    [pp_oneway_tag.c]
2015-05-30 pulling radio out of receive before each subsequence seems to solve a lot of issues
    [dw1000.c]
2015-05-30 adding comment regarding which contiki commit to use. Fixed minor tag issue
    [pp_oneway_tag.c]
2015-05-31 found bug in percentile calculation
    [pp_oneway_tag.c]
2015-05-31 Compute %ile based on number of valid measurements
    Fixes #1.
    [pp_oneway_common.h, pp_oneway_tag.c]
2015-06-01 Trip green LED on timing issue
    [pp_oneway_tag.c]
2015-06-01 Fix index; update print
2015-06-01 Use python logging / fix prints
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2015-06-01 Reset if timers get off
    [pp_oneway_tag.c]
2015-06-16 everything works a lot better now. Seems 16 MHz SPI speed was too close to Decawaves max 20 MHz.
    [protopoint.sch]
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2015-06-18 fixing some subsequence discrepancies
    [pp_oneway_tag.c]
2015-06-25 candidate code to fix issue 2
    [pp_oneway_common.h, pp_oneway_tag.c]
2015-06-25 almost done with schematics
    [protopoint.sch]
2015-06-25 added very very start to tag
    [star.brd, star.sch]
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2015-06-29 starting on component placement
    [protopoint.kicad_pcb, protopoint.sch]
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2015-06-29 just working to fit all components into triangle
    [protopoint.kicad_pcb]
2015-07-07 switching around pin connections for I2C instead of SPI
    [protopoint.kicad_pcb, protopoint.sch]
2015-07-08 kicad bug commit
    [protopoint.kicad_pcb, protopoint.sch]
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2015-07-10 everything now routed. Some new weird kicad issues though
    [protopoint.kicad_pcb, protopoint.sch]
2015-07-10 close to done with board
    [protopoint.kicad_pcb]
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2015-07-12 board is (electrically) ready to ship
    [protopoint.kicad_pcb]
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2015-07-13 puttin some parts down for anchor
    [anchor.brd, anchor.sch]
2015-07-13 fixed up dimensions
    [star.brd]
2015-07-14 much farther on anchor
    [anchor.brd, anchor.sch, star.brd]
2015-07-14 added some to anchor
    [anchor.brd, anchor.sch]
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2015-07-14 making castellation pattern asymmetrical and changing name of GPIO3
    [protopoint.kicad_pcb, protopoint.sch]
2015-07-14 renumbering GPIOs so that they are in order
    [protopoint.kicad_pcb, protopoint.sch]
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2015-07-14 board is basically there
    [star.brd]
2015-07-15 renamed parts, added bom
    [star.brd, star.sch, star_bom.xlsx]
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2015-07-15 fixed tenting problem
    [polytag.brd, polytag.sch, polytag_bom.xlsx]
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2015-07-15 some misc changes to anchor
    [anchor.brd, anchor.sch]
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2015-07-24 added self defined error enums to main
    [main.c]
2015-07-28 fixed spi rx error and spi pullup problem
    rx error - previous dma implementation didn't clear byte out of last
    rx buffer before continuing. fixed by setting up dma rx channel on
    both transfers and receives
    spi pullup problem - for some reason spi must pulled up on this
    chip. doing it internally now to remove external resistor.
    [dw1000.c]
2015-07-29 actually fixed spi this time
    don't deassert chip select in the middle of a transfer
    [dw1000.c]
2015-07-29 fixed DMA RX problem
    need to wait on rx done
    need to set spi rx threshold to 8 bit
    [dw1000.c]
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2015-07-29 better. something wrong with usleep though
    [dw1000.c]
2015-07-29 updated tripoint for soldering
    [protopoint.kicad_pcb, protopoint_bom.csv, protopoint_bom.xlsx]
2015-07-30 fixing some part numbers
    [protopoint.csv, protopoint.sch]
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2015-07-30 updated bom, removed old one
    [protopoint_bom.csv, protopoint_bom.xlsx]
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2015-07-31 add order quantities to bom
    [polytag_bom.xlsx]
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2015-08-01 start working on ble notify
    [anchor.sch]
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2015-08-02 fixed timer prescaler
2015-08-02 gotta keep an eye on the reset function
    [dw1000.c]
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2015-08-14 adding new project for upgraded protopoint module
    [protopoint.kicad_pcb, protopoint.sch, protopoint_bom.csv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]
2015-08-14 routing more signals out to castellations
    [protopoint.kicad_pcb, protopoint.sch]
2015-08-14 changing silkscreen version info
    [protopoint.kicad_pcb]
2015-08-14 adding support for external clock and sync
    [protopoint.kicad_pcb, protopoint.sch]
2015-08-16 make part labels legible
    [protopoint.kicad_pcb]
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2015-08-16 fixed more labels
    [protopoint.kicad_pcb]
2015-08-16 added rev b of the tag
    [tritag.brd, tritag.sch, tritag_bom.xlsx]
2015-08-16 replaced ldo
    [tritag_bom.xlsx]
2015-08-16 updated tripoint module in eagle
    [tritag.sch]
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2015-08-17 updating .h files for tripoint
    now that things are starting to solidify
    also fixed led code because we dont have any leds on tripoint
    [led.c, tripoint.h]
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2015-08-17 WIP: Preliminary commit of noslots code
    Mostly committing to push the changes.txt file out
    Current code is compile-tested, not much more. The anchore code
    is incomplete (in particular it doesn't check ACKs yet)
    [pp_noslots_common.h, pp_noslots_tag.c]
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2015-08-20 fixed interrupt pin mapping
    [tripoint.h]
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2015-08-20 update ble app to retry if tripoit init fails
    [main.c, tripoint_interface.c, tritag.h]
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2015-08-21 still working on schematics
    [pinpoint_bus_switch.sch, pinpoint_core.sch, pinpoint_edison.sch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]
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2015-08-22 almost done with core schematics
    [pinpoint_edison.sch, pinpoint_node.sch, pinpoint_serial.sch]
2015-08-22 done with pinpoint core schematics
    [pinpoint_core.sch, pinpoint_node.sch, pinpoint_serial.sch]
2015-08-22 done with schematics for pinpoint links and voids
    [pinpoint_link.sch, pinpoint_node.sch, pinpoint_power.sch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]
2015-08-23 done with all schematics and footprint association
    [pinpoint_bus_switch.sch, pinpoint_core.sch, pinpoint_edison.sch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]
2015-08-23 adding most of the range calculation code
    running into issues with code size
    [dw1000.c, dw1000.h]
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2015-08-24 starting on core layout
    [pinpoint_core.kicad_pcb]
2015-08-24 first pass at component placement and board outline. Settled on 5x5cm design
    [pinpoint_bus_switch.sch, pinpoint_core.kicad_pcb, pinpoint_core.sch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]
2015-08-24 changing USB connector to a vertical one
    [pinpoint_core.kicad_pcb, pinpoint_edison.sch]
2015-08-27 Changed tritag pins. Bluetooth range response
    Untested. Bluetooth doesn't seem to be working
    I2C to get the first range interrupt is working.
    Subsequent range interrupts are not working
    [main.c, tripoint_interface.c, tritag.h]
2015-08-27 re-init the dw1000 if it fails
    [main.c]
2015-08-27 comment out notify code temporarily
    for some reason it doesn't work
    [main.c]
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2015-09-05 fix anchor so it stops listening for slots
    the anchor would keep just waiting for tag packets if it didnt receive
    the tag's last packet
    [dw1000_anchor.c]
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2015-09-14 fix bug with sending ranges to phone
    pointers are hard
    [main.c]
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2015-09-16 wakeup and reset working
    hopefully we are at least kinda resilient to sleep failures.
    [dw1000.c, dw1000.h, main.c]
2015-09-16 more reset loops
    try to keep these things running
    [dw1000.c, main.c]
2015-09-17 rework how i2c is handled.
    should solve the no response problem
    [host_interface.c]
2015-09-17 add check to make sure we don't deadlock on int
    if dw1000 gets in "interrupt all the things!" state, we can now check
    for that and reset
    [dw1000.c, dw1000.h]
2015-09-18 remove debugging, put in checks in tag code
    need calibration
    return errors to the host if anchor fails so we can get some
    introspection
    [dw1000.c, host_interface.c]
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2015-09-21 switched to simple_ble
    removed a bunch of code that doesn't need to be copied around anymore
    [main.c]
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2015-09-23 adding brace for press-fit polypoint module calibration
    [calibration-brace.kicad_pcb, calibration-brace.sch]
2015-09-23 adding gerbers for calibration brace
    [calibration-brace.kicad_pcb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]
2015-09-23 fix issue with state machine
    reset works
    [main.c]
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2015-09-24 working on calibration
    fixed issue with where we keep track of if the dw1000 is in sleep
    [dw1000.c, dw1000.h, oneway_tag.c]
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2015-09-27 fixed array bounds issue
    reformatted notification packet
    [main.c]
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2015-09-28 update charging resistor on tritag
    [tritag.brd, tritag.sch, tritag_bom.xlsx]
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2015-09-29 added breakout board start
    [tridev.brd, tridev.sch]
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2015-09-29 added function for calibration
    and the correct places to add the offsets
    [dw1000.c, dw1000.h, oneway_common.h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]
2015-09-30 Initial calibration script; doesn't aggregate
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2015-10-01 move 3d models into better folders
    [backplate_hexagon.SLDPRT, backplate_hexagon.STL, polypoint_backplate_hexagon.STL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]
2015-10-01 rename case to something reasonable
    [tripoint_case_bottom.SLDDRW, tripoint_case_bottom.SLDPRT, tripoint_case_bottom.STL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]
2015-10-01 move more of the 3d models
    [battery_110mAh.SLDPRT, board_2d.SLDPRT, case_bottom.SLDPRT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]
2015-10-01 update case links after moves
    [tritag_case.SLDASM]
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2015-10-05 adding calibration values to firmware
    need to be copied from flash and used in the correct locations in code
    [dw1000.c, dw1000.h, insert_calibration.py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]
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2015-10-06 Re-fix calibration
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2015-10-13 fixing buffer overflow issue with ble notification
    [main.c]
2015-10-19 updated parts, added bom
    [tridev.brd, tridev.sch, tridev_bom.xlsx]
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2015-10-23 rounding corner of only 45 degree rf trace
    [protopoint.kicad_pcb]
2015-10-24 revert tridev to version that was fabbed
    [tridev.brd]
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2015-10-30 fixing probable error with rampant range estimates
    [oneway_tag.c]
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2015-12-05 fixing ANT_SEL2 init typo
    [dw1000.c]
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2016-02-10 Move DEVICE_NAME #define to fix duplicate #defines
    [main.c]
2016-02-13 An improvement upon PolyPoint's previous localization consistency and performance. First, waking DW1000 from sleep greatly hinders its immediate RX performance, so all DW1000 sleep code has been remo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
    [oneway_common.h, oneway_tag.c]
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2016-02-20 working on timebase schematic. Jitter cleaner is the only thing left to include
    [pinpoint_timebase.sch]
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2016-02-21 adding adapter board to test PinPoint with TriDev board
    [pinpoint_tridev_adapter.kicad_pcb, pinpoint_tridev_adapter.sch]
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2016-02-21 minor cosmetic fixes
    [pinpoint_timebase.kicad_pcb, pinpoint_tridev_adapter.kicad_pcb]
2016-02-21 adding gerbers for pinpoint timebase and pinpoint to tridev adapter baord
    [pinpoint_timebase-B.Cu.gbr, pinpoint_timebase-B.Mask.gbr, pinpoint_timebase-B.SilkS.gbr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]
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2016-02-22 starting at a clean slate for tripoint calibration data now that the calibration process has been fixed
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2016-03-26 fixing bugs introduced from migrating to scratchspace utilization
    [main.c, oneway_tag.c]
2016-03-26 fixing integer overflow bugs in code committed last night
    [dw1000.c, oneway_common.h]
2016-03-26 fixing a couple mistakes in git master rebase
    [oneway_tag.c]
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2016-04-02 fixing transmit counter overflow issues
    [glossy.c]
2016-04-02 schedule requests now work correctly
    [glossy.c]
2016-04-02 fixing ack bugs in anchor response windows
    [glossy.c, main.c]
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2016-04-03 candidate fix for timestamp overflow issues
    [dw1000.c, dw1000.h, oneway_tag.c]
2016-04-03 adding code which correctly reads in uart logging output
2016-04-03 holy crap, the channel index is still wrong after all this time
    [oneway_tag.c]
2016-04-04 real rxoverrun issue fixed
    [dw1000.c]
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2016-04-06 bug in re-initialization of anchor after a glossy sync
    [glossy.c]
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2016-04-06 Add PID option to short set ID
2016-04-07 Try playing with competiting solvers
    The thought is to run both solvers iteratively and then run them
    again using only the common set of kept ranges. This did not really
    give as much benefit as one would have hoped and isn't really worth
    doing. Error matrix:
    bfgs_iter lst_sq_iter bfgs2 lst_sq2 final
    50%ile [ 0.33030506 0.33209211 0.33030506 0.33030487 0.33030506]
    90%ile [ 0.63111162 0.68856695 0.60951943 0.60951944 0.60951943]
    95%ile [ 2.10710286 2.09472289 2.05820995 2.05821013 2.05820995]
    [data_dump_glossy.py]
2016-04-07 fixing lots of bugs that were plaguing polypoint tests
    [data_dump_glossy.py, glossy.c, oneway_tag.c]
2016-04-08 Skip useless processing; add calibration
    [data_dump_glossy.py]
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2016-09-01 fixing reliability issues in scheduleing and crystal offset compensation
    [glossy.c]
2016-09-03 getting closer to correct glossy measurements, just need to incorporate real calibration data
    [glossy.c, polypoint_conf.h, timer.c]
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2016-09-09 bugfixes for auto disconnect
    [glossy.c, oneway_tag.c]
2016-09-16 timer_reset bug introduced from glossy sync fixes
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

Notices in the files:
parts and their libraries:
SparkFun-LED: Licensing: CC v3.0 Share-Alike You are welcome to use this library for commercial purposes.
